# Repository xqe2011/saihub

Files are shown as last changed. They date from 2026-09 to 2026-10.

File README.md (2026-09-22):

<h1 align="center">
  SAIHub robot SAIHub
</h1>

<p align="center">
  counter
</p>

<p align="center"><strong>Give your agent a hand.</strong></p>

<p align="center">
  An MIT-licensed, agent-ready IO board.<br>
  ESP32-C5 firmware that speaks <a href="https://modelcontextprotocol.io/">MCP</a>,
  so Cursor, Claude Code, and Codex can drive real hardware.
</p>

<p align="center">
  <a href="README.zh.md">中文</a>
  · <a href="docs/cookbook.md">Cookbook</a>
  · <a href="docs/hardware.md">Hardware</a>
  · <a href="docs/design-notes.md">Protocol</a>
  · <a href="docs/build.md">Build</a>
  · <a href="https://github.com/xqe2011/saihub/releases">Releases</a>
  · <a href="LICENSE">MIT</a>
</p>

---

## What it is

SAIHub is a pocket IO companion for coding agents. Flash it, join Wi-Fi, paste an MCP URL, and the agent gets a hand on real hardware:

- **GPIO / PWM / programmable power** — toggle pins, generate PWM up to 50 kHz, capture edges like a logic analyzer, and switch the 3.3 V / 5 V rails on and off, all over MCP.
- **On-device scripting** — the agent can upload Lua scripts and run them on the board itself, so timing-critical or multi-step logic executes locally without a round-trip per pin.

The board is **SAIHub-Mini**: 48 × 28 mm, ESP32-C5, USB-C, a BOOT button, a 12-pin header, and an external U.FL antenna. Pinout and electrical details: [docs/hardware.md](docs/hardware.md). Firmware, KiCad design, and the relay server all live in this repo.

You do not have to use our board — the firmware runs on any ESP32-C5. See [bring your own board](docs/bring-your-own-board.md) for what changes and where to remap the GPIOs.

## What you can do with it

**Buy an agent a hand.** Drop SAIHub next to a DUT and let the agent debug a real embedded board: drive GPIO, generate PWM, capture traces, and speak UART instead of asking you to probe every line.

**An agent-ready IO board.** The simplest way to hang other IO off an agent:

- Sweep a **servo** from a Lua script while the agent watches the mechanism.
- Dim a **light** or blink a status LED over PWM.
- Close an **electromagnetic relay** to switch a pump, a lock, or a heater.
- Power a 3.3 V sensor from the switched rail, then read it over UART or GPIO.

## Quick start

The [cookbook](docs/cookbook.md) walks through every step:

1. Download the firmware `.bin` from [Releases](https://github.com/xqe2011/saihub/releases) and flash it with the [ESP web flasher](https://espressif.github.io/esptool-js/).
2. Click **BOOT** to open Wi-Fi pairing, join the `SAIHUB-xxxxxx` AP, and pick your network.
3. Point Cursor / Claude Code / Codex CLI at `http://<device-ip>/mcp`. The agent now has a hand on your bench.

## Ways to connect

The LAN URL is all you need at the bench. To reach the board from anywhere, put a relay in front of it — our managed cloud, or one you deploy yourself:

| | Local LAN | Self-hosted relay | Managed cloud |
| --- | --- | --- | --- |
| Best for | Bench work, zero setup | Remote access under your own account | Remote access, zero ops |
| MCP URL | `http://<device-ip>/mcp` | `https://<your-worker>/device/<digest>/mcp` | `https://saihub.xqe2011.com/device/<digest>/mcp` |
| Reach | Same LAN only | Anywhere | Anywhere |
| Setup | None after Wi-Fi | Deploy to Cloudflare then rebuild firmware with your origin ([details](docs/cookbook.md#5-self-host-the-cloudflare-relay)) | None — boards bought from us connect to the managed cloud |
| Auth | None (LAN trust) | OAuth through your relay | OAuth in the browser |
| Traffic path | Direct to the board | Through your Cloudflare account | Through our infrastructure |
| Cost | Free | Cloudflare free tier | Included with the board |

After the board authenticates with the relay, the serial log prints its landing page — `https://<origin>/cloud/landing/<digest>/page` — with live online status, copyable MCP or REST/OpenAPI URLs, and a button to mint a authentication token.

The relay protocol is server-agnostic — the Cloudflare Worker in this repo is the reference implementation ([design notes](docs/design-notes.md)).

## No vendor lock-in

Nothing here ties you to us:

- **Any ESP32-C5 board works.** SAIHub-Mini is just one carrier; an off-the-shelf DevKit or your own PCB runs the same firmware. See [bring your own board](docs/bring-your-own-board.md).
- **You don't need our managed cloud.** The relay is a Cloudflare Worker you can deploy under your own account — or replace entirely, since the protocol is documented and server-agnostic.
- **Everything is open source under MIT.** Firmware, KiCad hardware design, and the cloud relay all live in this repo.
- **LAN mode needs no service at all.** Wi-Fi plus the local MCP URL is a complete setup; the cloud is optional convenience, not a requirement.

## Capabilities

| Area | What the agent gets |
| --- | --- |
| GPIO 0–7 | Digital in / out / open-drain, pulse, PWM up to 50 kHz |
| Trace | Edge capture on one or more pins (up to 60 s) |
| UART | One product UART, UTF-8 or raw bytes |
| Power | Switched **3V3** and **5V** rails (off by default) |
| Scripts | Sandboxed Lua 5.4 on-device |
| Access | Streamable HTTP MCP on port 80, REST + OpenAPI, optional cloud relay |

Logic pins are **3.3 V only** — full electrical limits in [docs/hardware.md](docs/hardware.md).

## Repo layout

| Path | What |
| --- | --- |
| `main/` | ESP-IDF firmware (ESP32-C5, IDF ≥ 5.5) |
| `mcp.json` | MCP tool schema served by the device |
| `openapi.json` | REST API for the same tools |
| `cloud/cloudflare/` | Cloudflare Worker relay + OAuth (reference server) |
| `hardware/` | SAIHub-Mini KiCad project |
| `docs/` | Cookbook, hardware, build, protocol, and BYO-board docs |

## License

[MIT](LICENSE).

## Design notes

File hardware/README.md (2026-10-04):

# SAIHub-Mini — Rev A

Version: **2026-09-24**. Author: **GPT6-Astra**. Co-author: **xqe2011**.

The date version changes only with explicit user permission. See [the version log](docs/version-log.md); regeneration and exports preserve the approved version.

**Current state: routed and CAD-validated.** Electrical, layout, schematic-parity and connectivity checks pass. Prototype testing is still required.

Editable KiCad 10 design for the SAIHub IO controller. Open `saihub.kicad_pro`; symbols and footprints are project-local. The schematic is one A2 page with eight functional sections.

The PCB remains **48 × 28 mm**, with 65 footprints: 56 on top, eight resistors and the TP3 test pad on the back. Across the front edge, left to right: **12-pin header → BOOT button → USB-C**. Connector pins and the switch actuator project beyond the PCB outline.

SW1 is **TS-2435VS, C47734518**, a side-push switch without locating posts. Its local footprint follows the manufacturer's recommended stepped mounting lands and two electrical contacts. The actuator faces the connector edge.

The **16 × 24 mm module has a built-in PCB antenna at the bottom-left corner**. Its body spans x=0.85–16.85 mm and y=4–28 mm. An open notch removes the board beneath the antenna at y=20.5–28 mm and x=0–21.85 mm: it opens to the left and bottom edges and leaves **5 mm to the antenna's right**. The 0.85 mm body inset at the left preserves solder-land and copper-edge clearance beside the module's connected section. No board material or copper remains beneath the antenna. Enclosure clearance still needs verification.

The 5 V / 3 A input, nominal 1 A output protection, regulator and buzzer are retained. IO3 and IO7 now use internal pins 2 and 7; the firmware mapping changes with this board. Earlier hardware must use its matching firmware mapping.

## Files

- `saihub.kicad_pro`, `saihub.kicad_sch`, `saihub.kicad_pcb`: open the project in KiCad 10 to edit the current design.
- `libraries/`, `sym-lib-table`, `fp-lib-table`: project-local symbols and footprints required by KiCad.
- `docs/bom.csv`: current procurement BOM; excludes test pads; no external antenna accessory is required.
- `docs/bom.html`: self-contained interactive assembly BOM from [InteractiveHtmlBom](https://github.com/openscopeproject/InteractiveHtmlBom), with component lookup, MPNs, copper and net highlighting. Test pads are visible on the board but excluded from the BOM table.
- `docs/schematic.pdf`: schematic review.
- `docs/pcb.pdf`: top and mirrored bottom PCB previews, including silkscreen designators.
- `docs/shell.pdf`: enclosure previews with/without the board, dimensioned views and ABS mass estimate; refresh after every PCB change.
- `mechanical/`: editable build123d enclosure, board reference, STEP/STL exports and drawing generators; see [the mechanical guide](mechanical/README.md).
- `docs/version-log.md`: approved version and permission policy.
- `agent/`: regeneration scripts, design metadata, design notes, validation evidence, routing intermediates and reusable workflow skills.

Current validation and routing inputs are retained in Git. `agent/previews/` contains regenerable images and is ignored; the review PDFs are committed. KiCad local history, locks, backups and personal settings are also ignored.

**Prototype status:** CAD checks pass; the board has not been fabricated or bench tested. Verify thermal behavior, supply loading and USB operation using `agent/docs/prototype-test.md`. The 26.1 kΩ ILIM resistors set approximately 0.989 A nominal, with 0.908–1.081 A bounds including resistor tolerance; a guaranteed 1 A continuous rating is not implied.

## Connections

J2 pin 1 is square and marked `3V3`. Looking at the top with the connector edge at the top, pins run left to right:

`1:3V3_SW  2:GND  3:5V_SW  4:GND  5:IO0  6:IO1  7:IO2  8:IO3  9:IO4  10:IO5  11:IO6  12:IO7`

IO0-IO7 map to GPIO **10, 1, 0, 2, 4, 5, 6, 7**. Logic pins are **3.3 V only**; the 1 A setting applies to the two power channels. GPIO8 enables 3.3 V output and GPIO9 enables 5 V output. Both default off. Do not back-power either rail. The 5 V output follows USB voltage minus fuse, trace and switch losses.

Four LEDs form one top-side column, with matching shell openings and recessed labels:
**3V3 OUT** and **5V OUT** are green and monitor the switched outputs; **5V IN** is red
and monitors input power after the fuse; **STATUS** is blue and connects to control
pin 26 (active high). The blue indicator requires firmware control; no behavior is
assigned by this hardware change. R7-R10 and R19-R22 are assembled on the back.

GPIO12 drives the passive 5020 buzzer at 4 kHz / 50% duty. GPIO13/14 carry USB D-/D+. BOOT is GPIO28. TP1/TP2 are EN/GND reset pads on the top: briefly short them to reset. Hold BOOT during reset/power-on for download recovery. TP3 is UART TX on the back, TP4 always-on 3.3 V, and TP5/TP6 active-low switch fault outputs.

Use a specified **5 V / 3 A adapter and cable** for external loads. Keep outputs off on unqualified PC ports. No PD, OTG or source-current detection is implemented. The antenna is built into the module. See `agent/docs/design-notes.md` for SGM6232 input-voltage margin and sourcing status.

## Rebuilding

Normal edits can be made in KiCad. From the repository root, run:

```sh
export INTERACTIVE_HTML_BOM=/path/to/InteractiveHtmlBom/InteractiveHtmlBom/generate_interactive_bom.py
python3 hardware/agent/scripts/export_placement.py --routed
```

The command synchronizes board metadata, requires zero ERC/DRC/parity findings and zero unconnected items, then refreshes the five files in `docs/`, including `shell.pdf`. It requires KiCad 10, ImageMagick and Python `reportlab` (`python3 -m pip install reportlab`). Set `KICAD_CLI` and `KICAD_PYTHON` to override the macOS tool defaults; the latter must provide `pcbnew`. Poppler is optional for the separate schematic PNG. Clone [InteractiveHtmlBom](https://github.com/openscopeproject/InteractiveHtmlBom) and set `INTERACTIVE_HTML_BOM` as above (validated at commit `5c192e794cd66fde04bab11810601b711bf8581b`). On macOS, its generator requires a logged-in desktop session. `agent/scripts/export_ibom.py` can refresh only `docs/bom.html`.

`agent/scripts/export_docs.py` refreshes the review documents and the enclosure reference/exports, without modifying the board or schematic. It runs the enclosure geometry checks but does not replace electrical CAD validation. Install `mechanical/requirements.txt` into `mechanical/.venv`, or set `MECHANICAL_PYTHON` to that environment. Every PCB update requires reconciling the enclosure parameters and regenerating `docs/shell.pdf`; the document exporter calls `mechanical/refresh_shell.py` automatically and fails if that refresh fails. `agent/scripts/export.py` separately validates and exports fabrication files into `manufacturing/`.

For regeneration and routing, read [the project workflow skill](agent/skills/kicad-workflow/SKILL.md). `generate.py` writes the separate `agent/routing/saihub-unrouted.kicad_pcb`; it preserves the main routed PCB but regenerates the schematic and libraries while preserving existing project settings. The indicator layout uses `replay_routing.py` and its placement-checked copper snapshot; legacy SES routing is tied to the earlier placement.

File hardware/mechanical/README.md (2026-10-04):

# SAIHub-Mini enclosure

Parametric **build123d** base and cover for the current 48 × 28 × 1.6 mm board.
The cover uses a monochrome layout with a left-aligned Helvetica wordmark,
smaller MINI model line, and a blank QR sticker bed in the frame at upper right.
The top remains continuous over USB and the button, with four indicator openings nearby. USB and button access is through the side only
and no USB/button text labels.
All 12 connector labels share a baseline along the connector edge.
Each connector label is rotated 90° and centred on its physical 2.54 mm pin pitch,
so power and ground labels use the same column width as the numbers. All dimensions are in mm.

## Generate

From this directory, using Python 3.12:

```sh
python3.12 -m venv .venv
.venv/bin/python -m pip install -r requirements.txt
.venv/bin/python enclosure.py --preview
```

`output/` contains separate `base.step`, `cover.step`, `base.stl`, `cover.stl`,
an assembled `assembly.step`, a `fit-reference.step` with the populated board reference,
`validation.json`, and `preview.png`. The STEP and STL parts retain assembled
coordinates. Generate with `--output PATH` to select another export directory.

## Geometry

- Overall assembled envelope: **50.4 × 30.4 × 9 mm**.
- Ordinary side walls, floor, and cover face: **1 mm**.
- Exterior plan corners: **1.5 mm radius**, with matching nested profiles and a
  **0.3 mm** softened top perimeter. Wall dimensions describe straight sections;
  the top edge blend locally rounds the nominal roof thickness.
- The compact nesting joint uses a **1 mm cover lip** inside the **1 mm base
  wall**, with **0.2 mm** sliding clearance per side. It starts at **z = 6.5 mm**,
  above the board, with local edge-component clearance checked, instead of
  adding width beside the board.
- Lip overlap: **1 mm**; cover seats at **z = 7.5 mm**. Two opposed side snaps
  provide vertical retention with **0.25 mm** engagement and **0.2 mm** vertical
  play. Each free arm is **7.5 × 0.6 × 1.2 mm** with a ramped hook and **0.4 mm**
  clearance above it. Press the hooks through both side windows to release.
  Snap force, fatigue and print tolerances require prototype testing.
- Board side clearance: **0.2 mm**. The board rests **1.8 mm** above the floor for
  solder tails. Four short edge ledges support it, surrounding walls locate it,
  and ceiling fingers limit lift to **0.3 mm**. The board notch has no support below it.
- The footprint follows `48 + 2 × (1 + 0.2)` by `28 + 2 × (1 + 0.2)`.
  The smaller **1.5 mm** outer corner radius preserves clearance around the square
  board corners. The face layout is inset to suit the smaller shell.
- Component space above the PCB: **3.6 mm** to the continuous roof, apart from
  the nesting lip and edge fingers. The available USB model is taller than the
  stated 2.54 mm component height; its top has **0.295 mm** roof clearance.
  Body height is **9 mm**; the QR outline is recessed **0.3 mm**. The top is closed except for the four indicator openings,
  with **1 mm** nominal roof thickness and **0.7 mm** below recessed lettering.
- Bottom allowance is based on the available connector model: its tails extend
  about **1.405 mm** below the board, leaving approximately **0.395 mm** to the
  floor. Verify actual solder joints and trim tails if necessary.
- QR intaglio outline: **22.36 × 22.36 mm outside**, **22 × 22 mm square inside**, **0.18 mm wide
  along the straight edges and recessed 0.3 mm**, with rounded outer corners and
  **0.7 mm** of roof remaining below the groove. The border width matches the
  approximately 0.177 mm stems of the 1.8 mm regular lettering.
  The sticker bed is flat, flush with the cover face, and has no text. All labels are **recessed 0.3 mm**, leaving **0.7 mm** of roof below the lettering.

## Board alignment and prototype checks

Dimensions and connector locations come from `../saihub.kicad_pcb` and
`../agent/validation/parts-placement.csv`. The board is rotated in the face view
so that USB is on the left: board `(x, y)` becomes model `(48 - x, y)`.
The front connector edge is model `y = 0`; the base bottom is `z = 0`.
USB and button side-opening centres are **6.4 mm** and **14.7 mm** from the
left exterior edge. Their openings are **10.4 × 4.2 mm** and **5 × 3 mm**
respectively, with internal relief for the connector bodies. Neither opening
pierces the roof. The 12-contact header side opening is **31.5 × 3.9 mm**,
extending to the seam so no fragile strip remains above it on the base.
The pin labels remain recessed into the continuous roof above it.
The labels follow actual connector positions. Reading left to right in the cover
face view: **8, 7, 6, 5, 4, 3, 2, 1, GND, 5V, GND, 3.3V**. Channels **1–8**
correspond to the board's **IO0–IO7**; they are channel labels, not physical pin
numbers. Power and ground use the same 90° rotation as the numeric labels.

The generator checks solid validity, connectedness, shell-to-shell interference,
and interference with the actual notched board envelope. The exploded preview
also shows the populated board between the shell halves, in the same XY alignment.
`reference/pcb.step` is an export of the committed board with pads and available
component models. The button and module use explicitly named simplified envelopes
because their footprints have no supplied models; their heights are illustrative.
Other missing component models and solder are not reconstructed. This visual
reference is not a complete component-clearance certification. Before production, print a fit
sample and verify component heights, solder tails, edge finger clearance,
cable overmould access, mating-header clearance, button access, lid
retention, and wireless operation. Use nonconductive plastic.

Print the base floor down. The cover has recessed details on its flat top face and lips/snaps underneath;
choose supports and orientation in the slicer to preserve the engraved details. Start with a fine layer height for the small
labels. The preview is rendered directly from the generated solids in neutral
grey, with darker recessed lettering and frame for legibility; it does not specify separate print colours.

To refresh the board reference after board edits, from this directory:

```sh
kicad-cli pcb export step --force --subst-models --include-pads --user-origin 0x0mm \
  -o reference/pcb.step ../saihub.kicad_pcb
.venv/bin/python enclosure.py --preview
```

The exporter uses board-bottom `z=0` and negated board Y. The generator rotates
it 180° around Z and translates it to `(48, 0, 2.8)` to match the enclosure.

Build123d export API reference:
[Import/Export](https://build123d.readthedocs.io/en/latest/import_export.html).

## Dimensioned PDF

The hardware review document `../docs/shell.pdf` contains exploded previews with and
without the PCB, top/front/right views with dimensions, and an ABS mass estimate.
Regenerate it after changing the enclosure:

```sh
.venv/bin/python render_shell_docs.py --output /tmp/saihub-shell-pdf
.venv/bin/python export_shell_pdf.py --assets /tmp/saihub-shell-pdf
```

The drawing uses a 3:1 orthographic scale when printed at 100%. Dimensions govern.
The PDF recomputes the ABS mass from current CAD material volumes at **1.04 g/cm3**,
using the linked manufacturer data sheet. Filled thin walls are assumed; supports,
brim, purge, electronics and sticker are excluded. Confirm consumption with the
intended slicer settings.

## Required refresh after PCB changes

The canonical PDF is **`hardware/docs/shell.pdf`**, never the repository-level
`docs/shell.pdf` or `hardware/shell.pdf`. PCB edits require checking the explicit
board dimensions, connector centres/heights, supports, snap paths and illustrative
component envelopes in `enclosure.py`; these do not adapt automatically to a new
board layout. Update drawing callouts if the geometry changes.

After reconciling those inputs, from this directory run:

```sh
.venv/bin/python refresh_shell.py
```

This exports a fresh board reference, regenerates the enclosure exports/preview,
checks board/component and snap insertion geometry, regenerates all drawing views,
and recomputes the mass in `../docs/shell.pdf`. A failure stops the refresh instead
of publishing a new PDF. `--pdf-python /path/to/python` may select a separate
Python environment with ReportLab. `KICAD_CLI` selects the board export executable.
The hardware document exporter invokes this command automatically; select its
CAD environment with `MECHANICAL_PYTHON` if not using `mechanical/.venv`.

Render every page of the resulting PDF and visually inspect the images before
reporting completion. Geometry checks do not validate missing models, solder,
material strength or printed snap retention. Do not change board revision/date
metadata just to refresh these documents.

## Indicator bank

The four top-side LEDs remain together at board x=30.3 mm, y=5.2/8.4/11.6/14.8 mm.
The shell takes these positions directly from `agent/design.json`. Each has a
1.5 mm circular viewing opening and a separate 2.2 mm outside-diameter light well,
with 0.4 mm clearance above the nominal 0.55 mm LED body. Recessed labels read
`3V3 OUT`, `5V OUT`, `5V IN`, and `STATUS`; the first two are green, then red and blue.
The QR sticker area remains blank. The eight bottom resistors fit inside the
existing solder-tail allowance. Verify visibility, light bleed and resistor/solder
clearance on a physical prototype.

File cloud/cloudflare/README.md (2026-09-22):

# SAIHub cloud relay

Cloudflare Worker that proxies MCP and REST to a SAIHub board.

Deploy to Cloudflare (https://deploy.workers.cloudflare.com/?url=https://github.com/xqe2011/saihub/tree/main/cloud/cloudflare)

Deploy provisions D1 (`DB`), the `DEVICE` Durable Object, `AUTH_TIMEOUT_MS` / `REQUEST_TIMEOUT_MS`, and the `ROUTING_TOKEN_SECRET` / `ADMIN_TOKEN` secrets from `.dev.vars.example`. Generate each secret with `openssl rand -hex 32`. The deploy script applies D1 migrations, then publishes the worker.

Local development:

```bash
cp .dev.vars.example .dev.vars
npm install
npm run dev
```

Then open `/admin` on the worker origin, enter `ADMIN_TOKEN`, and whitelist each device digest.

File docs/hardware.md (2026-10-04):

# SAIHub-Mini hardware

> **Tip:** Experimental board designed by GPT-6 Astra; still under evaluation. Use at your own risk.

A 48 × 28 mm, two-layer IO board: USB-C, one BOOT button, a 12-pin right-angle header, and a built-in PCB antenna. The main components and four indicators are on top; eight resistors are assembled on the back.

[中文](hardware.zh.md) · [README](../README.md) · [Cookbook](cookbook.md) · [Bring your own board](bring-your-own-board.md) · [KiCad project](../hardware/README.md)

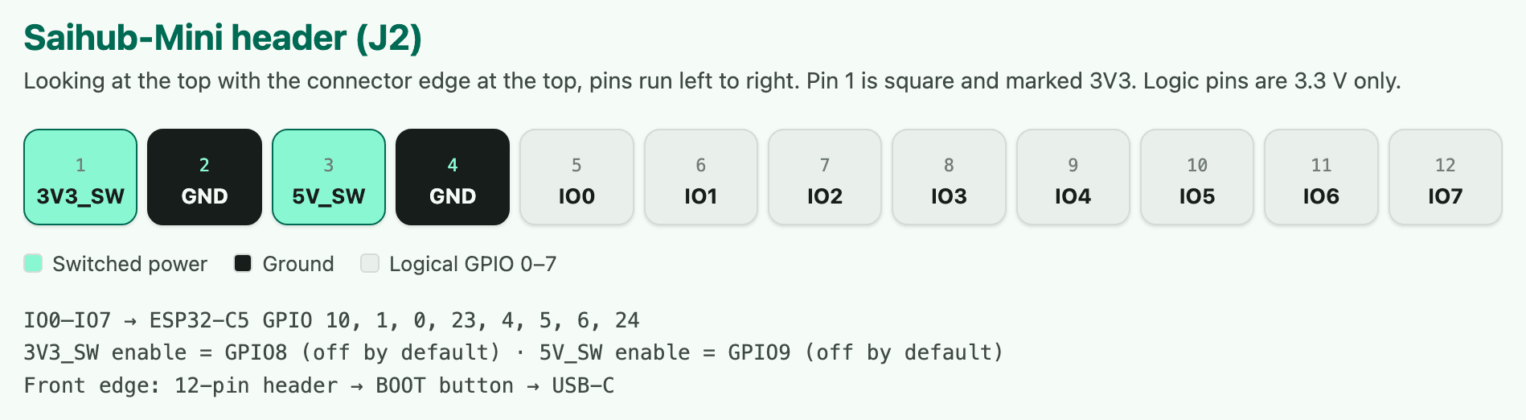
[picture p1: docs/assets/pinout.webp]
SAIHub-Mini J2 header pinout


## Front edge

Left to right: **12-pin header (J2) → BOOT button → USB-C**. The board width follows these three footprints plus assembly clearances; the connector pins and switch actuator project beyond the outline.

## J2 pinout

Pin 1 is square and marked `3V3`. Looking at the top with the connector edge up, pins run left to right:

| Pin | Name | Internal pin | Notes |
| --- | --- | --- | --- |
| 1 | 3V3_SW | — | Switched 3.3 V output, enabled by GPIO8, **off by default** |
| 2 | GND | — | |
| 3 | 5V_SW | — | Switched 5 V output, enabled by GPIO9, **off by default** |
| 4 | GND | — | |
| 5 | IO0 | GPIO10 | 3.3 V logic |
| 6 | IO1 | GPIO1 | 3.3 V logic |
| 7 | IO2 | GPIO0 | 3.3 V logic |
| 8 | IO3 | GPIO2 | 3.3 V logic |
| 9 | IO4 | GPIO4 | 3.3 V logic |
| 10 | IO5 | GPIO5 | 3.3 V logic |
| 11 | IO6 | GPIO6 | 3.3 V logic |
| 12 | IO7 | GPIO7 | 3.3 V logic |

Agents drive these through the MCP / REST tools; the mapping lives in firmware `CONFIG_GPIO_LOGICAL_TO_HW` (`main/include/config.h`).

## Power

- **Input**: 5 V / 3 A over USB-C, protected by a 3 A fast fuse and TVS. No PD, no OTG, no source-current detection — just 5.1 kΩ CC pulldowns.
- **3.3 V rail**: SGM6232 buck converter; also feeds an always-on 3.3 V at TP4.
- **Switched outputs**: two TPS2553 power switches feed **3V3_SW** and **5V_SW**. GPIO8 / GPIO9 enable them; both default off and the agent toggles them with `set_output_power_state`.
- **Output protection**: 26.1 kΩ ILIM resistors set a nominal ~1 A limit per channel (0.989 A calculated, 0.908–1.081 A including resistor tolerance). This is a protection threshold, **not a guaranteed continuous 1 A rating**.
- **5V_SW** follows the USB input voltage minus fuse, trace, and switch losses.
- Use a **5 V / 3 A adapter and cable** for external loads; keep outputs off on unqualified USB ports.

## Electrical rules

- Logic pins are **3.3 V only**.
- **Do not back-power** either switched rail.
- Mains voltage belongs on external relay contacts only — never on SAIHub pins.

## Button and test points

| Item | Function |
| --- | --- |
| BOOT (SW1, GPIO28) | Click once while running: Wi-Fi pairing. Hold during reset / power-on: ROM download mode |
| TP1 / TP2 | EN / GND reset pads (top). Short briefly to reset |
| TP3 | Console UART TX (GPIO11, 115200 baud), back-side test pad — firmware logs |
| TP4 | Always-on 3.3 V |
| TP5 / TP6 | Active-low fault outputs of the two power switches |

SW1 is TS-2435VS (C47734518), a side-push switch without locating posts. The actuator faces the connector edge.

## UART

- UART0 is reserved for the console (logs on TP3).
- The product UART exposed to agents is UART1, routed through the GPIO matrix to any of IO0–IO7 and configured at runtime with `configure_uart`.

## Other onboard parts

- Four indicators in one column: green **3V3 OUT** and **5V OUT** monitor switched outputs, red **5V IN** monitors input power after the fuse, and blue **STATUS** connects to control pin 26. STATUS requires firmware control; this hardware change assigns no behavior.
- Passive 5020 buzzer on GPIO12 (driven at 4 kHz / 50 % duty).
- Native USB on GPIO13 / GPIO14 (D- / D+), with USBLC6-2SC6 ESD protection.
- 16 × 24 mm module with built-in PCB antenna and 4 MB flash.

## Antenna

The built-in antenna sits at the bottom-left corner, above an open board cutout. The cutout reaches the left and bottom edges and extends 5 mm to the antenna’s right. Overall PCB dimensions stay 48 × 28 mm. IO3 and IO7 use new internal pin assignments; use the firmware mapping committed with this board.

## Design files and status

KiCad 10 project, procurement BOM, schematic, PCB and enclosure review PDFs: [`hardware/`](../hardware/README.md). Editable enclosure models and STEP/STL exports are in [`hardware/mechanical/`](../hardware/mechanical/README.md).

**Prototype status**: the replacement layout passes CAD checks; it has not been fabricated or bench tested. Thermal behavior, supply loading, and USB operation still need verification — see `hardware/agent/docs/prototype-test.md`.

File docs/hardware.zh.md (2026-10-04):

# SAIHub-Mini 硬件文档

> **提示：** 本板由 GPT-6 Astra 设计，目前仍在测试中，请自行承担使用风险。

一块 48 × 28 mm 的双层 IO 板：USB-C 接口、一个 BOOT 按键、一排 12 针直角排针，内置 PCB 天线。主要元件和四个指示灯位于顶层，八个电阻贴装在背面。

[English](hardware.md) · [README](../README.zh.md) · [使用手册](cookbook.zh.md) · [自备开发板](bring-your-own-board.zh.md) · [KiCad 工程](../hardware/README.md)

SAIHub-Mini J2 排针定义

## 板子前缘

从左到右依次是：**12 针排针（J2）→ BOOT 按键 → USB-C**。板宽由这三个器件加装配间隙决定；排针和按键帽会超出板框。

## J2 引脚定义

第 1 脚为方孔焊盘，丝印标注 `3V3`。俯视板子、排针朝上时，引脚从左到右依次为：

| 引脚 | 名称 | Internal pin | 说明 |
| --- | --- | --- | --- |
| 1 | 3V3_SW | — | 可控 3.3 V 输出，GPIO8 使能，**默认关闭** |
| 2 | GND | — | |
| 3 | 5V_SW | — | 可控 5 V 输出，GPIO9 使能，**默认关闭** |
| 4 | GND | — | |
| 5 | IO0 | GPIO10 | 3.3 V 逻辑电平 |
| 6 | IO1 | GPIO1 | 3.3 V 逻辑电平 |
| 7 | IO2 | GPIO0 | 3.3 V 逻辑电平 |
| 8 | IO3 | GPIO2 | 3.3 V 逻辑电平 |
| 9 | IO4 | GPIO4 | 3.3 V 逻辑电平 |
| 10 | IO5 | GPIO5 | 3.3 V 逻辑电平 |
| 11 | IO6 | GPIO6 | 3.3 V 逻辑电平 |
| 12 | IO7 | GPIO7 | 3.3 V 逻辑电平 |

智能体通过 MCP / REST 工具操作这些引脚；映射关系固化在固件的 `CONFIG_GPIO_LOGICAL_TO_HW`（`main/include/config.h`）中。

## 电源

- **输入**：USB-C 5 V / 3 A，前端有 3 A 快断保险丝和 TVS 保护。不支持 PD、OTG，也没有源电流检测，CC 脚只接了 5.1 kΩ 下拉。
- **3.3 V 主电源**：SGM6232 降压芯片；TP4 上还有常供电的 3.3 V。
- **可控输出**：两路 TPS2553 电源开关分别驱动 **3V3_SW** 和 **5V_SW**，由 GPIO8 / GPIO9 使能。默认都是关闭的，智能体用 `set_output_power_state` 工具开关。
- **输出保护**：ILIM 电阻 26.1 kΩ，每路限流标称约 1 A（计算值 0.989 A，计入电阻公差为 0.908–1.081 A）。这是保护阈值，**不保证能持续输出 1 A**。
- **5V_SW** 电压等于 USB 输入电压减去保险丝、走线和开关的压降。
- 带实际负载时请使用 **5 V / 3 A 的适配器和线缆**；接入不确定的 USB 口时，先关闭电源输出。

## 电气红线

- 逻辑引脚**仅支持 3.3 V**。
- **禁止**从外部向任一可控电源轨倒灌。
- 市电只能走外接继电器的触点，绝不能接到 SAIHub 引脚上。

## 按键与测试点

| 位置 | 功能 |
| --- | --- |
| BOOT（SW1，GPIO28） | 运行中按一下：开启 Wi-Fi 配对；复位 / 上电时按住：进入 ROM 下载模式 |
| TP1 / TP2 | EN / GND 复位焊盘（板顶），短接一下即复位 |
| TP3 | 背面测试点，控制台 UART TX（GPIO11，115200 波特率），输出固件日志 |
| TP4 | 常供 3.3 V |
| TP5 / TP6 | 两路电源开关的低有效故障输出 |

SW1 采用 TS-2435VS（C47734518），无定位柱，侧按，朝向接口边缘。

## UART

- UART0 保留作控制台（日志从 TP3 输出）。
- 提供给智能体的产品 UART 是 UART1，经 GPIO 交换矩阵可以路由到 IO0–IO7 中任意两脚，运行时用 `configure_uart` 配置。

## 其他板载器件

- 四个指示灯排成一列：绿色 **3V3 OUT** 和 **5V OUT** 监测可控输出，红色 **5V IN** 监测保险丝后的输入电源，蓝色 **STATUS** 连接控制引脚 26。STATUS 需要固件控制，本次硬件变更未定义其行为。
- GPIO12 驱动 5020 无源蜂鸣器（4 kHz / 50% 占空比）。
- 原生 USB 走 GPIO13 / GPIO14（D- / D+），带 USBLC6-2SC6 ESD 保护。
- 16 × 24 mm 模组，内置 PCB 天线，4 MB Flash。

## 天线

内置天线位于左下角，天线下方挖空，缺口连通左边和底边，并向天线右侧延伸 5 mm。PCB 外形尺寸仍为 48 × 28 mm。IO3 和 IO7 的内部引脚映射已更新，请使用与本板配套的固件映射。

## 设计文件与状态

KiCad 10 工程、采购 BOM、原理图、PCB 和外壳审阅 PDF 见 [`hardware/`](../hardware/README.md)。可编辑外壳模型及 STEP/STL 导出文件见 [`hardware/mechanical/`](../hardware/mechanical/README.md)。

**打样状态**：更换器件后的布局已通过 CAD 检查，尚未打样和上电实测。热性能、供电负载和 USB 工作情况还需验证，详见 `hardware/agent/docs/prototype-test.md`。

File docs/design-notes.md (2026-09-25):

# Cloud relay protocol — design notes

The wire protocol between a SAIHub device and a cloud relay server. The protocol is **server-agnostic**: the device only needs a WebSocket endpoint and the message contract below. The current reference implementation is a Cloudflare Worker with one Durable Object per device ([`cloud/cloudflare/src/`](../cloud/cloudflare/src/)); the firmware side lives in [`main/src/cloud.c`](../main/src/cloud.c) and [`main/include/cloud.h`](../main/include/cloud.h).

User-facing setup: [cookbook §5](cookbook.md#5-self-host-the-cloudflare-relay).

## Topology

```
MCP client ──HTTPS──▶ Relay server ──internal──▶ per-device state ◀──WebSocket── ESP32-C5
                        (routing, OAuth)                              (outbound dial)
```

The device always dials out; no inbound connections or port forwarding are needed. The relay keeps per-device state keyed by the device digest, owns the single WebSocket to that board, and multiplexes client HTTP requests over it. In the reference implementation that state is a `Device` Durable Object addressed by `idFromName(digest)`.

### What any relay server must provide

- WebSocket endpoint at `<origin>/cloud/device/<digest>` (upgrade required, no bearer auth — the device proves key ownership during the handshake).
- Client HTTP surface at `<origin>/device/<digest>/<path>` guarded by a routing token bound to that digest, JSON-only.
- The auth handshake, request/response message contract, limits, heartbeat eviction, and timeouts described below.
- OAuth endpoints for MCP clients (metadata, register, token, browser pairing page) per the MCP authorization spec.

## Device identity

- **Key**: ECDSA P-256 key pair. The private key is provisioned into an ESP32-C5 eFuse key block (`ESP_EFUSE_KEY_PURPOSE_ECDSA_KEY`) on first boot if none exists: generated from the RNG (bootloader entropy source, warmed up and discarded), validated through PSA import, then written little-endian via `esp_efuse_write_key`. This is **irreversible**; the block is read- and write-disabled afterwards and the key can only be used through the hardware ECDSA peripheral.
- **Public key**: SEC1 uncompressed point, 65 bytes (`0x04 || X || Y`).
- **Digest (device id)**: `Base58Check(SHA-256(publicKey)[0..20])` — 20-byte payload plus a 4-byte checksum `SHA-256(SHA-256(payload))[0..4]`, Bitcoin alphabet. 26–33 characters (`DIGEST_RE` in `protocol.ts`). The digest is the board's public address, not a secret.
- **Signing**: deterministic ECDSA (RFC 6979, `PSA_ALG_DETERMINISTIC_ECDSA(SHA_256)`) over `SHA-256(M)` where `M = UTF8("saihub/cloud-auth/v1") || 0x00 || challenge`. Signature is raw `r || s`, 64 bytes. The domain-separation prefix is `CLOUD_AUTH_DOMAIN` (firmware) / `AUTH_DOMAIN_PREFIX` (worker).
- Firmware logs the public key (hex) and digest at boot; a factory self-test signs and verifies a random challenge right after provisioning.

## Transport and connection lifecycle

- Firmware origin: `CONFIG_CLOUD_URL` in [`main/include/config.h`](../main/include/config.h) (`ws://` or `wss://`, no path; empty disables the relay). The device connects to `<origin>/cloud/device/<digest>` using `esp_websocket_client` with the cert bundle, 2048-byte buffer, 10 s network timeout, 3 s reconnect backoff.
- The relay task only runs while **Wi-Fi connected, not pairing, and NTP synced** (TLS verification needs valid time). Any protocol violation sets a restart flag: the socket is stopped under the send mutex, the generation counter is bumped, and the task re-dials after 3 s.
- **One connection per digest**: a second WebSocket while one is live must be rejected (reference: `409 device already connected`).
- **Heartbeat**: the firmware sends the text frame `ping` every 10 s and ignores `pong`. The relay should answer `ping` with `pong` (reference: edge-level `setWebSocketAutoResponse`, no object wake-up) and evict a socket after **33 s** of silence (`HEARTBEAT_TIMEOUT_MS`), rejecting all pending requests with 503.
- **Auth timeout**: if authentication is not complete within `AUTH_TIMEOUT_MS` (default 10 s), close the socket (reference: DO alarm, close 1008).
- All protocol messages are **JSON text frames**. The firmware reassembles fragments up to `CONFIG_CLOUD_MAX_MESSAGE_BYTES` (72 KB) and queues at most 8 complete messages for the relay task.
- The reference DO is hibernation-friendly: socket and auth state persist via `serializeAttachment` (`{connectedAt, digest, authenticated, challenge}`) and are restored from `ctx.getWebSockets()` after eviction.

## Authentication handshake

Immediately after accepting the socket, the relay sends:

```json
{ "type": "authRequest", "challenge": "<base64url, 32 random bytes>" }
```

The device answers (challenge must be exactly 43 base64url chars = 32 bytes):

```json
{
  "type": "authResponse",
  "devicePublicKey": "<base64url, 65 bytes>",
  "devicePublicKeyDigest": "<Base58Check digest>",
  "version": "<firmware app version, ≤64 chars>",
  "response": "<base64url, 64-byte signature>"
}
```

Verification (`verifyDeviceAuth` in `crypto.ts`), in order:

1. `devicePublicKeyDigest` equals the digest from the WebSocket URL.
2. `devicePublicKey` decodes to 65 bytes starting with `0x04`.
3. Recomputed `publicKeyDigest(devicePublicKey)` equals the expected digest.
4. ECDSA-P256/SHA-256 signature valid over `"saihub/cloud-auth/v1\0" || challenge`.

Result:

```json
{ "type": "authResult", "success": true }
{ "type": "authResult", "success": false, "reason": "…" }
```

On failure the relay closes the socket (reference: code 1008); the firmware treats rejection as a restart trigger. Messages from an unauthenticated socket other than `authResponse` are refused (`not authenticated`). Stale sockets (not the current one) are closed with 1008 `stale connection`.

## Request / response relay

### Client-facing HTTP surface

- Route: `https://<origin>/device/<digest>/<path>`, guarded by `Authorization: Bearer <routingToken>` whose sealed `devicePublicKeyDigest` must match the URL digest.
- **JSON only**: if a content-type or non-empty body is present it must be `application/json`; `Accept` must permit JSON; violations get 415/406. The device enforces the same rule on its side.
- `GET` / `DELETE` on `/device/<digest>/mcp` are rejected with `405 Allow: POST, OPTIONS` — the relay does not carry SSE streams, so MCP works in Streamable-HTTP POST mode only.
- The reference worker forwards to its DO as `https://device/proxy?path=<path+query>`.
- After a successful `authResponse`, the DO stores the firmware `version` on the socket attachment. `GET /openapi.json` and MCP `tools/list` first query D1 `file_cache` for that version and filename (`openapi.json` / `mcp.json`). A hit returns immediately: OpenAPI as the stored JSON bytes; `tools/list` as `{"jsonrpc":"2.0","result":<mcp.json>,"id":<request id>}`. `mcp.json` is the result object (`{"tools":[...]}`), not a JSON-RPC envelope. A miss keeps the existing device proxy. Operators upload rows through `POST /admin/file-cache` `{version, filename, content}` (`filename` is `mcp.json` or `openapi.json`). A git tag runs the firmware-release workflow, which POSTs the tagged commit’s `mcp.json` and `openapi.json` when GitHub Environment `cloud` has var `ADMIN_URL` and secret `ADMIN_TOKEN`; otherwise the upload is skipped. The cache `version` is the tag name, matching firmware `version.txt`.

### Relay → device message

```json
{
  "type": "request",
  "requestId": "<hex seq>-<base64url 8 random bytes>",
  "method": "POST",
  "path": "/mcp",
  "headers": { "content-type": "application/json", "…": "…" },
  "body": { },
  "grantSecret": "<32 URL-safe chars>"
}
```

- `grantSecret` is a top-level envelope field (not inside `body`). The relay copies it from the unsealed routing token. The device returns 401 `{reason:"grantSecret not found"}` unless that secret is stored in NVS.
- Header allowlist (`FORWARDED_HEADERS`): `content-type`, `accept`, `x-lock-id`, `mcp-protocol-version`, `mcp-session-id`, `origin`.
- Limits: path ≤ 1024 chars and must start with `/`; body ≤ 64 KB (`MAX_BODY_BYTES`), must be a JSON object or null; ≤ 16 headers, name ≤ 64 chars, value ≤ 512 chars.
- **Headroom**: at most 8 in-flight requests per device (`MAX_PENDING_REQUESTS`); further requests wait in a FIFO queue. The device timeout (`REQUEST_TIMEOUT_MS`, default 55 s) starts **only when a request is admitted**, so queued requests do not time out early; queued fetches keep the reference DO awake.

### Device → relay response

```json
{
  "type": "response",
  "requestId": "<echoed>",
  "status": 200,
  "headers": { "content-type": "application/json" },
  "body": { }
}
```

- The device dispatches the request through the **same route table as its local HTTP server** (`HttpServer_DispatchCloud`), so cloud and LAN behavior are identical. All API routes registered outside Wi-Fi pairing are cloud-exposed.
- Large responses are **streamed as one fragmented WebSocket text message**: `HTTP_CLOUD_BEGIN` sends a partial frame, `HTTP_CLOUD_CHUNK` continuation frames, `HTTP_CLOUD_END` the FIN. A send mutex plus a single stream owner serializes fragmentation; a connection-generation counter aborts stale writers across reconnects (`HTTP_CLOUD_ABORT` triggers a relay restart).
- Relay-side validation (reference `device.ts`): status integer 200–599; serialized body ≤ 1 MB; if a body is present, `content-type` must be JSON; `204/205/304` must carry `body: null`; `content-length` and `transfer-encoding` are stripped before responding to the client.
- Error mapping: device offline / socket lost ⇒ 503 `device offline`; admitted request not answered in time ⇒ 504 `device timeout`; malformed device response ⇒ 502.

## Pairing and routing tokens

The bearer token used by MCP clients is a **routing token**: AES-256-GCM over the JSON `{devicePublicKeyDigest, grantSecret}`, key = `SHA-256(ROUTING_TOKEN_SECRET)`, random 12-byte IV, encoded `base64url(iv || ciphertext || tag)` (`sealRoutingToken` / `openRoutingToken`). The secret is relay-side configuration (reference: a Wrangler secret); alternative servers can use any equivalent sealed-token scheme as long as the token binds a client grant to one digest.

OAuth (MCP authorization) is implemented by the relay:

- `/.well-known/oauth-authorization-server` — metadata: authorization endpoint `/cloud/oauth/redirect`, token endpoint `/token`, registration endpoint `/register`, `authorization_code` + PKCE `S256`, token auth `none`.
- `/register` — returns a static client (`saihub-static-client`), echoing requested redirect URIs.
- `/.well-known/oauth-protected-resource[/device/<digest>/mcp]` — RFC 9728 metadata; 401s carry `WWW-Authenticate: Bearer … resource_metadata=…`.
- `/token` — `grant_type=authorization_code`, `code=<routingToken>`; the seal is validated and the same string is returned as `access_token` (`expires_in` declared as 10 years).

Browser pairing flow (`/cloud/oauth/redirect`, page served by `oauth.ts`):

1. The page asks for a client **name** (1–32 characters), then `POST /cloud/pairing/session` with `{devicePublicKeyDigest, name}`.
2. The relay sends a WebSocket `pairingSessionRequest` `{name}` (no `requestId`; not `type: "request"` / not HTTP `/pairing/*`). The device keeps **one** RAM session (`name`, `expiredAt`) and replies `pairingSessionResponse` with `{sessionToken, expiredAt}`. The Durable Object stores the latest `sessionToken` and TTL. A second session while TTL is live is 409 `a pairing session is already active`. A full grant table (16) is 422 `grant secret limit reached (16)`.
3. The page hides the name field and shows **Hold BOOT for 3 seconds** plus “This approval will create grant `name`.” That hold is valid as soon as the session exists. `POST /cloud/pairing/token` is answered by the Durable Object: it matches `sessionToken` against the stored value (401 `session token is invalid or expired` on mismatch or TTL) and holds concurrent waiters until the device approves. The device does not see token waiters.
4. After approval the device mints one 32-character `grantSecret`, stores a C struct array of `{createdAtUs, name, grantSecret}` as an NVS blob (`cloud.grants`), and sends a single unsolicited `pairingSessionTokenResponse`. The Durable Object stores that secret, broadcasts it to waiters, and serves later `/pairing/token` calls with the same secret until TTL. `GET /cloud/grant-secrets` returns `createdAt` in microseconds.
5. The relay seals `{devicePublicKeyDigest, grantSecret}` into a routing token and redirects to `redirect_uri?code=<routingToken>&state=…`.

Grant list/revoke on the device: `GET /cloud/grant-secrets`, `DELETE /cloud/grant-secrets/{grantSecret}` (LAN or cloud). The human control UI has a Cloud tab.

`grantSecret` is `base64url` of 24 random bytes (32 `[A-Za-z0-9_-]` characters).

## Landing page (reference worker)

Public HTML for humans, no bearer token. Firmware logs this URL after a successful `authResult` (`http` + `CONFIG_CLOUD_URL` without the leading `ws`).

- `GET /cloud/landing/<digest>/page` — MCP URL (`/device/<digest>/mcp`) split from REST base (`/device/<digest>`) and `openapi.json` with **OR**. REST has **Get routing token**, which starts `/cloud/oauth/redirect` with `redirect_uri=/cloud/oauth/echo`. The page polls `/online`.
- `GET /cloud/oauth/echo` — OAuth callback HTML. Reads `code` from the query string and shows the routing token with a copy button.
- `GET /cloud/landing/<digest>/online` — `{ "online": true | false }`. Online means an authenticated WebSocket is currently attached to that digest (heartbeat still valid). Unauthenticated or disconnected sockets are offline.

These routes do not grant API access. MCP and REST still require a routing token.

## Device-side implementation notes (`main/src/cloud.c`)

- One FreeRTOS task (`cloud-relay`, 6 KB stack) owns receive parsing and dispatch; sends from HTTP handlers go through `Cloud_Write` under a mutex.
- Receive path: fragments (opcodes 0/1) are reassembled; control frames may interleave. Oversize or malformed buffers trigger a relay restart. Each queued message carries the connection generation; stale messages are dropped.
- Message handling: `pong` is ignored; `authRequest` is answered only while unauthenticated; `authResult` sets the authenticated flag; `pairingSessionRequest` runs in `cloud.c` (no `requestId`); holding BOOT sends one unsolicited `pairingSessionTokenResponse`; `request` is dispatched synchronously on the relay task (cloud-side timeouts bound the work) after `grantSecret` is checked.
- Requests arriving during Wi-Fi pairing or with the API server down get `503 device API unavailable` from the device itself.

## Constants

| Constant | Value | Where |
| --- | --- | --- |
| Challenge size | 32 bytes | `CHALLENGE_BYTES` |
| Public key / signature | 65 / 64 bytes | `PUBLIC_KEY_BYTES`, `SIGNATURE_BYTES` |
| Digest | 20-byte payload + 4-byte checksum, Base58Check | `DIGEST_PAYLOAD_BYTES`, `DIGEST_CHECKSUM_BYTES` |
| Max device WS message (firmware) | 72 KB | `CONFIG_CLOUD_MAX_MESSAGE_BYTES` |
| Max proxied request body | 64 KB | `MAX_BODY_BYTES` |
| Max device response body | 1 MB (serialized) | reference `device.ts` |
| Max path / headers / name / value | 1024 / 16 / 64 / 512 | `MAX_PATH_LEN`, `MAX_HEADERS`, … |
| In-flight requests per device | 8 | `MAX_PENDING_REQUESTS` |
| Heartbeat interval / timeout | 10 s / 33 s | firmware timer / `HEARTBEAT_TIMEOUT_MS` |
| Auth timeout | 10 s default | `AUTH_TIMEOUT_MS` |
| Request timeout | 55 s default | `REQUEST_TIMEOUT_MS` |
| Device firmware queue | 8 messages | `xQueueCreate(8, …)` |

## Security considerations

- The private key never leaves the eFuse key block; all signing goes through the hardware ECDSA peripheral with deterministic nonces (no RNG reuse risk).
- Domain separation (`saihub/cloud-auth/v1\0`) prevents cross-protocol signature reuse.
- Possession of the digest alone grants nothing: the WebSocket requires a valid challenge signature, and client HTTP requires a sealed routing token bound to that digest.
- Routing tokens double as OAuth codes and long-lived bearer tokens; rotating the relay secret invalidates all of them at once.
- The relay is JSON-only and strips hop-by-hop headers, which keeps the proxy surface small but rules out SSE/binary streaming until revisited.

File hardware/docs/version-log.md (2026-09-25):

# SAIHub-Mini version log

- Board: **SAIHub-Mini**
- Revision: **Rev A**
- Version: **2026-09-24**
- Author: **GPT6-Astra**
- Co-author: **xqe2011**

## Version policy

Change the revision or date version only with explicit permission from xqe2011. Ordinary edits, regeneration, routing, validation and document exports must preserve the approved version. Do not derive the version from the current date automatically.

The approved identity is stored in `../agent/identity.json`. When a version change is authorized, update that file, the CAD labels/title block, generated metadata and review documents together, then append a dated entry here with the authorized version and a concise description of the change.

## 2026-09-18 — Rev A baseline

Authorized by xqe2011 in the request to name this board SAIHub-Mini and establish Rev A. Set the initial date version to 2026-09-18. Added top silkscreen with the name, revision, version and author/co-author names. Established GPT6-Astra as author and xqe2011 as co-author. Removed obsolete revision resources and documentation.

## 2026-09-24 — Rev A documentation and silkscreen

Authorized by xqe2011. Retained Rev A and updated the date version to 2026-09-24. Added visible component designators to top silkscreen, refreshed PCB/schematic review PDFs and added the compiled InteractiveHtmlBom `bom.html`.

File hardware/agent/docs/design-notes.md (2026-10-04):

# SAIHub-Mini Rev A design review

Version: 2026-09-24. Author: GPT6-Astra. Co-author: xqe2011.
Version updates require explicit user permission; record each approved change in `../../docs/version-log.md`.

**Current layout:** module and button replacement on the unchanged 48 × 28 mm envelope. There are 56 top footprints, eight back-side resistors and one back-side test pad (TP3). All four LEDs remain on top. The final reports describe this placement.

## Requirements and mechanical envelope

The front edge retains J2, SW1 and J1 from left to right. SW1 is TS-2435VS, procurement code C47734518. Its [manufacturer drawing](https://atta.szlcsc.com/upload/public/pdf/source/20250414/8774CEBD0F324351C3CF1F5D7421BC0B.pdf) specifies two 0.6 × 1.2 mm contact lands on 3.4 mm centres, plus two stepped mechanical anchors: 5.3 mm outer span, 3.2 mm inner gap and 1.3 mm depth. There is a 0.7 mm gap between anchor and contact rows. Mounting anchors remain electrically unconnected. The selected variant has no locating posts.

The new module has a built-in antenna and a 16 × 24 mm body. The [manufacturer drawing, pages 9–10](https://atta.szlcsc.com/upload/public/pdf/source/20251016/3D572157C42EA1AA3992B58D4700E12F.pdf) defines its 22 perimeter pads and central ground pad. It is rotated 180 degrees, with the antenna at the bottom-left. The module body runs from (0.85,4) to (16.85,28) mm. The notch runs from (0,20.5) to (21.85,28) mm, opening at both outer edges. Its right edge is exactly 5 mm beyond the antenna. The connected section retains a 0.85 mm left inset to keep the specified solder lands on the PCB with copper-edge clearance. Outer bounds remain 48 × 28 mm.

Two copper layers, 1.6 mm board thickness; the indicator bank and main components are on top, with eight resistors on the back. TP3 is a bare test pad on the back at (2.6,19.5) mm. The module supply, support parts and test points move to fit the notch. The power-stage component positions are retained. No mounting holes or external antenna accessory. RF operation and enclosure clearance must be qualified on a prototype.

IO0–IO7 now map to internal pins 10, 1, 0, 2, 4, 5, 6, 7. The previous assignments for IO3 and IO7 are not exposed by the replacement module. The firmware configuration changes alongside the schematic. Pin 7 can select a debug source with non-default permanent configuration; the default configuration retains USB debugging regardless of its level. Pin 2 also has a debug function. Verify startup and recovery with attached loads, and do not assume old-board firmware pin mappings are interchangeable.

## Power stage

U2 is **SGM6232YPS8G/TR**, a nonsynchronous 1.4 MHz, 2 A buck in SOIC-8 with exposed pad. The [SGMICRO datasheet](https://www.sg-micro.com/rect/assets/9fe04e94-334c-4982-964b-fc08001cd9ac/SGM6232.pdf) defines BS/IN/SW/GND/FB/COMP/EN/SS as pins 1-8, with the exposed pad grounded. EN is intentionally open for automatic startup. C15 = 100 nF provides soft start. R18 = 10 ohms and C14 = 10 nF form the bootstrap network. R15 = 33 kΩ and R16 = 10.5 kΩ set nominal output to `0.8 × (1 + 33/10.5) = 3.314 V`. C16 = 5.6 nF and R17 = 10 kΩ form the series compensation branch to ground.

The switching stage uses a **4.7 µH SRP5030TA-4R7M**, SS34 catch diode, 22 µF input ceramic C2, 100 nF local input bypass C3, and 47 µF output ceramic C4. C2/C4 use 1210 footprints; procure X7R, ≥10 V parts and check capacitance under DC bias. Nominal capacitance is not effective capacitance. Qualify loop stability and transient response with the exact selected capacitors; the vendor reference values do not establish board-level stability. C6 adds 10 µF at the ESP supply.

The [Bourns drawing](https://bourns.com/docs/product-datasheets/SRP5030TA.pdf), downloaded 2026-09-17, gives 4.6 A Irms and 6 A Isat for -4R7M, with 5.7 × 5.2 × 2.8 mm nominal body. The local footprint follows its 6.5 mm land span, 2.5 mm gap and 1.8 mm pad width. SGM6232's local footprint follows the manufacturer land recommendation: 1.91 × 0.61 mm leads, 1.27 mm pitch, 5.56 mm row spacing and 2.413 × 3.302 mm exposed pad. Four reduced paste apertures cover approximately 49% of the EP. Three 0.6/0.3 mm ground vias connect the regulator exposed pad to the bottom ground copper; the module ground pad has four. Ground vias also connect the input/output capacitors and catch diode. Review exposed-pad via tenting/plugging with the assembler.

SGMICRO currently lists SGM6232 as [not recommended for new designs](https://www.sg-micro.com/product/SGM6232). It is retained as requested; verify supply availability for production.

## Channel limits and input budget

Both TPS2553DDBVR switches retain active-high enables and 10 kΩ pulldowns. **R7/R8 = 26.1 kΩ, 1%**. Using the [TI datasheet equations](https://www.ti.com/lit/ds/symlink/tps2553d.pdf), with R in kΩ and current in mA:

- Nominal: `23950 / 26.1^0.977 = 989 mA`.
- Lower bound including resistor tolerance: `25230 / (26.1 × 1.01)^1.016 = 908 mA`.
- Upper bound including resistor tolerance: `22980 / (26.1 × 0.99)^0.94 = 1081 mA`.

This is a **nominal 1 A protection setting**, not a guaranteed 1 A continuous output and not a hard 1.000 A maximum. Units may enter current limit below 1 A. Qualify rated continuous loading below the lowest measured/guaranteed threshold, accounting for temperature. FAULT outputs now connect to separate controller inputs (FAULT4: U3 pad 17; FAULT5: U3 pad 5) and remain available at TP5/TP6. R13/R14 are removed; firmware must enable internal pullups before monitoring these inputs. Firmware monitoring is pending. There is no controlled output discharge.

F1 is a 3 A, 1206 Littelfuse 0467003.NR fuse. The fuse is fault protection, not a precise 3 A limiter. Supply and cable must be rated for 5 V / 3 A. USB-C still has separate 5.1 kΩ CC pulldowns and has no PD negotiation or source-current detection. External loads must remain disabled on unqualified PC USB supplies; the board cannot identify available source current.

Illustrative budget at the 1.081 A upper channel limits: reserve 0.6 A for ESP peak demand and 0.11 A for the buzzer. Buck demand is then 1.791 A, below its nominal 2 A rating. At 4.75 V and an assumed 80% conversion efficiency, total input is approximately `1.081 + 3.314 × 1.791 / (4.75 × 0.80) = 2.64 A`, before small control losses. These reservations and efficiency are design assumptions, not measured performance.

SGM6232 specifies 4.5 V minimum input and 80% maximum duty cycle. Cable/fuse losses can therefore still compromise 3.3 V at high load. Aim for **at least 4.75 V at U2 IN under load** and verify the actual dropout margin, startup and heat. The SMF5.0A TVS is not a sustained overvoltage disconnect. Input ceramic capacitance still requires hot-plug/inrush verification.

## Interfaces and assembly details

The connector, header, reset pads and buzzer circuit are retained. The module now uses a built-in PCB antenna. User pins are 3.3 V only. Neither switched output may be back-powered.

BZ1 is **KELIKING KLJ-5020**. The [manufacturer specification v3.1](https://datasheet.lcsc.com/datasheet/pdf/5a334e56ebfeea427b46ed3bd7f9e2de.pdf?productCode=C556937) specifies a 5 × 5 × 2 mm body, 3.3 V rated drive, 2-4 V operating range, and ≤110 mA mean current at **4 kHz / 50% duty**. Its page-6 recommended top-view lands have 6.3 × 4.52 mm total span and 2.4 × 1.72 mm gaps: three 1.95 × 1.4 mm pads. Positive is upper-left, negative upper-right; the third, lower-left land is mechanical and unconnected. Do not substitute an arbitrary 5020 without checking its footprint and polarity. D3 now uses the shared MDD SS34 flyback part and Q1 is AO3400A; do not drive the coil directly from GPIO.

Native USB retains the 22 ohm series resistors and connector-side protection. These connections must be rerouted for the new module and support-component placement; the old USB routing coordinates are not reusable. The design is not impedance-qualified. Validate enumeration, flashing and traffic in both plug orientations.

## Header protection

U6/U7 use two [TPD4E05U06DQAR](https://www.ti.com/lit/ds/symlink/tpd4e05u06.pdf) four-channel arrays for IO0-IO7. Pins 1, 2, 4 and 5 protect the four signals; pins 3 and 8 connect to ground. Pins 6, 7, 9 and 10 are internally unconnected and explicitly left open. These are not duplicate signal pins. The ground-referenced arrays need no supply or local bypass capacitor. They replace four two-channel arrays and C17-C20: GPIO protection goes from eight added components to two.

Each DQA body is 2.5 x 1.0 mm. The project-local footprint follows DQA0010A recommended lands (0.565 x 0.2 mm signals, 0.565 x 0.4 mm grounds, 0.5 mm pitch, 0.835 mm row-center spacing). Check the supplied package revision and stencil against the manufacturer's drawing before assembly; the datasheet also contains DQA0010B. The 1.9 x 3.0 mm courtyards pass the final placement checks. U6/U7 remain beside the header. U6 has a routed ground return to the header ground; U7 joins the stitched ground pours. Verify ESD performance on the prototype.

U10 remains USBLC6-2SC6 for V3_SW and V5_SW, with V5 reference and C21 bypass. All ten non-ground header contacts retain ESD shunts. Power current must use copper, not flow through the protection package. The arrays are placed beside J2 with short ground returns. The new GPIO arrays have 0.5 pF typical capacitance at the specified bias and device-level ratings of +/-12 kV contact and +/-15 kV air discharge. These ratings do not establish a board-level pass.

TPD4E05U06 has a 5.5 V stand-off rating, 6.5 V minimum breakdown and approximately 10 V clamping at 1 A TLP. It is not a 3.3 V overvoltage limiter, nor a guarantee that protected pins stay below their DC absolute-maximum voltage during an ESD pulse. Its clamp behavior differs from the previous supply-steering topology. Qualify residual stress and ESD performance on the finished layout. Signals remain 3.3 V only; do not drive the board while unpowered or back-power either output. The separate power array still uses supply-referenced steering.

## Output fault monitoring

The two existing fault nets now connect independently to spare controller inputs: FAULT4 (3.3 V channel) to U3 pad 17 / GPIO15, and FAULT5 (5 V channel) to U3 pad 5 / GPIO3. R13/R14 are removed at user request; TP5/TP6 remain accessible. Enable the two internal pullups in firmware. The corresponding footprints and pullup traces are removed from the PCB. These internal inputs are separate from user-facing IO0-IO7.

Pin selection was checked against the module pin table and the controller boot-configuration tables. GPIO15 is an unused general input here. GPIO3 also serves as the MTDI/SDIO-edge strap; its level affects the unused SDIO interface, not selection of the normal flash boot or USB/UART recovery modes. Reserve it for fault sensing; external pad debugging and SDIO use would require reassessment. Test normal boot and recovery with FAULT5 both high and low. Module pin table: the datasheet linked in U3. Boot configuration source: the manufacturer's controller datasheet, sections 3.1-3.4.

The switches provide active-low open-drain status. LOW reports overcurrent, overtemperature or reverse voltage; HIGH means no asserted fault, not proof of a healthy or enabled rail. The three causes cannot be distinguished from the fault pin alone. Their built-in status delays are about 7.5 ms for overcurrent and 4 ms for reverse voltage; thermal faults are reported immediately. The internal pullups are weaker than the removed 10 kΩ resistors. The specified typical pullup is 45 kΩ; combined with the switch's 1 µA maximum off-state fault leakage, this gives about 45 mV drop as an illustrative typical-resistance calculation, not a guaranteed worst-case bound. Validate noise margin, rise time and leakage on the final board. Keep the fault traces short. Before software enables the pulls, released fault lines can float and test-pad readings are not valid.

Firmware monitoring remains outside this hardware layout task. It must configure both pins as inputs with pullup enabled and pulldown disabled (never push-pull outputs), allow settling, read initial levels before enabling loads, and monitor assertion/recovery by interrupts or polling with appropriate startup handling. Reinitialize pullups after reset and any sleep mode that loses their configuration; mask fault reporting until configuration is restored. Independent hardware current limiting remains active without firmware. The fault outputs do not monitor regulator output voltage, fuse continuity or total input failure; an unpowered controller cannot report a live fault. Both fault routes are present, and the old R13/R14 footprints are removed.

## Consolidated component choices

R9/R10/R12 use the approved 10 kΩ value. R7/R8 remain 26.1 kΩ; no lower current-limit setting has been selected. C6 remains 10 µF in 0805, and the DC/DC circuit and its capacitor values remain unchanged. D1/D3 use the same MDD SS34 SMA procurement part; other manufacturers' SS34 package variants are not automatically interchangeable. F1 remains the selected fast fuse. Resistors use eight values and capacitors seven values.

## Validation and fabrication

Final acceptance requires zero electrical-rule violations, physical-rule violations, schematic-parity findings and unconnected items. The saved reconstruction and export steps regenerate those reports. Main power routes retain 0.6 mm widths; input connector escapes are 0.5 mm, and the pull-up / protection-bias branches are 0.2 mm. clearance rules remain 0.15 mm minimum signal, 0.2 mm power and 0.25 mm copper-to-edge. Local routing uses 0.5/0.25 mm vias where required, within the published [fabricator capabilities](https://jlcpcb.com/capabilities/Capab); larger power and exposed-pad vias are retained. No individual DRC exclusions are used. No fabrication exports or component orders have been placed.

CAD checks do not establish thermal, electrical, RF or USB compliance. No Rev A board has been fabricated or bench tested. Complete `prototype-test.md` before accepting production current ratings. Two-sided assembly, EP paste/vias, connector pin protrusion and pick-and-place rotation conventions require assembler review. No fabrication or component order has been placed.

## Grouped indicators

D4-D7 form one top-side column at x=30.3 mm, on 3.2 mm pitch, with corresponding
shell openings and recessed legends. D4 and D5 are green and monitor V3_SW and
V5_SW after the output switches. D6 is red and monitors V5 after F1. D7 is blue,
driven active-high by control pin 26 (U3 pad 20); it does not consume a header IO.
Firmware control of STATUS_LED is not added by this hardware change.

The selected low-current AA1608 family uses asymmetric manufacturer lands with
pad 1 as cathode. Green AA1608LCGSK and red AA1608LSURSK are specified at 2 mA;
the blue AA1608LQBS/D-295V has a 2.65 V typical / 2.95 V maximum forward voltage
at 2 mA, providing better headroom for the 3.3 V control output. R19 = 680 ohms,
R20/R21 = 1.5 kohms and R22 = 330 ohms target roughly 2 mA using typical forward
voltages. Actual brightness/current varies with supply, temperature and LED bin;
verify on the prototype. All four cathodes connect to ground.

R7/R8/R9/R10 move to the bottom without changing their values or functions.
R19-R22 are also on the bottom. The eight bottom resistors fit within the existing
solder-tail allowance; assembly is now two-sided. Board outline and approved
revision/date remain unchanged. The indicator wells and labels are generated
from the LED placements; the blank QR area remains clear.

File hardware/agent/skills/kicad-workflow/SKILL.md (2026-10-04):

---
name: kicad-workflow
description: Modify, regenerate, route and validate the Saihub KiCad hardware using its project-local scripts. Use for this hardware project, including refreshing its review documents.
---

# Saihub KiCad workflow

Paths below are relative to `hardware/`. Read `README.md` and [design notes](../../docs/design-notes.md) before changes; use [prototype tests](../../docs/prototype-test.md) for bench work. Read `docs/version-log.md` and `agent/identity.json`. Change the revision or date version only when the user explicitly permits it, and log each approved version change in `docs/version-log.md`. Regeneration, routing, export and ordinary edits must preserve the approved identity.

## Preserve the editable design

The main `saihub.kicad_pcb` is the routed board. Keep the project, schematic, library tables and `libraries/` together at the hardware root. `agent/design.json` records parts, placement and connectivity; the generator's source contains the placement definitions that produce it. Reconcile direct KiCad edits with that metadata before exporting a BOM or running the metadata synchronizer.

`agent/scripts/generate.py` regenerates symbols, footprints, schematic and `agent/routing/saihub-unrouted.kicad_pcb`. It preserves existing project settings and does not overwrite the main routed board. Do not run it merely to refresh previews. For a placement-only request, stop before routing and report unconnected items honestly.

Use KiCad's bundled Python for `pcbnew` scripts. On macOS it is normally `/Applications/KiCad/KiCad.app/Contents/Frameworks/Python.framework/Versions/Current/bin/python3`. The generator uses `wx.App(False)` and may require desktop access. Use project-local footprints and inspect manufacturer land patterns when changing parts; similarly named packages may have different pad mappings.

## Routing and checks

For the four-indicator layout, run `agent/scripts/replay_routing.py replay` with KiCad Python after regeneration. It restores `agent/routing/copper.json` only when every footprint, pad position and net matches the captured placement. For a new placement, route the edited main board, then capture its copper with `replay_routing.py capture` and run the full routed checks before accepting the snapshot. The legacy `route.py`/Specctra inputs predate the indicator placement and are guarded against reuse with it.

From the repository root, run `python3 hardware/agent/scripts/export_placement.py --routed`. Set `KICAD_CLI` and `KICAD_PYTHON` if needed. The host Python needs `reportlab`, and ImageMagick must be on PATH. Set `INTERACTIVE_HTML_BOM` to the upstream `InteractiveHtmlBom/generate_interactive_bom.py` script; document exports also compile the offline `docs/bom.html`. The export first writes a netlist, synchronizes symbol UUIDs and explicit NC nets, fills zones, then runs ERC and DRC with schematic parity. Routed acceptance requires zero violations, parity findings and unconnected items. Without `--routed`, unconnected items are allowed for placement review only.

Inspect the top and mirrored bottom pages of `docs/pcb.pdf` and the schematic PDF after exporting. KiCad SVG contains invisible searchable text; strip those text nodes before ImageMagick rasterization to avoid duplicated labels. `export_docs.py` performs that conversion and refreshes the procurement BOM, excluding test pads; the current antenna is built into the module. `agent/validation/parts-placement.csv` retains all footprints for placement review.

## Retained evidence

Keep current `agent/validation/` and routing reconstruction inputs in Git. Do not retain obsolete revision archives or documents. Saved reports are evidence of a particular CAD state, not a substitute for rerunning checks. `agent/previews/` is regenerable and ignored; the five human review files live in `docs/`, including `docs/shell.pdf`.

## Keep the enclosure synchronized

After any change to the routed PCB, refresh the enclosure reference and re-render **`hardware/docs/shell.pdf`** (repository-relative); never write the shell PDF to the repository-level `docs/` or `hardware/shell.pdf`. `export_docs.py`, and therefore the placement and fabrication export workflows, calls `mechanical/refresh_shell.py` automatically. Install `mechanical/requirements.txt` in `mechanical/.venv`, or set `MECHANICAL_PYTHON` to a Python environment with those dependencies. Shell refresh failures must fail the export; do not silently retain an old PDF as current.

Before exporting a changed board, compare its outline, thickness, connector locations/heights and component keep-outs with `mechanical/enclosure.py`. Update the shell's parameters, openings, supports, text alignment and illustrative component envelopes when those inputs change. The model contains explicit dimensions; re-exporting the PCB alone does not adapt them. Read [the mechanical guide](../../../mechanical/README.md) for design constraints and refresh commands.

The refresh command exports `mechanical/reference/pcb.step` from the routed board, regenerates STEP/STL and previews, checks available component and snap insertion geometry, then recomputes drawing views, dimensions and the ABS mass estimate. Preserve the current design choices: closed top, recessed lettering, blank QR bed, side snap retention, and no thin bridge above the GPIO opening. These are current project requirements, not rules for unrelated hardware.

Render the resulting PDF to page images and inspect every page for clipping, label alignment, connector access and drawing consistency. Missing/illustrative component models and untested snap forces remain explicit limitations; do not describe a geometry-only check as a physical fit test. Preserve the approved board revision/date throughout this refresh.

Only run `agent/scripts/export.py` when fabrication exports are needed. CAD checks do not establish measured power, thermal or USB performance; use the prototype test procedure for those claims.

`silkscreen.py` places references on the same side as each footprint, including the eight back-side resistors and test pad, avoiding exposed pads and other labels. Generation and board synchronization both apply it. Keep the approved date in PCB title metadata for the interactive BOM.

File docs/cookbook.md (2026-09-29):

# SAIHub cookbook

Flash the board, join Wi-Fi, and hand an MCP URL to Cursor, Claude Code, or Codex CLI.

[中文手册](cookbook.zh.md) · [README](../README.md)

## 1. Flash firmware

1. Download the firmware `.bin` from [GitHub Releases](https://github.com/xqe2011/saihub/releases). That file is a **merged** image for ESP32-C5 (4 MB flash).
2. Open the official [ESP web flasher](https://espressif.github.io/esptool-js/) in **Chrome** or **Edge** (Web Serial is required).
3. Put the board in **download mode** (see below), click Connect, pick the USB serial port.
4. Flash the `.bin` at address **`0x0`**. Chip: **ESP32-C5**. Flash mode DIO, 80 MHz, 4 MB is fine if the tool asks.
5. When it finishes, unplug USB and plug it back in **without** holding BOOT so the new firmware runs.

Use a **USB data cable**, not a charge-only cable.

### Download mode

SAIHub-Mini has native USB and a BOOT button (GPIO28) beside USB-C. There is no EN / RESET button on the board. The chip enters the ROM serial bootloader when GPIO28 is held low at reset.

Do this:

1. Unplug USB.
2. Hold the small **BOOT** button (between the 12-pin header and USB-C).
3. Plug USB-C in while still holding BOOT.
4. Keep holding until the web flasher connects, then release.

If the board is already powered and the flasher cannot sync:

- Keep holding **BOOT**.
- Briefly short **TP1** and **TP2** (EN / GND reset pads on the top of the PCB), then release BOOT after the flasher connects.

Empty boards often enumerate in download mode already — try connecting first, then use the hold-BOOT sequence if it times out.

> Clicking BOOT after firmware is running starts **Wi-Fi pairing**, not download mode. Download mode is only at reset with BOOT held.

## 2. Join Wi-Fi

1. After a normal boot, **click BOOT once**. The board raises an open access point named `SAIHUB-` plus the last three bytes of its MAC, for example `SAIHUB-a1b2c3`.
2. Connect your phone or laptop to that AP (no password).
3. A captive-portal page should open. If it does not, browse to [http://192.168.4.1/wifi/page](http://192.168.4.1/wifi/page).
4. Pick your network, enter the password, tap **Connect**. Wait until it shows **Device IP**.
5. Write that IP down. The pairing AP closes a few seconds after a successful join. Click BOOT again if you need to cancel pairing.

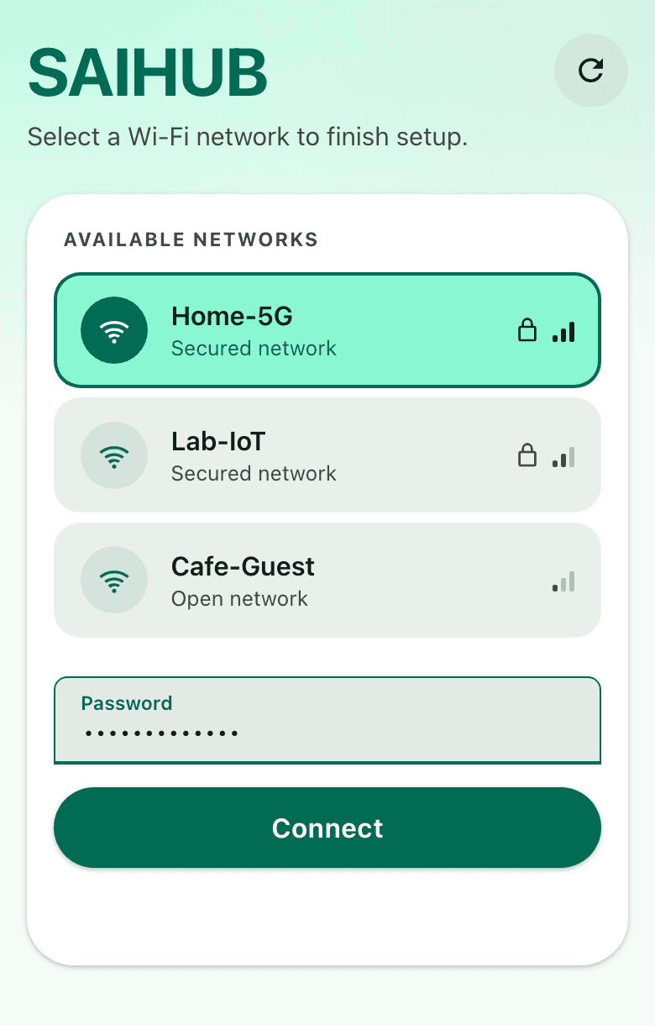
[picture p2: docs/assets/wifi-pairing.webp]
SAIHub Wi-Fi pairing page


The board reconnects to the saved network on later boots. Click BOOT any time you need to change Wi-Fi.

On the LAN you now have:

| URL | For |
| --- | --- |
| `http://<device-ip>/` | Human control UI |
| `http://<device-ip>/mcp` | MCP (Streamable HTTP) |
| `http://<device-ip>/openapi.json` | REST description |

## 3. Connect an MCP client

Replace `DEVICE_IP` with the address from the pairing page. Same LAN as the board.

After you add the server, ask the agent something concrete: *“List pins, set pin 0 as a digital output, and drive it high for one second.”*

### Cursor

Settings → **Tools & MCP**, or edit `~/.cursor/mcp.json` / `.cursor/mcp.json`:

```json
{
  "mcpServers": {
    "saihub": {
      "url": "http://DEVICE_IP/mcp"
    }
  }
}
```

### Claude Code

```bash
claude mcp add --transport http saihub http://DEVICE_IP/mcp
claude mcp list
```

Project-wide (writes `.mcp.json`):

```bash
claude mcp add --scope project --transport http saihub http://DEVICE_IP/mcp
```

### Codex CLI

```bash
codex mcp add saihub --url http://DEVICE_IP/mcp
```

Or in `~/.codex/config.toml`:

```toml
[mcp_servers.saihub]
url = "http://DEVICE_IP/mcp"
```

In the TUI, `/mcp` shows whether the server is live.

### Tools the agent can call

GPIO: `list_pins`, `configure_pins`, `get_pin_levels`, `set_pin_levels`, `pulse_pins`, `get_pin_pwms`, `set_pin_pwms`, `trace_pins`.

Power: `get_output_power_state`, `set_output_power_state` (`3v3` / `5v`).

UART: `list_uarts`, `configure_uart`, `uart_transmit`, `uart_receive`, `uart_flush`.

Buzzer: `play_buzzer`.

Scripts: `run_script` — sandboxed Lua 5.4 with the same pin/power tools plus `sleep(us)`.

Full schemas: [`mcp.json`](../mcp.json). REST twin: [`openapi.json`](../openapi.json).

## 4. Managed cloud relay (optional)

If you **buy a board from us**, we host the cloud relay. After the board is on Wi-Fi it keeps a WebSocket to the cloud. You can use Saihub from a cafe, another office, or a CI runner — not only the local LAN.

1. After cloud authentication succeeds, the serial log prints the landing page URL:

   `https://saihub.xqe2011.com/cloud/landing/<digest>/page`

2. Open that URL. It shows whether the board is online. Paste the MCP URL into Cursor, Claude Code, or Codex CLI the same way as the LAN URL. The client runs OAuth in the browser: name this client, then **hold BOOT for 3 seconds** on the board. You do not paste a long-lived token by hand.

   REST calls need a routing token first. Click **Get routing token** on the landing page — that reuses the same OAuth pairing flow, then shows the token with a copy button. Revoke grants later from the device control page **Cloud** tab (`http://<device-ip>/`).

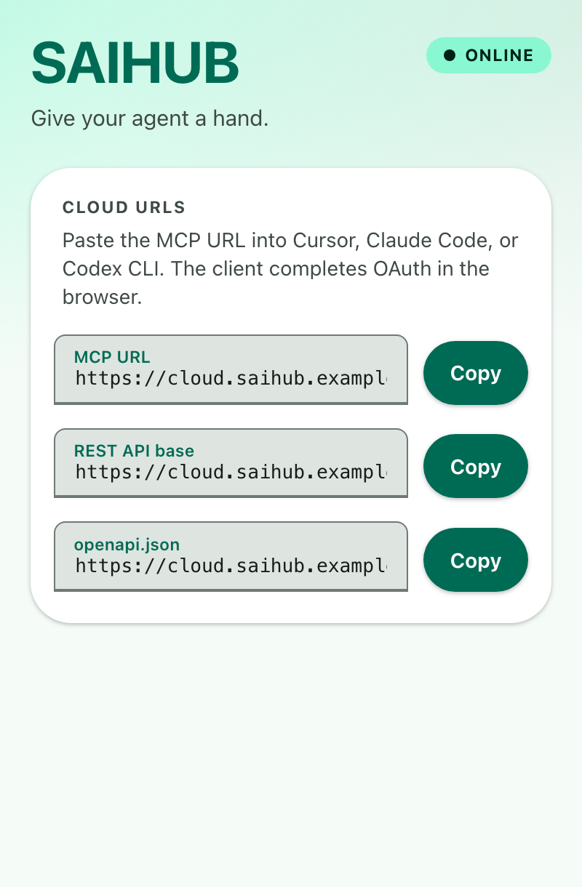
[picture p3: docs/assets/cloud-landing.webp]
SAIHub cloud landing page


Self-hosted workers use the same URL shape; the serial log prints the landing page for your origin. See the next section.

## 5. Self-host the Cloudflare relay

The worker in `cloud/cloudflare/` proxies MCP and REST to the board over a Durable Object, with OAuth for MCP clients. The relay protocol itself is server-agnostic — message formats, auth handshake, and limits are documented in the [design notes](design-notes.md).

### Deploy

You need a Cloudflare account. D1, the Durable Object, env vars, and secrets are auto-provisioned.

Deploy to Cloudflare (https://deploy.workers.cloudflare.com/?url=https://github.com/xqe2011/saihub/tree/main/cloud/cloudflare)

On the setup page, set `ROUTING_TOKEN_SECRET` and `ADMIN_TOKEN` (each `openssl rand -hex 32`).

The dashboard prints a `*.workers.dev` origin, for example `https://saihub-cloud.<account>.workers.dev`. Optional: attach a custom domain. Open `/admin` on that origin, enter `ADMIN_TOKEN`, and whitelist each device digest before it can connect. Unlisted digests get 403.

### Point firmware at your worker

In `main/include/config.h` set the WebSocket origin (**`wss://`**, no path):

```c
#define CONFIG_CLOUD_URL "wss://saihub-cloud.<account>.workers.dev"
```

Rebuild and flash with ESP-IDF ≥ 5.5:

```bash
idf.py set-target esp32c5
idf.py build
idf.py merge-bin   # merged image for the web flasher, flash at 0x0
```

Building for a board other than SAIHub-Mini? Remap the pins first: [bring your own board](bring-your-own-board.md).

Once the board reboots, the device connects to:

`wss://<origin>/cloud/device/<digest>`

MCP clients use:

`https://<origin>/device/<digest>/mcp`

`<digest>` is the board’s Base58Check device id (from the hardware ECDSA public key). After the board authenticates, the serial log prints the landing page at `https://<origin>/cloud/landing/<digest>/page` — open that to copy the MCP, REST, and OpenAPI URLs.

Keep `ROUTING_TOKEN_SECRET` and `ADMIN_TOKEN` as Worker secrets. Do not commit them.

Worker routes, local dev with a fake device, and tests: [build.md](build.md).

## 6. Pins, power, and example jobs

SAIHub-Mini J2 header

Quick reference — J2 left to right: `1:3V3_SW  2:GND  3:5V_SW  4:GND  5:IO0 … 12:IO7`; IO0–IO7 map to ESP32-C5 GPIO **10, 1, 0, 23, 4, 5, 6, 24**; both rails default **off**. Full pinout table, power budget, and test points: [hardware.md](hardware.md).

### Give the agent a hand on the bench

Wire SAIHub’s GPIO and UART to a DUT. Then ask:

> Configure pins 0–2 as inputs with pull-ups. Trace them for two seconds while I press the DUT button. Summarize the edges, then bit-bang a reset pulse on pin 3.

That is GPIO + pulse + `trace_pins` (a small logic analyzer) + optional UART to the debug console. PWM can clock a line the DUT expects.

### Agent-ready IO

**Servo.** 5 V rail on, PWM on a data pin (typical 50 Hz, ~2.5–12.5% duty for 0–180°). Ask the agent to sweep and stop on a photo-gate GPIO.

**Light.** PWM an LED or a MOSFET dimmer. Slow ramps belong in `run_script` with `sleep`.

**Electromagnetic relay.** Enable 5 V if the coil needs it, configure the pin as a digital output, set it high to close. Use it as a smart switch for a pump, a door lock, a heater, or a test-fixture mains relay (keep mains on the relay side, never on SAIHub pins).

**Safety.** 5 V / 3 A adapter and cable for real loads. Keep outputs off on unknown USB ports. Nominal rail protection is about 1 A, not a guaranteed continuous 1 A.

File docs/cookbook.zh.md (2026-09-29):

# SAIHub 使用手册

烧录固件、连上 Wi-Fi，把 MCP 地址填进 Cursor、Claude Code 或 Codex CLI，智能体就能驱动板子了。

[English cookbook](cookbook.md) · [README](../README.zh.md)

## 1. 烧录固件

1. 从 [GitHub Releases](https://github.com/xqe2011/saihub/releases) 下载固件 `.bin`。这是 ESP32-C5（4 MB Flash）的**合并镜像**，一个文件包含全部固件。
2. 用 **Chrome** 或 **Edge** 打开官方 [ESP 网页烧录器](https://espressif.github.io/esptool-js/)（依赖 Web Serial）。
3. 先让板子进入**下载模式**（见下文），再点击 Connect，选择对应的 USB 串口。
4. 把 `.bin` 烧到地址 **`0x0`**，芯片选 **ESP32-C5**。如果工具询问其他参数，Flash 模式 DIO、80 MHz、4 MB 即可。
5. 烧录完成后拔掉 USB，重新插上（这次**不要**按住 BOOT），新固件即会启动。

务必使用 **USB 数据线**；纯充电线没有数据芯，无法烧录。

### 进入下载模式

SAIHub-Mini 采用原生 USB，BOOT 键（GPIO28）位于 USB-C 旁边，板上没有单独的 EN / RESET 键。只要在复位瞬间拉低 GPIO28，芯片就会进入 ROM 串口下载模式。

操作步骤：

1. 拔掉 USB。
2. 按住板上的 **BOOT** 键（位于 12 针排针与 USB-C 之间）。
3. 保持按住，插入 USB-C。
4. 等网页烧录器连接成功后，再松开 BOOT。

如果板子已处于上电状态、烧录器一直连不上：

- 继续按住 **BOOT**。
- 用镊子短接板顶的 **TP1** 和 **TP2**（EN / GND 复位焊盘）触发复位，等烧录器连上后再松开 BOOT。

没烧录过的空片往往本来就处于下载模式，可以先直接点 Connect 试试；超时了再走上面的流程。

> 注意：固件正常运行后，按一下 BOOT 是开启 **Wi-Fi 配对**，不是进下载模式。下载模式只在复位（或上电）瞬间按住 BOOT 才会触发。

## 2. 连接 Wi-Fi

1. 正常开机后，**按一下 BOOT**。板子会开出一个无密码热点，名称为 `SAIHUB-` 加 MAC 地址后三字节，例如 `SAIHUB-a1b2c3`。
2. 用手机或电脑连接这个热点。
3. 连接后通常会自动弹出配网页面；如果没有，请在浏览器打开 [http://192.168.4.1/wifi/page](http://192.168.4.1/wifi/page)。
4. 选择你的 Wi-Fi，输入密码，点 **Connect**，等页面显示出 **Device IP**。
5. 记下这个 IP。配对成功几秒后，热点会自动关闭。想取消配对，再按一下 BOOT 即可。

SAIHub Wi-Fi 配对页

之后每次开机都会自动重连已保存的网络。需要更换 Wi-Fi 时，随时按一下 BOOT。

此时局域网内可访问：

| 地址 | 用途 |
| --- | --- |
| `http://<设备IP>/` | 网页控制台（供人工操作） |
| `http://<设备IP>/mcp` | MCP（Streamable HTTP） |
| `http://<设备IP>/openapi.json` | REST 接口描述 |

## 3. 接入 MCP 客户端

将 `DEVICE_IP` 替换为配对页面显示的地址；电脑需与板子处于同一局域网。

添加完成后，不妨给智能体一个具体任务验证连接，例如：「列出所有引脚，把 pin 0 配置为数字输出，拉高一秒钟。」

### Cursor

打开设置 → **Tools & MCP**，或直接编辑 `~/.cursor/mcp.json` / `.cursor/mcp.json`：

```json
{
  "mcpServers": {
    "saihub": {
      "url": "http://DEVICE_IP/mcp"
    }
  }
}
```

### Claude Code

```bash
claude mcp add --transport http saihub http://DEVICE_IP/mcp
claude mcp list
```

添加到项目级配置（写入 `.mcp.json`）：

```bash
claude mcp add --scope project --transport http saihub http://DEVICE_IP/mcp
```

### Codex CLI

```bash
codex mcp add saihub --url http://DEVICE_IP/mcp
```

或编辑 `~/.codex/config.toml`：

```toml
[mcp_servers.saihub]
url = "http://DEVICE_IP/mcp"
```

在 TUI 中输入 `/mcp` 可查看服务器是否在线。

### 智能体可用的工具

GPIO：`list_pins`、`configure_pins`、`get_pin_levels`、`set_pin_levels`、`pulse_pins`、`get_pin_pwms`、`set_pin_pwms`、`trace_pins`。

电源：`get_output_power_state`、`set_output_power_state`（`3v3` / `5v`）。

UART：`list_uarts`、`configure_uart`、`uart_transmit`、`uart_receive`、`uart_flush`。

蜂鸣器：`play_buzzer`。

脚本：`run_script` —— 在设备端沙箱中运行 Lua 5.4，可调用同一套引脚 / 电源工具，另提供 `sleep(us)`。

完整 schema 见 [`mcp.json`](../mcp.json)；REST 对应描述见 [`openapi.json`](../openapi.json)。

## 4. 托管云中继（可选）

**从我们这里购买**的板子自带一个由我们托管的云中继。板子连上 Wi-Fi 后，会与云端保持一条 WebSocket 长连接；之后你在咖啡馆、另一间办公室甚至 CI 里都能用 SAIHub，不受局域网限制。

1. 云端鉴权成功后，串口日志会打印落地页地址：

   `https://saihub.xqe2011.com/cloud/landing/<digest>/page`

2. 打开该地址。页面会显示板子是否在线。接着像填局域网地址一样，把 MCP 地址填进 Cursor、Claude Code 或 Codex CLI。客户端会在浏览器完成 OAuth：给这个客户端起名，然后在板子上**长按 BOOT 3 秒**。无需手动粘贴长期 token。

   使用 REST 需要先拿到 routing token。在落地页点击 **Get routing token**，会走同一套 OAuth 配对流程，然后将会展示 token 并提供复制按钮。之后可在设备控制页的 **Cloud** 标签页撤销授权（`http://<设备IP>/`）。

SAIHub 云落地页

自行部署的 Worker 使用相同的 URL 格式；串口日志会打印指向你自己源站的落地页。见下一节。

## 5. 自行部署 Cloudflare 中继

`cloud/cloudflare/` 中的 Worker 借助 Durable Object 把 MCP 和 REST 请求转发到板子，并为 MCP 客户端提供 OAuth 鉴权。中继协议本身不绑定 Cloudflare——消息格式、鉴权握手和各类限制详见[协议设计笔记](design-notes.md)（英文）。

### 部署

准备工作：一个 Cloudflare 账号。D1、Durable Object、环境变量和密钥会自动创建。

Deploy to Cloudflare (https://deploy.workers.cloudflare.com/?url=https://github.com/xqe2011/saihub/tree/main/cloud/cloudflare)

在配置页填入 `ROUTING_TOKEN_SECRET` 和 `ADMIN_TOKEN`（各用 `openssl rand -hex 32` 生成）。

完成后控制台会给出 `*.workers.dev` 源站地址，例如 `https://saihub-cloud.<account>.workers.dev`。也可以绑定自定义域名。打开该源站的 `/admin`，输入 `ADMIN_TOKEN`，把设备 digest 加入白名单后才能连接；未列入的 digest 会返回 403。

### 配置固件指向你的 Worker

编辑 `main/include/config.h`，填入 WebSocket 源站地址（以 **`wss://`** 开头，不带路径）：

```c
#define CONFIG_CLOUD_URL "wss://saihub-cloud.<account>.workers.dev"
```

然后用 ESP-IDF ≥ 5.5 重新编译并烧录：

```bash
idf.py set-target esp32c5
idf.py build
idf.py merge-bin   # 生成网页烧录器使用的合并镜像，烧到 0x0
```

为 SAIHub-Mini 以外的板子编译？请先重映射引脚：[自备开发板](bring-your-own-board.zh.md)。

板子重启后，设备将连接：

`wss://<源站>/cloud/device/<digest>`

MCP 客户端则使用：

`https://<源站>/device/<digest>/mcp`

`<digest>` 是板子的 Base58Check 设备 ID（由硬件 ECDSA 公钥派生）。板子鉴权成功后，串口日志会打印落地页 `https://<源站>/cloud/landing/<digest>/page`，打开即可复制 MCP、REST 和 OpenAPI 地址。

`ROUTING_TOKEN_SECRET` 和 `ADMIN_TOKEN` 作为 Worker secrets 保存，切勿提交进仓库。

Worker 的路由表、本地模拟设备联调和测试方法见[构建指南](build.zh.md)。

## 6. 引脚、电源和示例

SAIHub-Mini J2 排针

速查——俯视板子、排针朝上时，J2 从左到右：`1:3V3_SW  2:GND  3:5V_SW  4:GND  5:IO0 … 12:IO7`；IO0–IO7 对应 ESP32-C5 GPIO **10、1、0、23、4、5、6、24**；两路电源默认**关闭**。完整引脚表、电源规格和测试点见[硬件文档](hardware.zh.md)。

### 让智能体上手调试真实硬件

把 SAIHub 的 GPIO 和 UART 连到待测板，然后对智能体说：

> 把 pin 0–2 配置为上拉输入，抓取两秒边沿信号，期间我会按一下待测板的按键。然后总结边沿情况，并在 pin 3 上打一个复位脉冲。

这条指令背后是 GPIO + 脉冲 + `trace_pins`（相当于小型逻辑分析仪），还可以顺带用 UART 连接调试串口；PWM 也能为待测板提供它需要的时钟信号。

### 外接设备示例

**舵机。** 打开 5 V 电源，在数据脚输出 PWM（常见 50 Hz，占空比约 2.5–12.5% 对应 0–180°）。可以让智能体连续扫动舵机，并在光电开关对应的 GPIO 上停住。

**灯光。** 用 PWM 驱动 LED 或 MOSFET 调光电路。需要缓慢渐变时，把逻辑写进 `run_script`，配合 `sleep` 实现。

**电磁继电器。** 线圈需要 5 V 就先打开 5 V 电源，把引脚配置为数字输出，拉高即可吸合。可以当作智能开关使用：水泵、门锁、加热器，或工装上的市电继电器（市电只能走继电器触点，绝不能接到 SAIHub 引脚）。

**安全提示。** 带实际负载时请使用 5 V / 3 A 的适配器和线缆；接入不确定的 USB 口时，先关闭电源输出。电源通道的保护阈值约为 1 A，不保证能持续输出 1 A。

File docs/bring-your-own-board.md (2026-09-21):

# Bring your own board

The firmware is not tied to SAIHub-Mini. Any ESP32-C5 board runs it — an Espressif devkit or your own carrier board — as long as it has Wi-Fi, an antenna, and enough free GPIO. Everything the agent talks to (MCP, REST, the web UI, Lua) lives in the chip.

[中文](bring-your-own-board.zh.md) · [README](../README.md) · [Hardware](hardware.md)

## What works on any ESP32-C5

- MCP server (Streamable HTTP, port 80), REST + OpenAPI, Wi-Fi pairing portal, and the web control UI
- GPIO: digital in / out / open-drain, pulse, PWM (4 channels, up to 50 kHz), edge trace (up to 60 s / 1024 events)
- The product UART — UART1 routes through the GPIO matrix, so TX / RX can sit on any pins you map
- Sandboxed Lua 5.4 scripts and resource locks
- Cloud relay: the ECDSA identity key is provisioned into each chip's eFuse at first boot, so the relay works from any board — point `CONFIG_CLOUD_URL` at a worker you self-host (the managed cloud comes with boards bought from us)

## What you lose without the SAIHub-Mini hardware

| Function | Why | Options |
| --- | --- | --- |
| Switched 3V3 / 5V rails (`set_output_power_state`) | Needs the TPS2553 load-switch circuit | Remap the enable pins to your own load switch, or ignore the power tools |
| ~1 A output current limit, fused 3 A input | Carrier-board protection parts | Design your own supply path; don't hang heavy loads off devkit rails |
| BOOT button UX (click → Wi-Fi pairing) | Button wired to `CONFIG_BUTTON_PIN` | Many C5 devkits wire BOOT to GPIO28 as well — check your schematic. Otherwise remap the pin, or bake credentials into `CONFIG_WIFI_SSID` / `CONFIG_WIFI_PASSWORD`: they are used whenever NVS has none saved, and portal-paired credentials persist in NVS |
| Buzzer feedback | 5020 buzzer on GPIO12 | Remap or ignore |
| Managed cloud | A service included with boards bought from us | Self-host the worker ([cookbook §5](cookbook.md#5-self-host-the-cloudflare-relay)) |

## Where to update the GPIO map

All board-specific pins live in `main/include/config.h`:

```c
#define CONFIG_GPIO_LOGICAL_TO_HW {10, 1, 0, 23, 4, 5, 6, 24} /* IO0…IO7 → chip GPIOs */
#define CONFIG_BUTTON_PIN 28            /* BOOT button; click = Wi-Fi pairing */
#define CONFIG_GPIO_POWER_3V3_PIN 8     /* 3V3_SW load-switch enable */
#define CONFIG_GPIO_POWER_5V_PIN 9      /* 5V_SW load-switch enable */
#define CONFIG_BUZZER_PIN 12
#define CONFIG_CLOUD_URL "wss://…"      /* relay origin; empty disables the relay */
#define CONFIG_WIFI_SSID "CHANGE_ME"    /* optional Wi-Fi seed, see above */
#define CONFIG_WIFI_PASSWORD "CHANGE_ME"
```

`CONFIG_GPIO_LOGICAL_TO_HW` is the map agents see: entry *N* is the logical pin `IO<N>` used by `list_pins`, `set_pin_levels`, and friends; the value is the physical chip GPIO. The array length decides how many pins are exposed.

The prebuilt `.bin` in [Releases](https://github.com/xqe2011/saihub/releases) is built for the SAIHub-Mini map and a 4 MB flash layout. For your own board, rebuild:

```bash
idf.py set-target esp32c5
idf.py build
idf.py merge-bin   # merged image for the web flasher
```

### Picking pins

- 3.3 V logic only.
- Avoid strapping pins **GPIO2 / GPIO7 / GPIO28** for anything that drives a level at reset — input-only use is fine (that is why the BOOT button sits on GPIO28).
- Avoid **GPIO13 / GPIO14** (USB D- / D+) if you use native USB Serial/JTAG.
- Avoid the console UART0 pins and any pins your module hides for flash / PSRAM — check the module datasheet and your `sdkconfig`.
- Everything else is fair game: UART1, PWM, and trace all route through the GPIO matrix.

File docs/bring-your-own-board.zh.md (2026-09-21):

# 自备开发板

固件并不绑定 SAIHub-Mini 这块板子。任何 ESP32-C5 开发板都能跑——Espressif 官方 DevKit 或你自己画的载板都行——只要有 Wi-Fi、天线和足够的空闲 GPIO。智能体对接的一切（MCP、REST、网页控制台、Lua）都长在芯片里。

[English](bring-your-own-board.md) · [README](../README.zh.md) · [硬件文档](hardware.zh.md)

## 在任何 ESP32-C5 上都可用的功能

- MCP 服务器（80 端口 Streamable HTTP）、REST + OpenAPI、Wi-Fi 配网门户和网页控制台
- GPIO：数字输入 / 输出 / 开漏、脉冲、PWM（4 通道，最高 50 kHz）、边沿采集（最长 60 s / 1024 个事件）
- 产品 UART——UART1 经 GPIO 交换矩阵路由，TX / RX 可以落在你映射的任意引脚上
- 沙箱 Lua 5.4 脚本和资源锁
- 云中继：ECDSA 身份密钥在首次启动时烧写进每颗芯片的 eFuse，所以任何板子都能用中继——把 `CONFIG_CLOUD_URL` 指向你自行部署的 Worker 即可（托管云仅随我们售出的板子提供）

## 离开 SAIHub-Mini 硬件后缺失的功能

| 功能 | 原因 | 替代方案 |
| --- | --- | --- |
| 可通断的 3V3 / 5V 电源（`set_output_power_state`） | 依赖板上 TPS2553 负载开关电路 | 把使能脚重映射到你自己的负载开关，或忽略电源工具 |
| 约 1 A 输出限流、3 A 保险丝输入保护 | 属于载板保护电路 | 自行设计供电路径；别把大负载挂在 DevKit 的电源脚上 |
| BOOT 按键交互（按一下 = Wi-Fi 配对） | 按键接在 `CONFIG_BUTTON_PIN` 上 | 多数 C5 DevKit 的 BOOT 键同样接 GPIO28——请对照你的原理图确认。否则重映射该引脚，或把 Wi-Fi 凭据直接写进 `CONFIG_WIFI_SSID` / `CONFIG_WIFI_PASSWORD`：NVS 里没有保存凭据时就会用它们，配网成功后凭据会持久化到 NVS |
| 蜂鸣器提示 | GPIO12 上的 5020 蜂鸣器 | 重映射或忽略 |
| 托管云中继 | 随我们售出的板子提供的服务 | 自行部署 Worker（[使用手册第 5 节](cookbook.zh.md#5-自行部署-cloudflare-中继)） |

## 在哪里改 GPIO 映射

所有和板子相关的引脚都集中在 `main/include/config.h`：

```c
#define CONFIG_GPIO_LOGICAL_TO_HW {10, 1, 0, 23, 4, 5, 6, 24} /* IO0…IO7 → 芯片 GPIO */
#define CONFIG_BUTTON_PIN 28            /* BOOT 按键；按一下 = Wi-Fi 配对 */
#define CONFIG_GPIO_POWER_3V3_PIN 8     /* 3V3_SW 负载开关使能 */
#define CONFIG_GPIO_POWER_5V_PIN 9      /* 5V_SW 负载开关使能 */
#define CONFIG_BUZZER_PIN 12
#define CONFIG_CLOUD_URL "wss://…"      /* 中继源站；留空则禁用中继 */
#define CONFIG_WIFI_SSID "CHANGE_ME"    /* 可选的 Wi-Fi 凭据种子，见上 */
#define CONFIG_WIFI_PASSWORD "CHANGE_ME"
```

`CONFIG_GPIO_LOGICAL_TO_HW` 就是智能体看到的引脚表：第 *N* 项对应 `list_pins`、`set_pin_levels` 等工具里的逻辑引脚 `IO<N>`，值是实际接线的芯片 GPIO。数组长度决定暴露多少个引脚。

[Releases](https://github.com/xqe2011/saihub/releases) 里的预编译 `.bin` 按 SAIHub-Mini 的映射和 4 MB Flash 布局构建。自己的板子请重新编译：

```bash
idf.py set-target esp32c5
idf.py build
idf.py merge-bin   # 生成网页烧录器用的合并镜像
```

### 选脚规则

- 逻辑电平只有 3.3 V。
- 避开 strapping 引脚 **GPIO2 / GPIO7 / GPIO28**，不要在复位期间驱动这些脚的电平——只作输入没问题（BOOT 按键接 GPIO28 正是这个原因）。
- 使用原生 USB（Serial/JTAG）时，避开 **GPIO13 / GPIO14**（USB D- / D+）。
- 避开控制台 UART0 占用的引脚，以及模组内部用于 flash / PSRAM、未引出的引脚——请对照模组数据手册和你的 `sdkconfig`。
- 其余引脚都可以自由使用：UART1、PWM 和边沿采集全部经 GPIO 交换矩阵路由。

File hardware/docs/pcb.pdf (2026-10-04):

# SAIHub-Mini Rev A / 2026-09-24 | PCB top

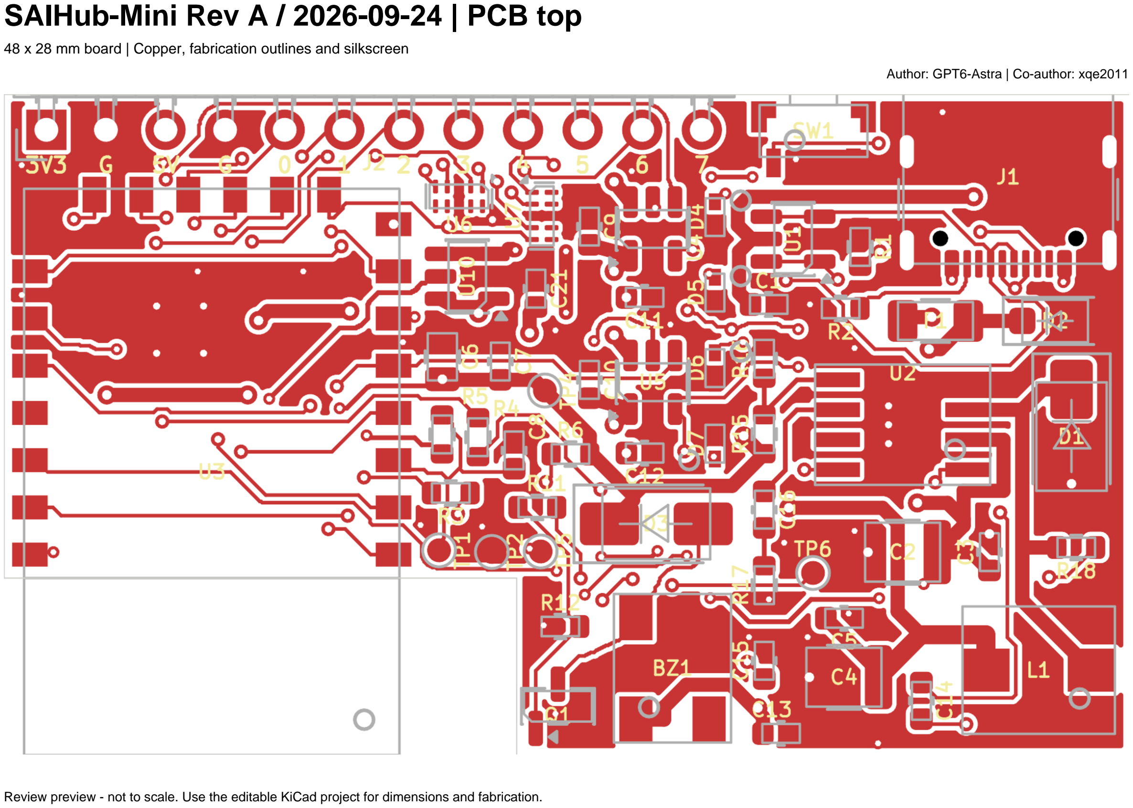
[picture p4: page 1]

48 x 28 mm board | Copper, fabrication outlines and silkscreen
Author: GPT6-Astra | Co-author: xqe2011

Review preview - not to scale. Use the editable KiCad project for dimensions and fabrication.

# SAIHub-Mini Rev A / 2026-09-24 | PCB bottom

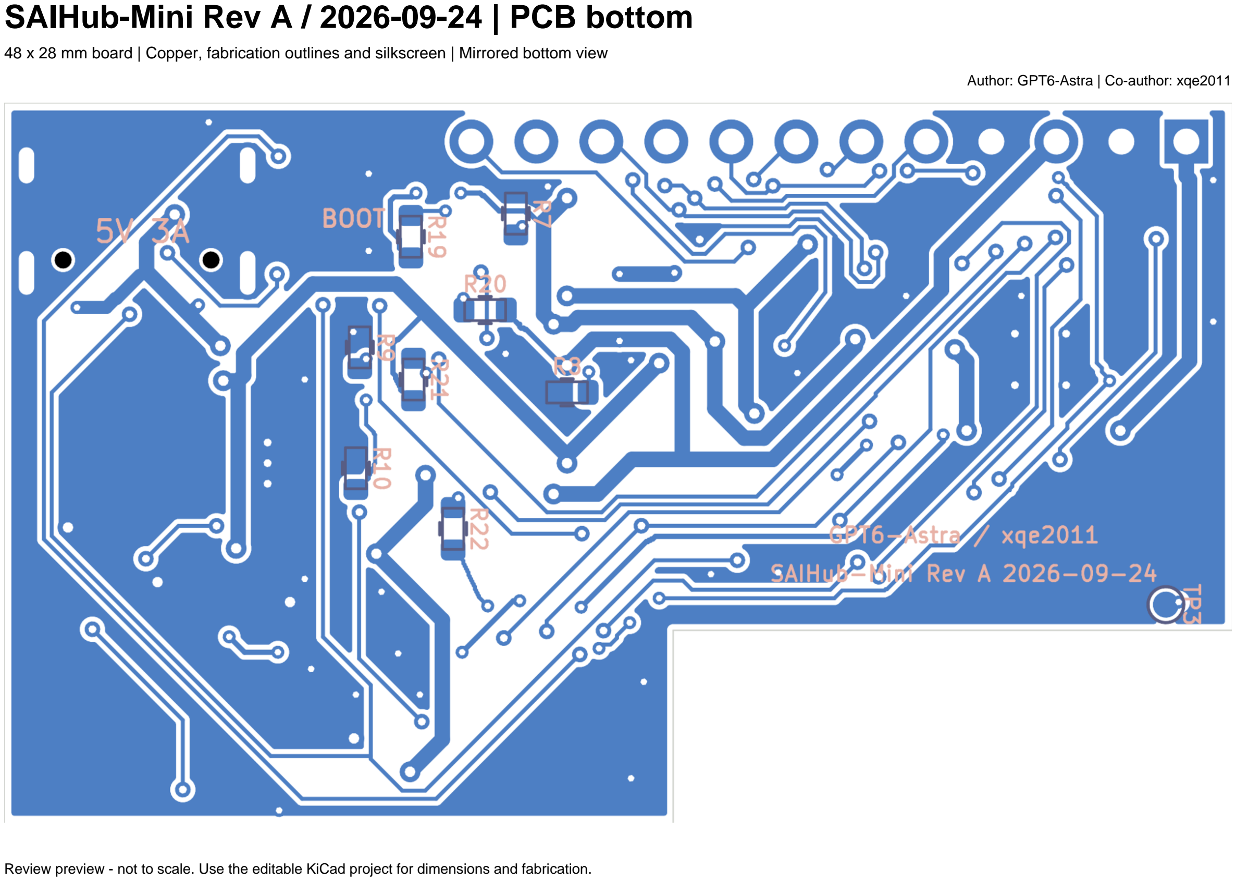
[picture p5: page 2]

48 x 28 mm board | Copper, fabrication outlines and silkscreen | Mirrored bottom view
Author: GPT6-Astra | Co-author: xqe2011

Review preview - not to scale. Use the editable KiCad project for dimensions and fabrication.

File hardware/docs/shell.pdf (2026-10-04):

SAIHub Mini | Shell and assembly

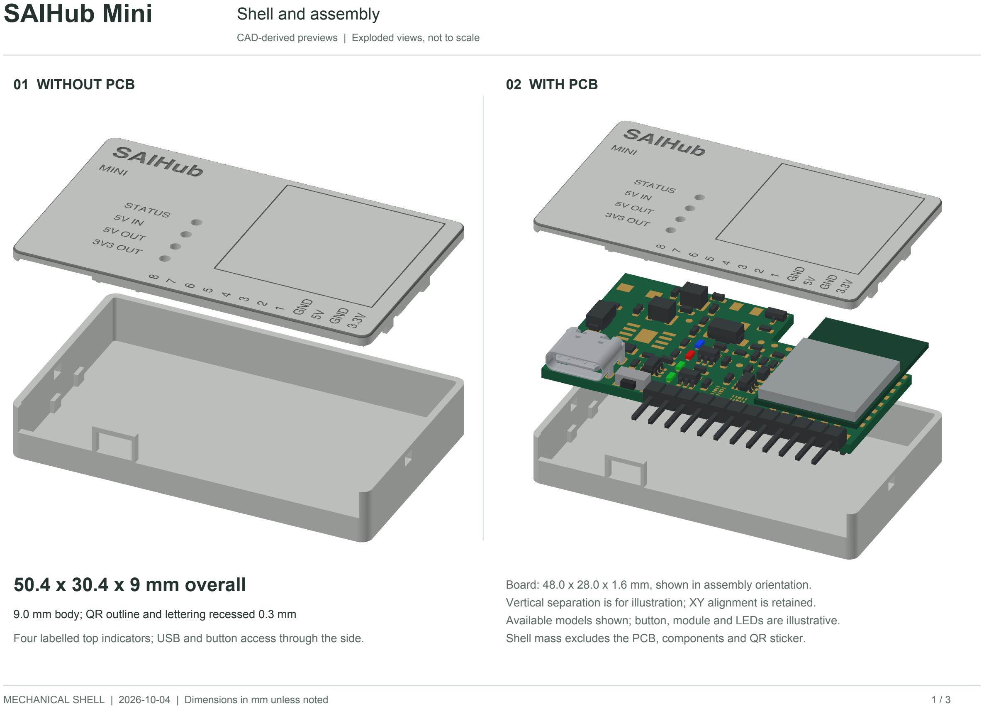
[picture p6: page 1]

CAD-derived previews | Exploded views, not to scale
MECHANICAL SHELL | 2026-10-04 | Dimensions in mm unless noted | 1 / 3
01 WITHOUT PCB | 02 WITH PCB

## 50.4 x 30.4 x 9 mm overall

9.0 mm body; QR outline and lettering recessed 0.3 mm

Four labelled top indicators; USB and button access through the side.

Board: 48.0 x 28.0 x 1.6 mm, shown in assembly orientation. Vertical separation is for illustration; XY alignment is retained. Available models shown; button, module and LEDs are illustrative. Shell mass excludes the PCB, components and QR sticker.

SAIHub Mini | Three-view drawing

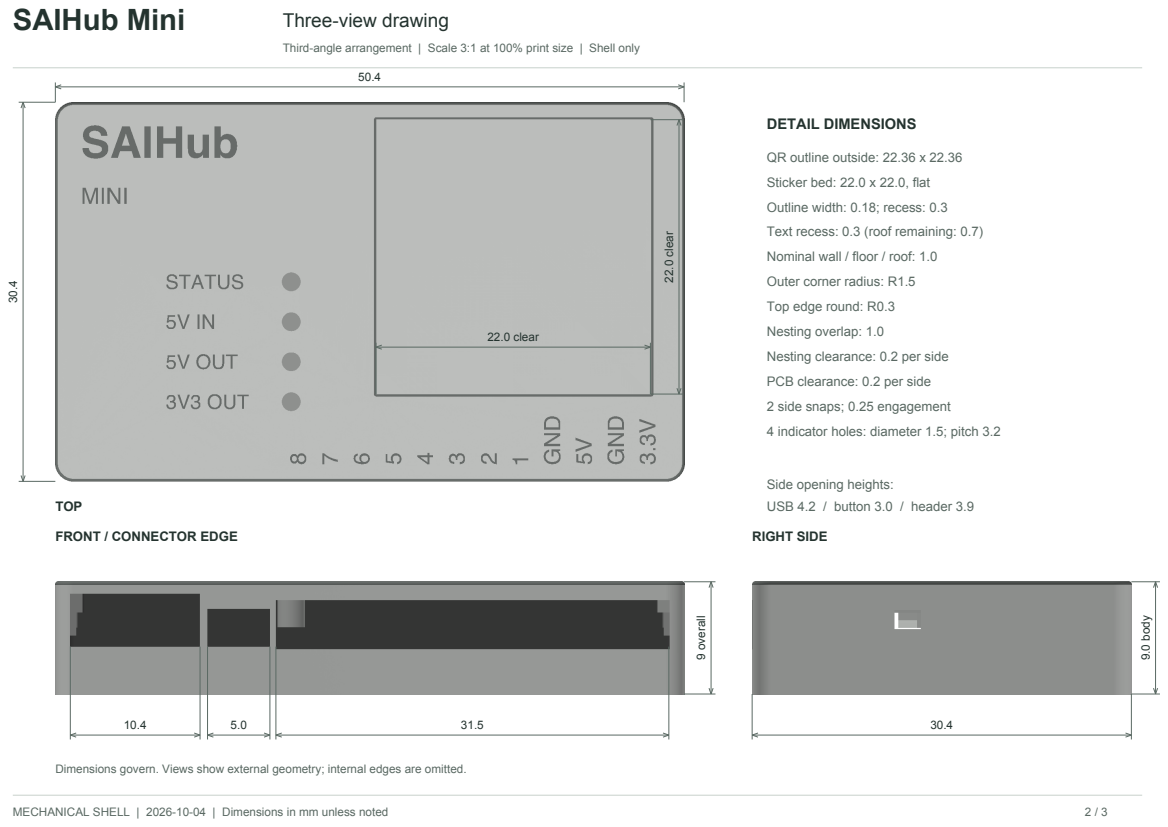
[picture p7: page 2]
MECHANICAL SHELL | 2026-10-04 | Dimensions in mm unless noted; TOP; FRONT / CONNECTOR EDGE; RIGHT SIDE; 9 overall; 9.0 body; 22.0 clear; DETAIL DIMENSIONS; Nesting overlap: 1.0

Third-angle arrangement | Scale 3:1 at 100% print size | Shell only

QR outline outside: 22.36 x 22.36

Sticker bed: 22.0 x 22.0, flat

Outline width: 0.18; recess: 0.3

Text recess: 0.3 (roof remaining: 0.7)

Nominal wall / floor / roof: 1.0

Outer corner radius: R1.5

Top edge round: R0.3

Nesting clearance: 0.2 per side

PCB clearance: 0.2 per side

2 side snaps; 0.25 engagement

4 indicator holes: diameter 1.5; pitch 3.2

Side opening heights:
USB 4.2 / button 3.0 / header 3.9

Dimensions govern. Views show external geometry; internal edges are omitted.

SAIHub Mini | ABS mass and fit notes
| Calculated from the final CAD solids | No printer-specific slicing performed
MECHANICAL SHELL | 2026-10-04 | Dimensions in mm unless noted | 3 / 3

# 4.33 g

## Nominal finished shell mass

Base + cover, ABS at 1.04 g/cm3

CALCULATION

Mass = CAD material volume / 1000 x ABS density

Total material volume: 4.15914 cm3

1 mm skins and walls assumed fully filled by extrusion.

The empty enclosure cavity is already excluded from volume.

PART | MATERIAL VOLUME | ESTIMATED ABS MASS
Base | 2.369 cm3 | 2.46 g
Cover | 1.790 cm3 | 1.86 g
TOTAL | 4.159 cm3 | 4.33 g

PRINT ESTIMATE

Excludes supports, brim, purge, PCB, components and sticker.

Actual mass varies with filament density, line width, gaps and flow.

Do not multiply this thin-wall estimate by a general infill percentage.

Use the slicer's filament mass for the final chosen print settings.

FIT CHECKS

Valid connected solids; closed STL meshes.

No overlaps with the board or available component references.

Some component models are missing or illustrative.

Prototype-test side snaps, solder tails and repeated lid removal.

Release: press both side windows, then lift the cover.

Snap arms: 7.5 x 0.6 x 1.2 mm; vertical play: 0.2 mm.

Density source: PolyLite ABS Technical Data Sheet, V5.5, 1.04 g/cm3 at 23 C.

Open manufacturer data sheet (https://polymaker.com/wp-content/uploads/lana-downloads/PolyLite-ABS_TDS_EN_V5.5.pdf)

Geometry source: hardware/mechanical/enclosure.py and reference/pcb.step. Nominal, not production-toleranced.

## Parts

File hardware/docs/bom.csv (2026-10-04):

Reference | Quantity | Value | MPN_or_procurement_spec | Footprint | Notes | Datasheet
J1 | 1 | USB4105-GF-A | USB4105-GF-A | Saihub:USB_C_Receptacle_GCT_USB4105-xx-A_16P_TopMnt_Horizontal | ; top assembly | https://gct.co/files/drawings/usb4105.pdf
R1, R2 | 2 | 5.1k | Generic 5.1k ohm, 1%, 0603, >=0.1W | Saihub:R_0603_1608Metric | 1%, 0603; top assembly
U1, U10 | 2 | USBLC6-2SC6 | USBLC6-2SC6 | Saihub:SOT-23-6 | ; top assembly; Header power ESD shunt; place beside J2 with short ground return; top assembly | https://www.st.com/resource/en/datasheet/usblc6-2.pdf
C1, C3, C5, C7, C9, C10, C13, C15, C21 | 9 | 100n | Generic 100nF, X7R, >=10V, +/-10%, 0603 | Saihub:C_0603_1608Metric | X7R, 10V minimum; top assembly; X7R, 10V minimum; local ESD supply bypass; top assembly
R3, R4 | 2 | 22 | Generic 22 ohm, 1%, 0603, >=0.1W | Saihub:R_0603_1608Metric | 1%, 0603; top assembly
F1 | 1 | 3A fuse | 0467003.NR | Saihub:Fuse_1206_3216Metric | Littelfuse 467, 3A fast fuse; top assembly | https://www.littelfuse.com/~/media/electronics/datasheets/fuses/littelfuse_fuse_467_datasheet.pdf
D2 | 1 | SMF5.0A | SMF5.0A | Saihub:D_SOD-123F | ; top assembly | https://www.yint-electronic.com/products/emsproduct/tvs/smf5-0a.html
U2 | 1 | SGM6232YPS8G/TR | SGM6232YPS8G/TR | Saihub:SGM6232_SOIC8_EP | EN open for auto-start; 3.314V divider; exposed pad GND; top assembly | https://www.sg-micro.com/rect/assets/9fe04e94-334c-4982-964b-fc08001cd9ac/SGM6232.pdf
L1 | 1 | 4.7uH | SRP5030TA-4R7M | Saihub:SRP5030TA | Shielded 5.7x5.2x2.8mm; 4.6A Irms, 6A Isat per manufacturer drawing; top assembly | https://bourns.com/docs/product-datasheets/SRP5030TA.pdf
D1, D3 | 2 | SS34 | SS34 | Saihub:D_SMA | MDD SS34, 40V / 3A, SMA (DO-214AC); do not substitute SMC variants; top assembly | https://datasheet.lcsc.com/datasheet/pdf/dfa1ff67dea875d0135103ba9ada713a.pdf?productCode=C8678
C2 | 1 | 22u | Generic 22uF, X7R, >=10V, +/-10%, 1210 | Saihub:C_1210_3225Metric | X7R, 10V minimum; top assembly
C4 | 1 | 47u | Generic 47uF, X7R, >=10V, +/-10%, 1210 | Saihub:C_1210_3225Metric | X7R, 10V minimum; top assembly
R15 | 1 | 33k | Generic 33k ohm, 1%, 0603, >=0.1W | Saihub:R_0603_1608Metric | 1%, 0603; top assembly
R16 | 1 | 10.5k | Generic 10.5k ohm, 1%, 0603, >=0.1W | Saihub:R_0603_1608Metric | 1%, 0603; top assembly
R5, R6, R9, R10, R12, R17 | 6 | 10k | Generic 10k ohm, 1%, 0603, >=0.1W | Saihub:R_0603_1608Metric | 1%, 0603; top assembly; 1%, 0603; bottom assembly
R18 | 1 | 10 | Generic 10 ohm, 1%, 0603, >=0.1W | Saihub:R_0603_1608Metric | 1%, 0603; top assembly
C14 | 1 | 10n | Generic 10nF, X7R, >=10V, +/-10%, 0603 | Saihub:C_0603_1608Metric | X7R, 10V minimum; top assembly
C16 | 1 | 5.6n | Generic 5.6nF, X7R, >=10V, +/-10%, 0603 | Saihub:C_0603_1608Metric | X7R, 10V minimum; top assembly
U3 | 1 | ESPC5-12-H4 | ESPC5-12-H4 | Saihub:ESPC5-12-H4 | 16 x 24 mm module; built-in PCB antenna over bottom-left board cutout; top assembly | https://atta.szlcsc.com/upload/public/pdf/source/20251016/3D572157C42EA1AA3992B58D4700E12F.pdf
C6 | 1 | 10u | Generic 10uF, X7R, >=10V, +/-10%, 0805 | Saihub:C_0805_2012Metric | X7R, 10V minimum; top assembly
C8, C11, C12 | 3 | 1u | Generic 1uF, X7R, >=10V, +/-10%, 0603 | Saihub:C_0603_1608Metric | X7R, 10V minimum; top assembly
SW1 | 1 | BOOT | TS-2435VS | Saihub:SW_SPST_TS2435VS | C47734518; side-push, no locating posts; manufacturer PCB land pattern; top assembly | https://atta.szlcsc.com/upload/public/pdf/source/20250414/8774CEBD0F324351C3CF1F5D7421BC0B.pdf
J2 | 1 | 1x12 2.54mm right-angle | 61301211021 | Saihub:PinHeader_1x12_P2.54mm_Horizontal | Wurth WR-PHD 2.54mm 1x12 right-angle male; top assembly | https://www.we-online.com/components/products/datasheet/61301211021.pdf
U4, U5 | 2 | TPS2553DDBVR | TPS2553DDBVR | Saihub:SOT-23-6 | ; top assembly | https://www.ti.com/lit/ds/symlink/tps2553d.pdf
R7, R8 | 2 | 26.1k | Generic 26.1k ohm, 1%, 0603, >=0.1W | Saihub:R_0603_1608Metric | 1%, 0603; bottom assembly
BZ1 | 1 | KLJ-5020 3.3V | KLJ-5020 | Saihub:KLJ-5020 | ; top assembly | https://datasheet.lcsc.com/datasheet/pdf/5a334e56ebfeea427b46ed3bd7f9e2de.pdf?productCode=C556937
Q1 | 1 | AO3400A | AO3400A | Saihub:SOT-23 | ; top assembly | https://www.aosmd.com/sites/default/files/res/datasheets/AO3400A.pdf
R11 | 1 | 100 | Generic 100 ohm, 1%, 0603, >=0.1W | Saihub:R_0603_1608Metric | 1%, 0603; top assembly
D4, D5 | 2 | GREEN | AA1608LCGSK | Saihub:LED_AA1608 | Low-current indicator; 1.6 x 0.8 x 0.55 mm; cathode pad 1; top assembly | https://www.kingbrightusa.com/images/catalog/SPEC/AA1608LCGSK.pdf
R19 | 1 | 680 | Generic 680 ohm, 1%, 0603, >=0.1W | Saihub:R_0603_1608Metric | 1%, 0603; bottom assembly
R20, R21 | 2 | 1.5k | Generic 1.5k ohm, 1%, 0603, >=0.1W | Saihub:R_0603_1608Metric | 1%, 0603; bottom assembly
D6 | 1 | RED | AA1608LSURSK | Saihub:LED_AA1608 | Low-current indicator; 1.6 x 0.8 x 0.55 mm; cathode pad 1; top assembly | https://www.kingbrightusa.com/images/catalog/SPEC/AA1608LSURSK.pdf
D7 | 1 | BLUE | AA1608LQBS/D-295V | Saihub:LED_AA1608 | Low-current indicator; 1.6 x 0.8 x 0.55 mm; cathode pad 1; top assembly | https://www.kingbrightusa.com/images/catalog/SPEC/AA1608LQBS-D-295V.pdf
R22 | 1 | 330 | Generic 330 ohm, 1%, 0603, >=0.1W | Saihub:R_0603_1608Metric | 1%, 0603; bottom assembly
U6, U7 | 2 | TPD4E05U06DQAR | TPD4E05U06DQAR | Saihub:TPD4E05U06_DQA | Four GPIO ESD shunts; USON-10 2.5x1mm; no supply required; top assembly | https://www.ti.com/lit/ds/symlink/tpd4e05u06.pdf

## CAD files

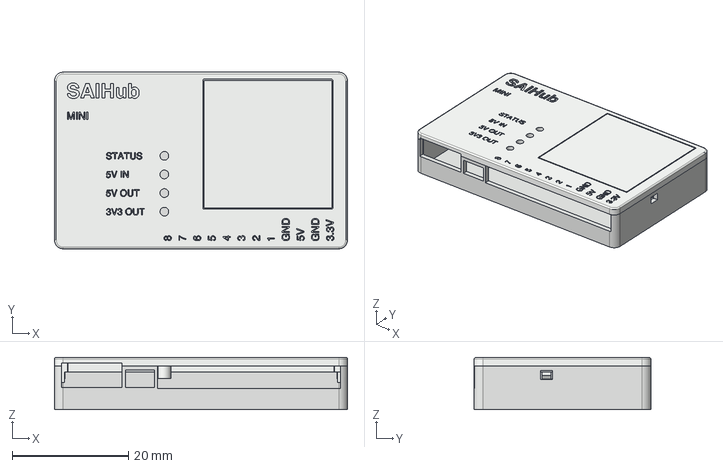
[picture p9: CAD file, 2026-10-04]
hardware/mechanical/output/assembly.step
50.4 x 30.4 x 9.00 mm
Base
Cover

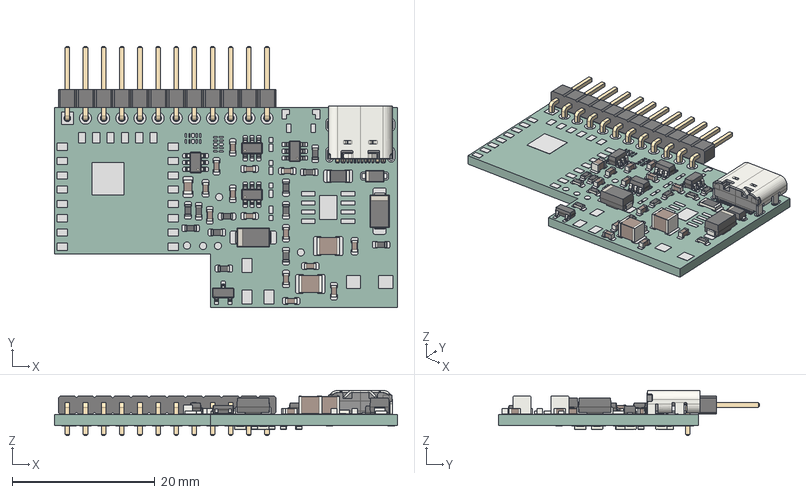
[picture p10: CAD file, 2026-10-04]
hardware/mechanical/reference/pcb.step
48.0 x 36.5 x 6.31 mm
C_0603_1608Metric x 14
R_0603_1608Metric x 20
SOT-23-6 x 4
D_SMA x 2
PinHeader_1x12_P254mm_Horizontal
SOT-23
Fuse_1206_3216Metric
C_0805_2012Metric
D_SOD_123F
C_1210_3225Metric x 2
USB_C_Receptacle_16P_TopMnt_Horizontal_GCT_USB4105-xx-A
saihub_pad
saihub_PCB

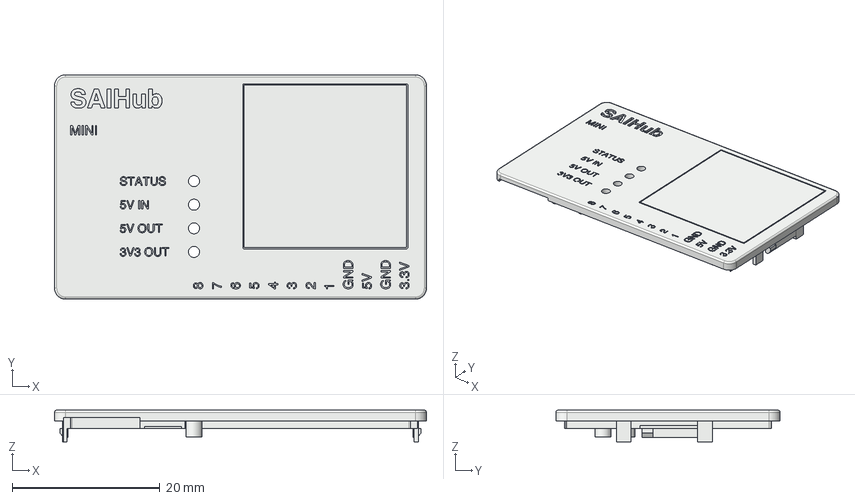
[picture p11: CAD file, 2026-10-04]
hardware/mechanical/output/cover.step
50.4 x 30.4 x 4.30 mm

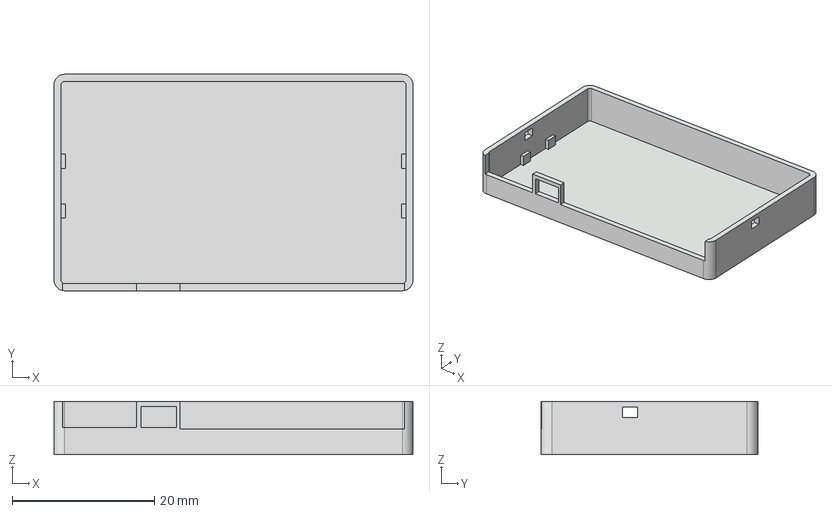
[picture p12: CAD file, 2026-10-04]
hardware/mechanical/output/base.step
50.4 x 30.4 x 7.50 mm

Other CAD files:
hardware/mechanical/output/base.stl
hardware/mechanical/output/cover.stl

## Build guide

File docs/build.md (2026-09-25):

# Build guide

Developer reference for the firmware and the Cloudflare Worker relay. End-user setup lives in the [cookbook](cookbook.md); the relay wire protocol is documented in the [design notes](design-notes.md).

[中文](build.zh.md) · [README](../README.md)

## Firmware

ESP-IDF ≥ 5.5, target ESP32-C5:

```bash
idf.py set-target esp32c5
idf.py build
idf.py merge-bin   # merged image for the web flasher (flash at 0x0)
```

Separate images, if not using a merged binary: bootloader `0x2000`, partition table `0x8000`, app `0x10000`.

Board-specific configuration is concentrated in `main/include/config.h`:

| Define | Purpose |
| --- | --- |
| `CONFIG_GPIO_LOGICAL_TO_HW` | Logical IO0–IO7 → chip GPIO map; array length = number of exposed pins |
| `CONFIG_BUTTON_PIN` | BOOT button (click = Wi-Fi pairing) |
| `CONFIG_GPIO_POWER_3V3_PIN` / `CONFIG_GPIO_POWER_5V_PIN` | Load-switch enables for the 3V3 / 5V rails |
| `CONFIG_BUZZER_PIN` | Buzzer |
| `CONFIG_CLOUD_URL` | Relay origin, `ws://` or `wss://` without a path; empty disables the relay. Self-hosting requires changing it and rebuilding |
| `CONFIG_WIFI_SSID` / `CONFIG_WIFI_PASSWORD` | Wi-Fi seed credentials, used whenever NVS has none saved |

Building for a board other than SAIHub-Mini: [bring your own board](bring-your-own-board.md).

Pushing a git tag runs [`.github/workflows/firmware-release.yml`](../.github/workflows/firmware-release.yml). The tag name is written to `version.txt` (the firmware version string) and the merged image is published as a GitHub Release. If GitHub Environment `cloud` has variable `ADMIN_URL` (admin origin including `/admin`, e.g. `https://example.com/admin`) and secret `ADMIN_TOKEN`, a parallel job runs `bun run upload-file-cache -- <adminUrl> <token> <version>` from `cloud/cloudflare` (POSTs `mcp.json` and `openapi.json` to `{ADMIN_URL}/file-cache`). If either is unset, the upload is skipped.

## Cloudflare Worker

Requires [Bun](https://bun.sh) (or Node) and [Wrangler](https://developers.cloudflare.com/workers/wrangler/). Production deploy steps: [cookbook §5](cookbook.md#5-self-host-the-cloudflare-relay).

```bash
cd cloud/cloudflare
bun install
bun run dev            # applies local D1 migrations, then wrangler dev → http://127.0.0.1:8787
```

For a dev loop, point the firmware's `CONFIG_CLOUD_URL` at your machine over the LAN, e.g. `ws://<your-lan-ip>:8787`. Copy `.dev.vars.example` to `.dev.vars` for local `ROUTING_TOKEN_SECRET` and `ADMIN_TOKEN`. Production secrets are set on the Deploy to Cloudflare setup page — never commit a real secret.

`wrangler.jsonc` binds the `DEVICE` Durable Object (SQLite class), a D1 database (`device_whitelist` and `file_cache`), and `AUTH_TIMEOUT_MS` / `REQUEST_TIMEOUT_MS` (10 s / 55 s); devices not in the whitelist get 403. `file_cache` is keyed by firmware `version` plus filename (`mcp.json`, `openapi.json`); a hit answers MCP `tools/list` and `GET /openapi.json` without waking the board. `wrangler.test.jsonc` deploys a separate `saihub-cloud-test` worker with 2 s timeouts for integration tests.

### Checks and tests

```bash
bun run typecheck       # tsc --noEmit
bun run test            # tests/cloud/cloudflare/*.test.ts (client flow, headroom)
bun run test:hardware   # tests/hardware/smoke.ts
```

### Local fake device

```bash
bun run fake-device     # defaults to http://127.0.0.1:8787; pass another origin as an argument
```

`tests/cloud/cloudflare/fake-device.ts` implements the full relay protocol (ECDSA auth, proxy, MCP) without a physical board; its identity is persisted in `.fake-device-key.json` so the digest stays stable across runs. `fragment-device.mjs` is a Node helper the tests use to exercise fragmented (streamed) device responses.

### Routes the worker exposes

| Route | Role |
| --- | --- |
| `GET /.well-known/oauth-authorization-server` | OAuth metadata |
| `GET /.well-known/oauth-protected-resource[/device/<digest>/mcp]` | RFC 9728 resource metadata |
| `POST /register`, `POST /token` | MCP OAuth — static client, routing-token code exchange |
| `GET /cloud/oauth/redirect` | Browser pairing page / OAuth redirect |
| `GET /cloud/oauth/echo` | OAuth callback that displays the routing token |
| `POST /cloud/pairing/session`, `POST /cloud/pairing/token` | Button pairing flow, proxied to the device |
| `GET /cloud/landing/{digest}/page` | Public landing page with MCP, REST, and OpenAPI URLs |
| `GET /cloud/landing/{digest}/online` | `{ "online": true or false }` — authenticated WebSocket attached |
| `GET /cloud/device/{digest}` | Device WebSocket — no bearer; the challenge handshake authenticates |
| `/device/{digest}/…` | Proxied REST + `/mcp` — bearer routing token, JSON only |
| `GET /admin` | Admin UI — enter `ADMIN_TOKEN` to manage the device whitelist and file cache |
| `GET /admin/devices/whitelist?page=` | whitelist (`Authorization: Bearer <ADMIN_TOKEN>`) |
| `POST /admin/devices/whitelist` | Add `{ "digest" }` to the whitelist |
| `DELETE /admin/devices/whitelist/{digest}` | Remove a digest from the whitelist |
| `GET /admin/file-cache?page=` | Cached `mcp.json` / `openapi.json` rows (`version`, `filename`, `bytes`) |
| `POST /admin/file-cache` | Upload `{ "version", "filename", "content" }` (`mcp.json` or `openapi.json`; upsert) |
| `DELETE /admin/file-cache/{version}/{filename}` | Remove a cached file |

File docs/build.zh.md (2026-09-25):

# 构建指南

面向开发者的固件与 Cloudflare Worker 中继构建参考。普通用户的配置流程见[使用手册](cookbook.zh.md)；中继协议细节见[设计笔记](design-notes.md)（英文）。

[English](build.md) · [README](../README.zh.md)

## 固件

需要 ESP-IDF ≥ 5.5，目标芯片 ESP32-C5：

```bash
idf.py set-target esp32c5
idf.py build
idf.py merge-bin   # 生成网页烧录器使用的合并镜像（烧到 0x0）
```

如果不使用合并镜像，各分区单独烧录的偏移为：bootloader `0x2000`、分区表 `0x8000`、应用 `0x10000`。

与板子相关的配置全部集中在 `main/include/config.h`：

| 宏定义 | 作用 |
| --- | --- |
| `CONFIG_GPIO_LOGICAL_TO_HW` | 逻辑引脚 IO0–IO7 → 芯片 GPIO 的映射；数组长度即暴露的引脚数 |
| `CONFIG_BUTTON_PIN` | BOOT 按键（按一下 = Wi-Fi 配对） |
| `CONFIG_GPIO_POWER_3V3_PIN` / `CONFIG_GPIO_POWER_5V_PIN` | 3V3 / 5V 两路负载开关的使能脚 |
| `CONFIG_BUZZER_PIN` | 蜂鸣器 |
| `CONFIG_CLOUD_URL` | 中继源站，`ws://` 或 `wss://` 开头、不带路径；留空则禁用中继。自行部署时必须修改并重新编译 |
| `CONFIG_WIFI_SSID` / `CONFIG_WIFI_PASSWORD` | Wi-Fi 凭据种子，仅在 NVS 中没有已保存凭据时使用 |

为 SAIHub-Mini 以外的板子编译：见[自备开发板](bring-your-own-board.zh.md)。

推送 git tag 会跑 [`.github/workflows/firmware-release.yml`](../.github/workflows/firmware-release.yml)。tag 名写入 `version.txt`（固件 version 字符串），合并镜像发布为 GitHub Release。若 GitHub Environment `cloud` 配有变量 `ADMIN_URL`（含 `/admin` 的管理地址，例如 `https://example.com/admin`）和密钥 `ADMIN_TOKEN`，会在 `cloud/cloudflare` 下执行 `bun run upload-file-cache -- <adminUrl> <token> <version>`（把 `mcp.json` 和 `openapi.json` POST 到 `{ADMIN_URL}/file-cache`）。缺任一配置则跳过上传。

## Cloudflare Worker

需要 [Bun](https://bun.sh)（或 Node）和 [Wrangler](https://developers.cloudflare.com/workers/wrangler/)。生产环境部署步骤见[使用手册第 5 节](cookbook.zh.md#5-自行部署-cloudflare-中继)。

```bash
cd cloud/cloudflare
bun install
bun run dev            # 先应用本地 D1 迁移，再 wrangler dev → http://127.0.0.1:8787
```

本地联调时，把固件的 `CONFIG_CLOUD_URL` 指向局域网里你的电脑，例如 `ws://<你的局域网IP>:8787`。把 `.dev.vars.example` 复制为 `.dev.vars`，供 `wrangler dev` 使用本地的 `ROUTING_TOKEN_SECRET` 和 `ADMIN_TOKEN`。生产密钥在 Deploy to Cloudflare 配置页填写，切勿提交真实密钥。

`wrangler.jsonc` 绑定 `DEVICE` Durable Object（SQLite 类）、D1 数据库（`device_whitelist` 与 `file_cache`），并设置 `AUTH_TIMEOUT_MS` / `REQUEST_TIMEOUT_MS`（10 s / 55 s）；不在白名单中的设备会收到 403。`file_cache` 以固件 `version` 加文件名（`mcp.json`、`openapi.json`）为键；命中时 MCP `tools/list` 和 `GET /openapi.json` 不必转发到设备。`wrangler.test.jsonc` 会部署独立的 `saihub-cloud-test` Worker（超时 2 s），专供集成测试。

### 检查与测试

```bash
bun run typecheck       # tsc --noEmit
bun run test            # tests/cloud/cloudflare/*.test.ts（客户端流程、headroom 队列）
bun run test:hardware   # tests/hardware/smoke.ts
```

### 本地模拟设备

```bash
bun run fake-device     # 默认连 http://127.0.0.1:8787，也可传入其他源站作为参数
```

`tests/cloud/cloudflare/fake-device.ts` 无需实体板子即可实现完整的中继协议（ECDSA 鉴权、代理、MCP）；身份持久化在 `.fake-device-key.json`，因此 digest 在多次运行间保持稳定。`fragment-device.mjs` 是测试用的 Node 辅助脚本，用来验证分片（流式）设备响应。

### Worker 提供的路由

| 路由 | 作用 |
| --- | --- |
| `GET /.well-known/oauth-authorization-server` | OAuth 元数据 |
| `GET /.well-known/oauth-protected-resource[/device/<digest>/mcp]` | RFC 9728 资源元数据 |
| `POST /register`、`POST /token` | MCP OAuth——静态客户端、routing-token 换 code |
| `GET /cloud/oauth/redirect` | 浏览器配对页 / OAuth 跳转 |
| `GET /cloud/oauth/echo` | OAuth 回调页，展示 routing token |
| `POST /cloud/pairing/session`、`POST /cloud/pairing/token` | 按键配对流程，转发到设备 |
| `GET /cloud/landing/{digest}/page` | 公开落地页，含 MCP、REST、OpenAPI 地址 |
| `GET /cloud/landing/{digest}/online` | `{ "online": true or false }`——当前是否有已鉴权的 WebSocket |
| `GET /cloud/device/{digest}` | 设备 WebSocket——无需 bearer，靠挑战握手鉴权 |
| `/device/{digest}/…` | 代理 REST 和 `/mcp`——需要 bearer routing token，仅限 JSON |
| `GET /admin` | 管理界面——输入 `ADMIN_TOKEN` 管理设备白名单和文件缓存 |
| `GET /admin/devices/whitelist?page=` | 白名单（`Authorization: Bearer <ADMIN_TOKEN>`） |
| `POST /admin/devices/whitelist` | 将 `{ "digest" }` 加入白名单 |
| `DELETE /admin/devices/whitelist/{digest}` | 从白名单删除 digest |
| `GET /admin/file-cache?page=` | 已缓存的 `mcp.json` / `openapi.json`（`version`、`filename`、`bytes`） |
| `POST /admin/file-cache` | 上传 `{ "version", "filename", "content" }`（`mcp.json` 或 `openapi.json`；覆盖写入） |
| `DELETE /admin/file-cache/{version}/{filename}` | 删除一条缓存 |

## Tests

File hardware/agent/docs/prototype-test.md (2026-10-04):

# Prototype acceptance record — NOT YET EXECUTED

Record board serial/revision, adapter model, cable model/length, firmware commit, ambient temperature and equipment. Attach scope captures and measured values. SAIHub-Mini Rev A is routed and CAD-checked; execute this procedure after fabrication. It uses nominal 1 A current limiting, with a calculated 0.908-1.081 A threshold range. Continuous operation at exactly 1 A is not guaranteed; record each channel’s onset and qualify a continuous load below the lower threshold.

1. **Unpowered inspection.** Verify all fitted parts are on top and the 5020 positive/negative/dummy lands match its drawing. Check D1/D2/D3 polarity, C2/C4 ceramic values and DC-bias characteristics, module orientation, pin-1 header direction, buzzer polarity, USB solder joints and exposed-pad soldering. Verify no VBUS/3.3 V/GND shorts. Verify the built-in antenna is above the open notch with no copper beneath it and 5 mm clearance to its right. Check startup, USB recovery and IO3/IO7 using this board’s updated firmware mapping.
2. **First startup.** Use a current-limited laboratory 5 V source first, outputs unloaded. Confirm GPIO8/9 are low from power application through firmware boot; both external rails must remain off under a modest discharge load. Measure always-on 3.3 V at C4 and the module. Then repeat with the actual specified 5 V/3 A adapter and intended cable.
3. **Flashing and recovery.** Connect to a PC with external outputs disabled and no external loads. Verify USB enumeration and flashing in both USB-C orientations. Hold BOOT while applying power, then while pulsing EN/GND reset pads. Verify normal reboot after releasing BOOT. No reset button is fitted.
4. **GPIO mapping.** On J2 pins 5–12, toggle each logical IO0–IO7 and verify only its mapped GPIO responds: 10,1,0,23,4,5,6,24. Exercise input/pull modes and the application's PWM/pulse functions. Use 3.3 V signals only. Check repeated reset does not inadvertently enable external power.
5. **Buzzer.** Use a test firmware PWM on GPIO12 at 4 kHz, 50% duty, for short bursts. Check silence when disabled and during reset; probe the drain to verify flyback clamping. Do not leave the transducer continuously energized with DC. Confirm buzzer operation while both external rails are disabled.
6. **Independent rail switching.** With the specified adapter, exercise OFF/OFF, ON/OFF, OFF/ON, ON/ON. Ramp each electronic load from 0 to 0.85 A independently, then approach 1 A to measure limit onset. Measure rail voltage at J2 and source voltage at USB. Switch each loaded output repeatedly while checking ESP32 uptime and the other output. Measure residual voltage/discharge after turnoff under the intended real load; there is no active discharge circuit.
7. **Current limit and short recovery.** Increase each load gradually and record limiting onset and TP5/TP6 fault assertion. Compare the measured threshold with the calculated 0.908-1.081 A bounds; do not demand 1 A continuous output from a unit whose protection starts below 1 A. With a current-limited source and a suitable shorting fixture, briefly short each output independently. Check current limiting, thermal cycling if applicable, fault release, and recovery after removing the short and toggling enable. Ensure the MCU and other rail recover without damage; record any reset as a failure to investigate. Never short unswitched USB input or always-on 3.3 V.
8. **Simultaneous stress.** Apply 0.85 A to each external rail initially; repeat near 1 A where the measured limit permits, run sustained Wi-Fi traffic on 2.4 and 5 GHz separately, and repeat with buzzer bursts. Test both cold startup into loads and enabling loads after boot. Run at least 30 minutes after temperature approaches equilibrium and repeat at the intended maximum ambient/enclosure condition. Record input current, USB voltage, both output voltages and temperatures of U2, L1, D1, C2/C4 and U4/U5. Input must remain within the 3 A adapter budget without source cycling or brownouts.
9. **SGM6232 acceptance gate.** At no load, each qualified continuous rail load, and simultaneous full loads plus Wi-Fi, capture startup, load-step response, minimum 3.3 V and ripple at C4 and at U3. Use a ground spring and 20 MHz bandwidth limit for ripple; also inspect unrestricted transients. Proposed engineering targets: steady rail 3.135–3.465 V, ripple ≤100 mV peak-to-peak, and no excursion outside the module's published operating supply range after startup. Capture EN timing relative to supply settling. Reject oscillation, failed startup, brownout or excessive temperature; set junction-temperature margins from measured case temperatures and manufacturer thermal data. Do not accept a rail rating merely because it works briefly at room temperature.
10. **Cable and hot-plug margin.** Repeat startup/load tests with the actual intended cable and the worst acceptable cable in the product specification. Capture VBUS and 3.3 V on insertion/removal, including both loads enabled by application software. The input bulk capacitor has no slew limiter; check inrush/source recovery and USB behavior explicitly. Use a data/power fixture with host VBUS isolated if observing USB data during adapter-powered stress; never tie adapter and PC power outputs together.

Record pass/fail for every item and measured limits. If 3.3 V fails under the required load, reduce the declared output current only with an explicit product decision, or revise the regulator/power input design. Verify at least 4.75 V at U2 IN under the qualified load, and separately investigate startup/dropout as input falls toward the 4.5 V specified minimum. CAD validation alone cannot accept the regulator dropout or thermal margin.

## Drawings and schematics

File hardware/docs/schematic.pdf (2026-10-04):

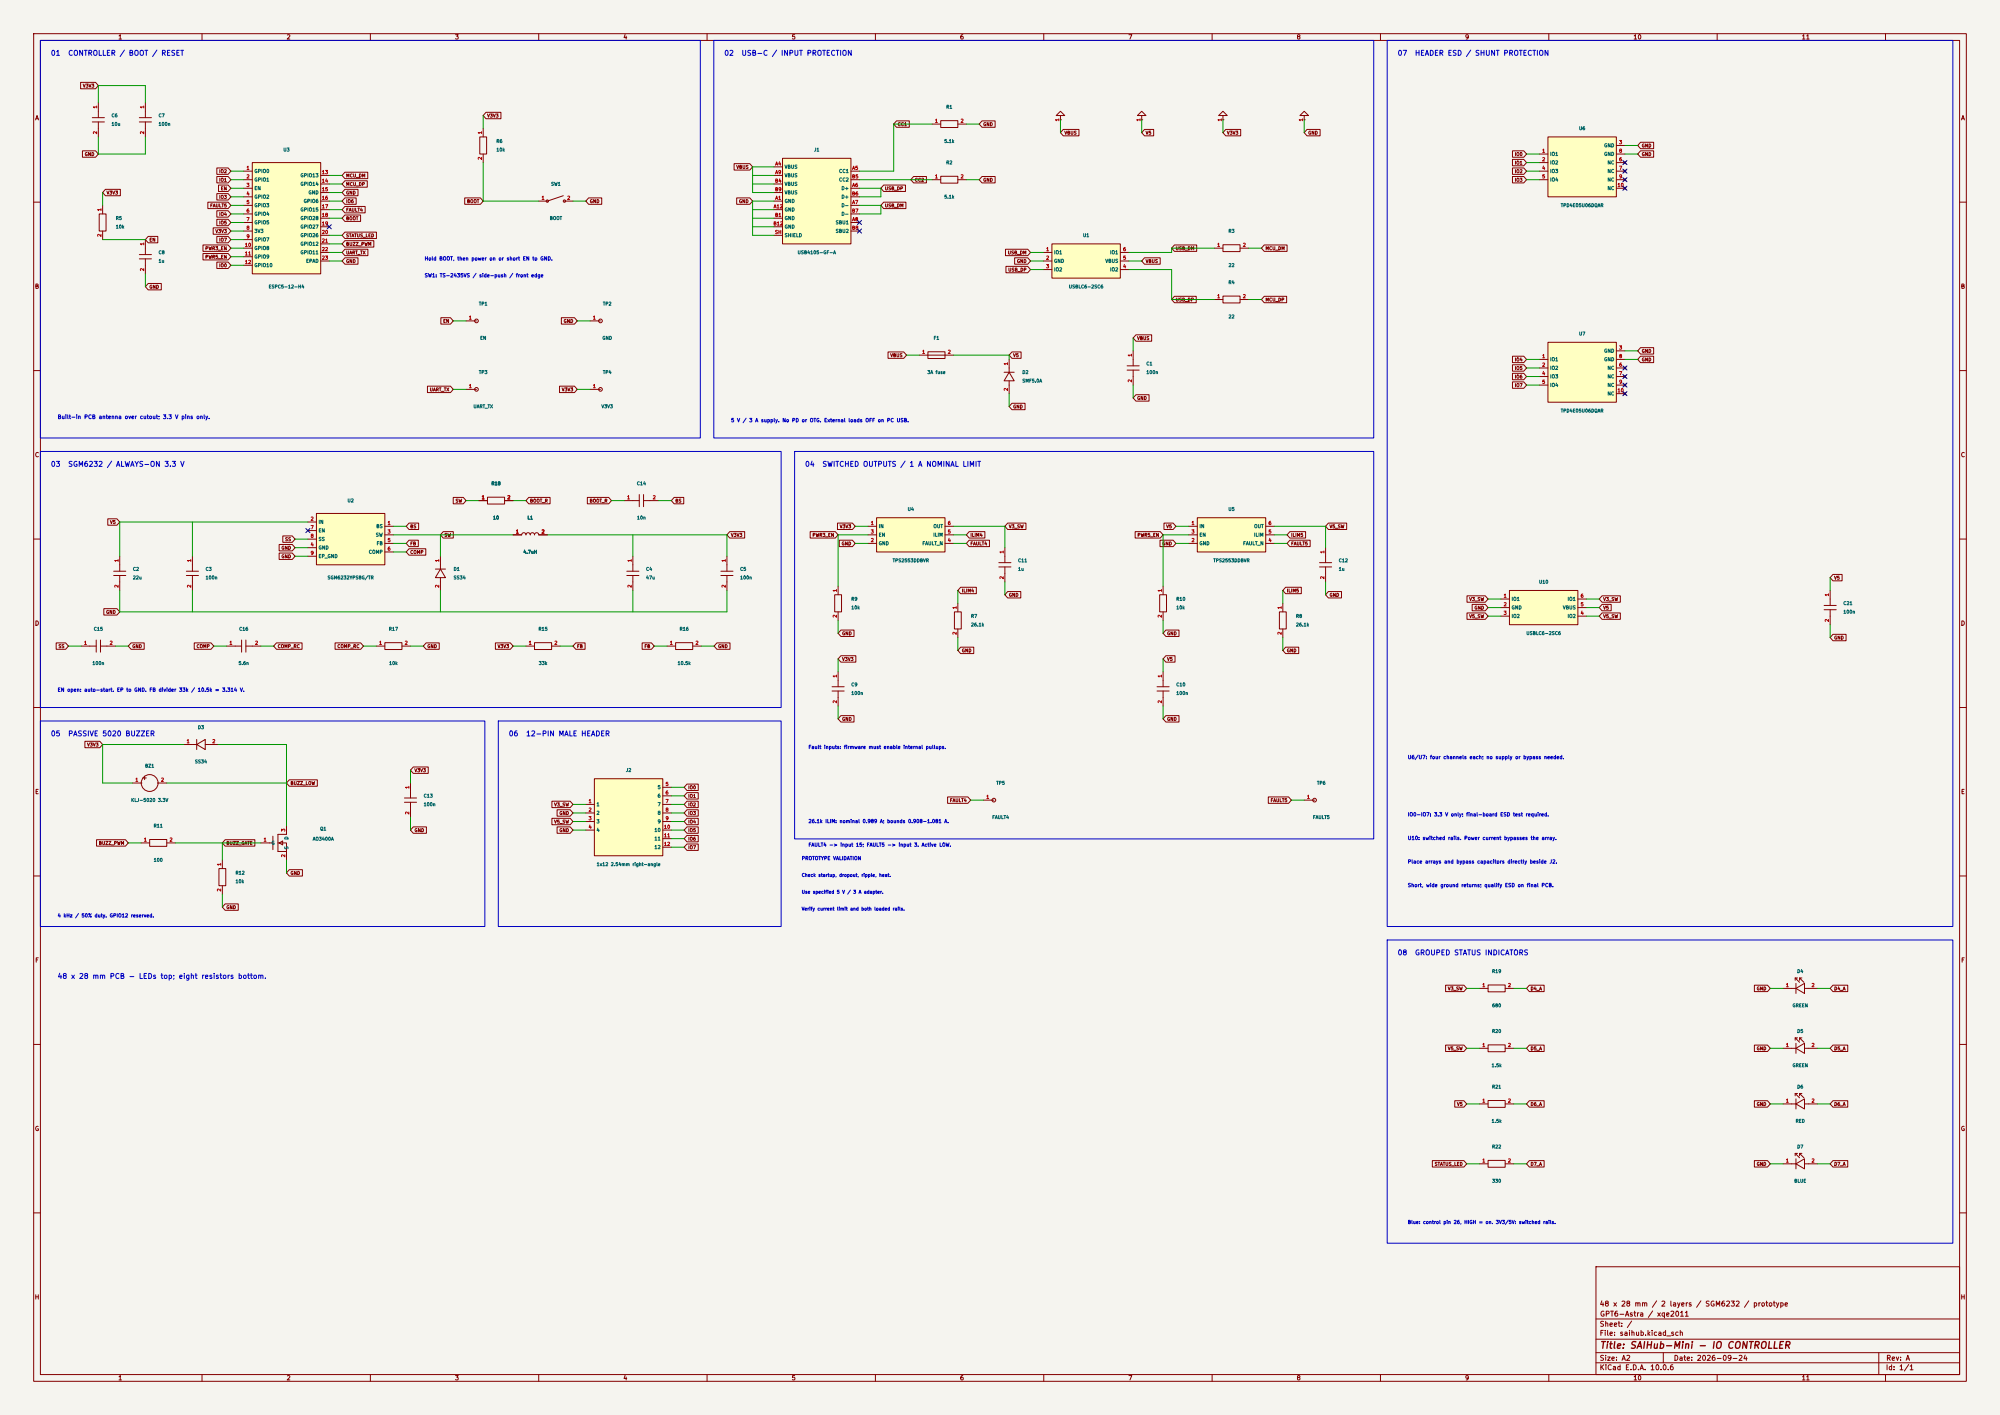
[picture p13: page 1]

07 HEADER ESD / SHUNT PROTECTION

Hold BOOT, then power on or short EN to GND. SW1: TS-2435VS / side-push / front edge Built-in PCB antenna over cutout; 3.3 V pins only.

5 V / 3 A supply. No PD or OTG. External loads OFF on PC USB.

04 SWITCHED OUTPUTS / 1 A NOMINAL LIMIT

Short, wide ground returns; qualify ESD on final PCB. Blue: control pin 26, HIGH = on. 3V3/5V: switched rails.

U10: switched rails. Power current bypasses the array.

Place arrays and bypass capacitors directly beside J2.

Check startup, dropout, ripple, heat.

48 x 28 mm / 2 layers / SGM6232 / prototype
GPT6-Astra / xqe2011
Sheet: /
File: saihub.kicad_sch
Title: SAIHub-Mini - IO CONTROLLER

Size: A2 | Rev: A
KiCad E.D.A. 10.0.6 | Id: 1/1

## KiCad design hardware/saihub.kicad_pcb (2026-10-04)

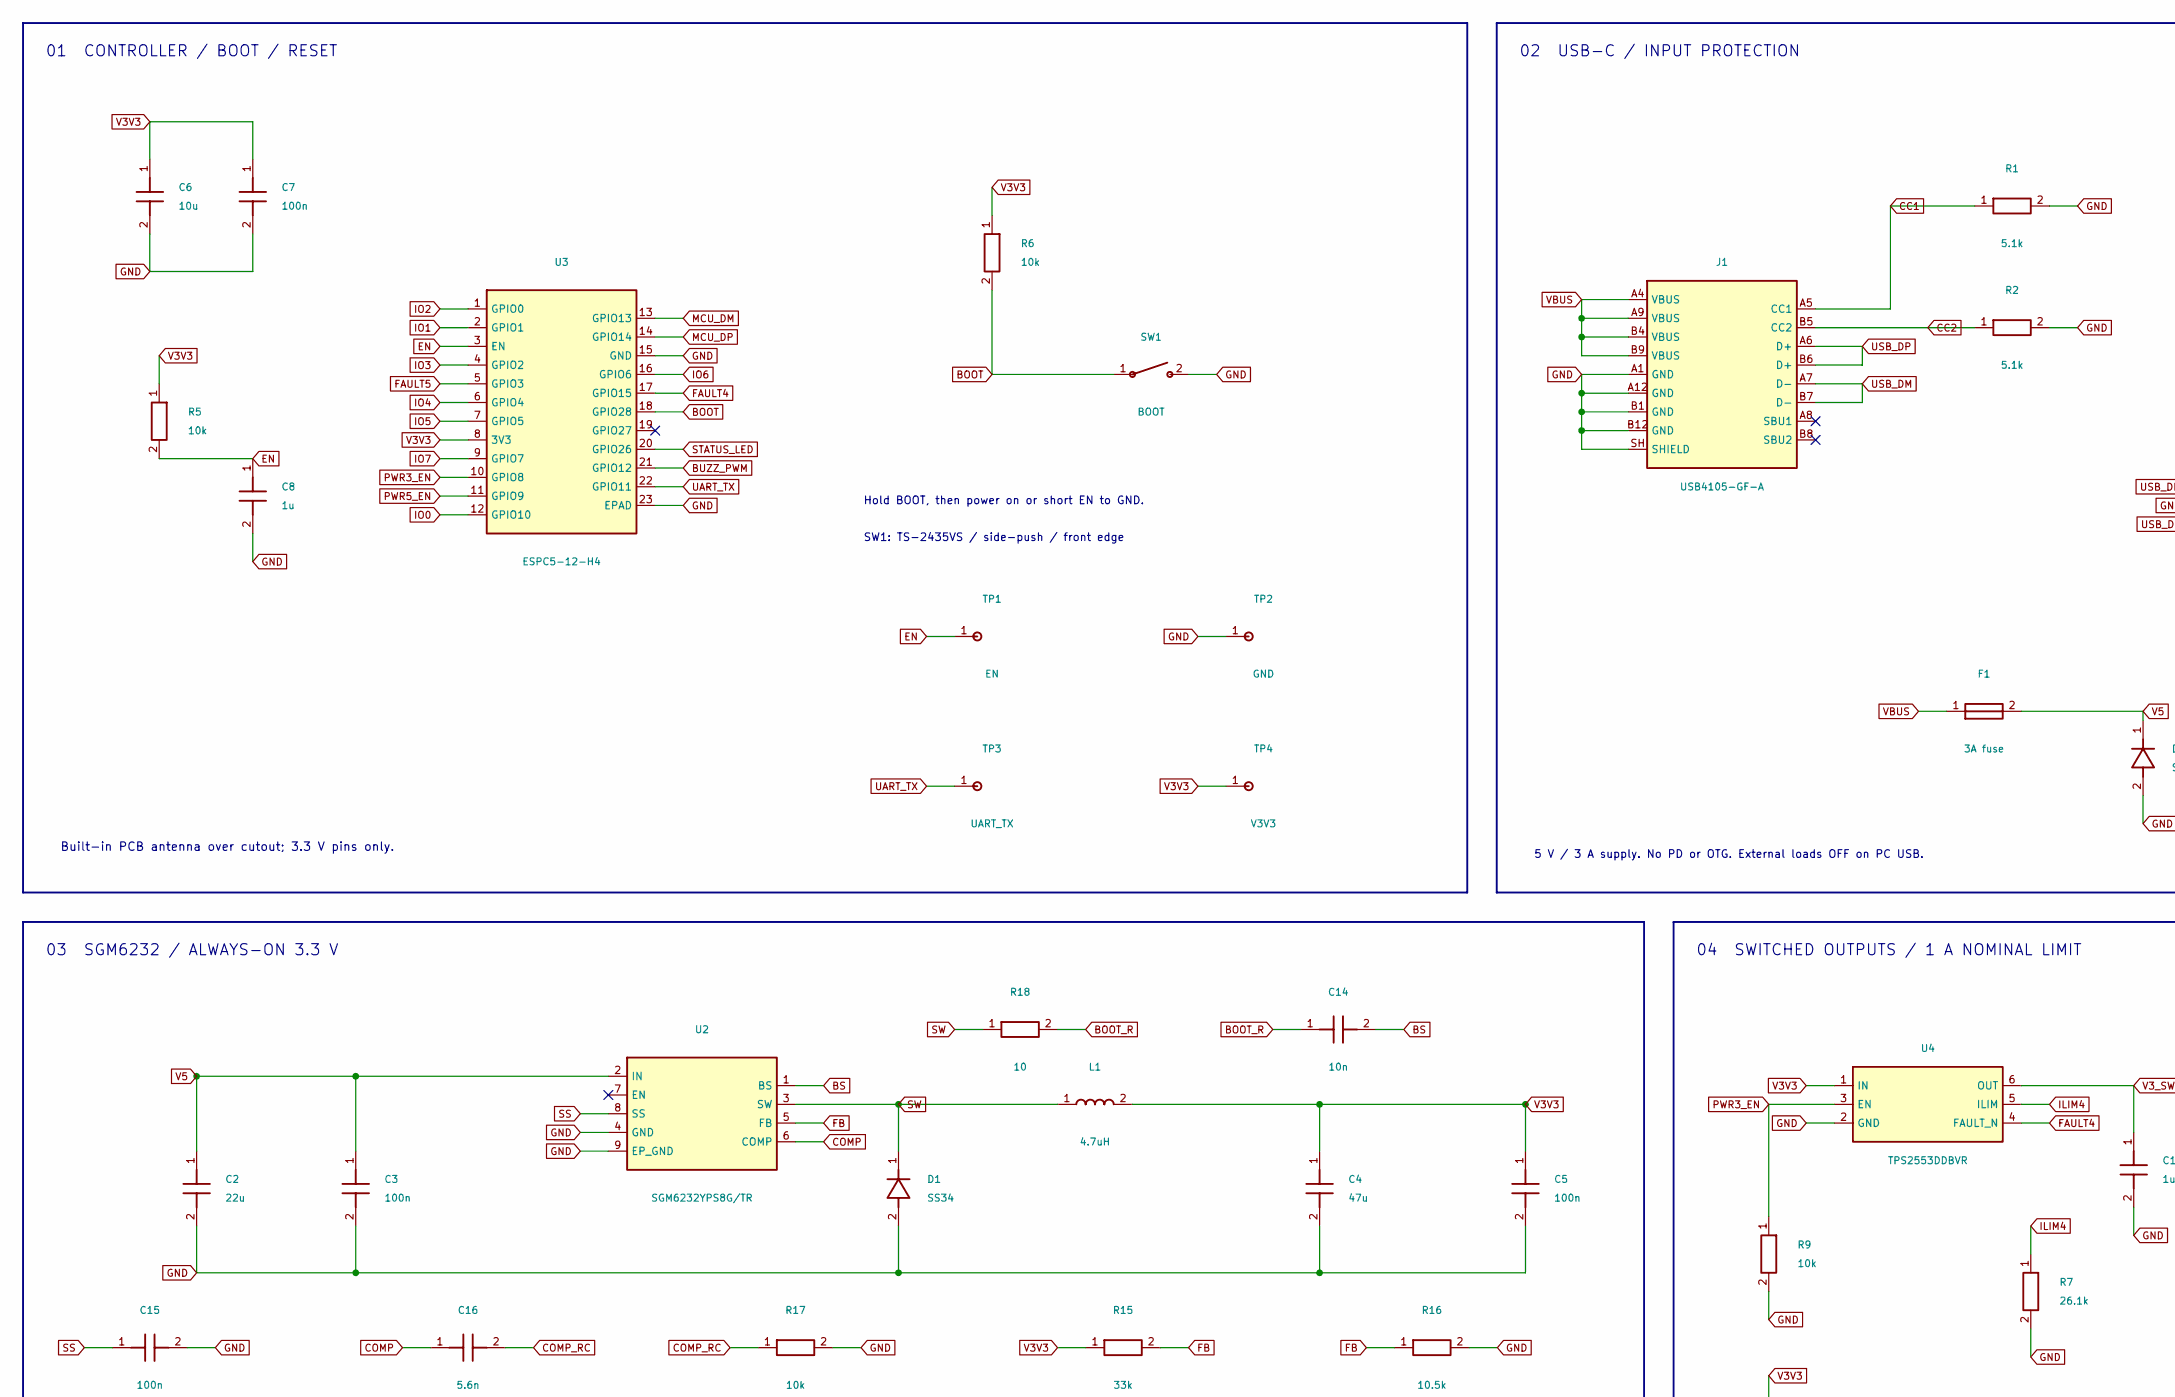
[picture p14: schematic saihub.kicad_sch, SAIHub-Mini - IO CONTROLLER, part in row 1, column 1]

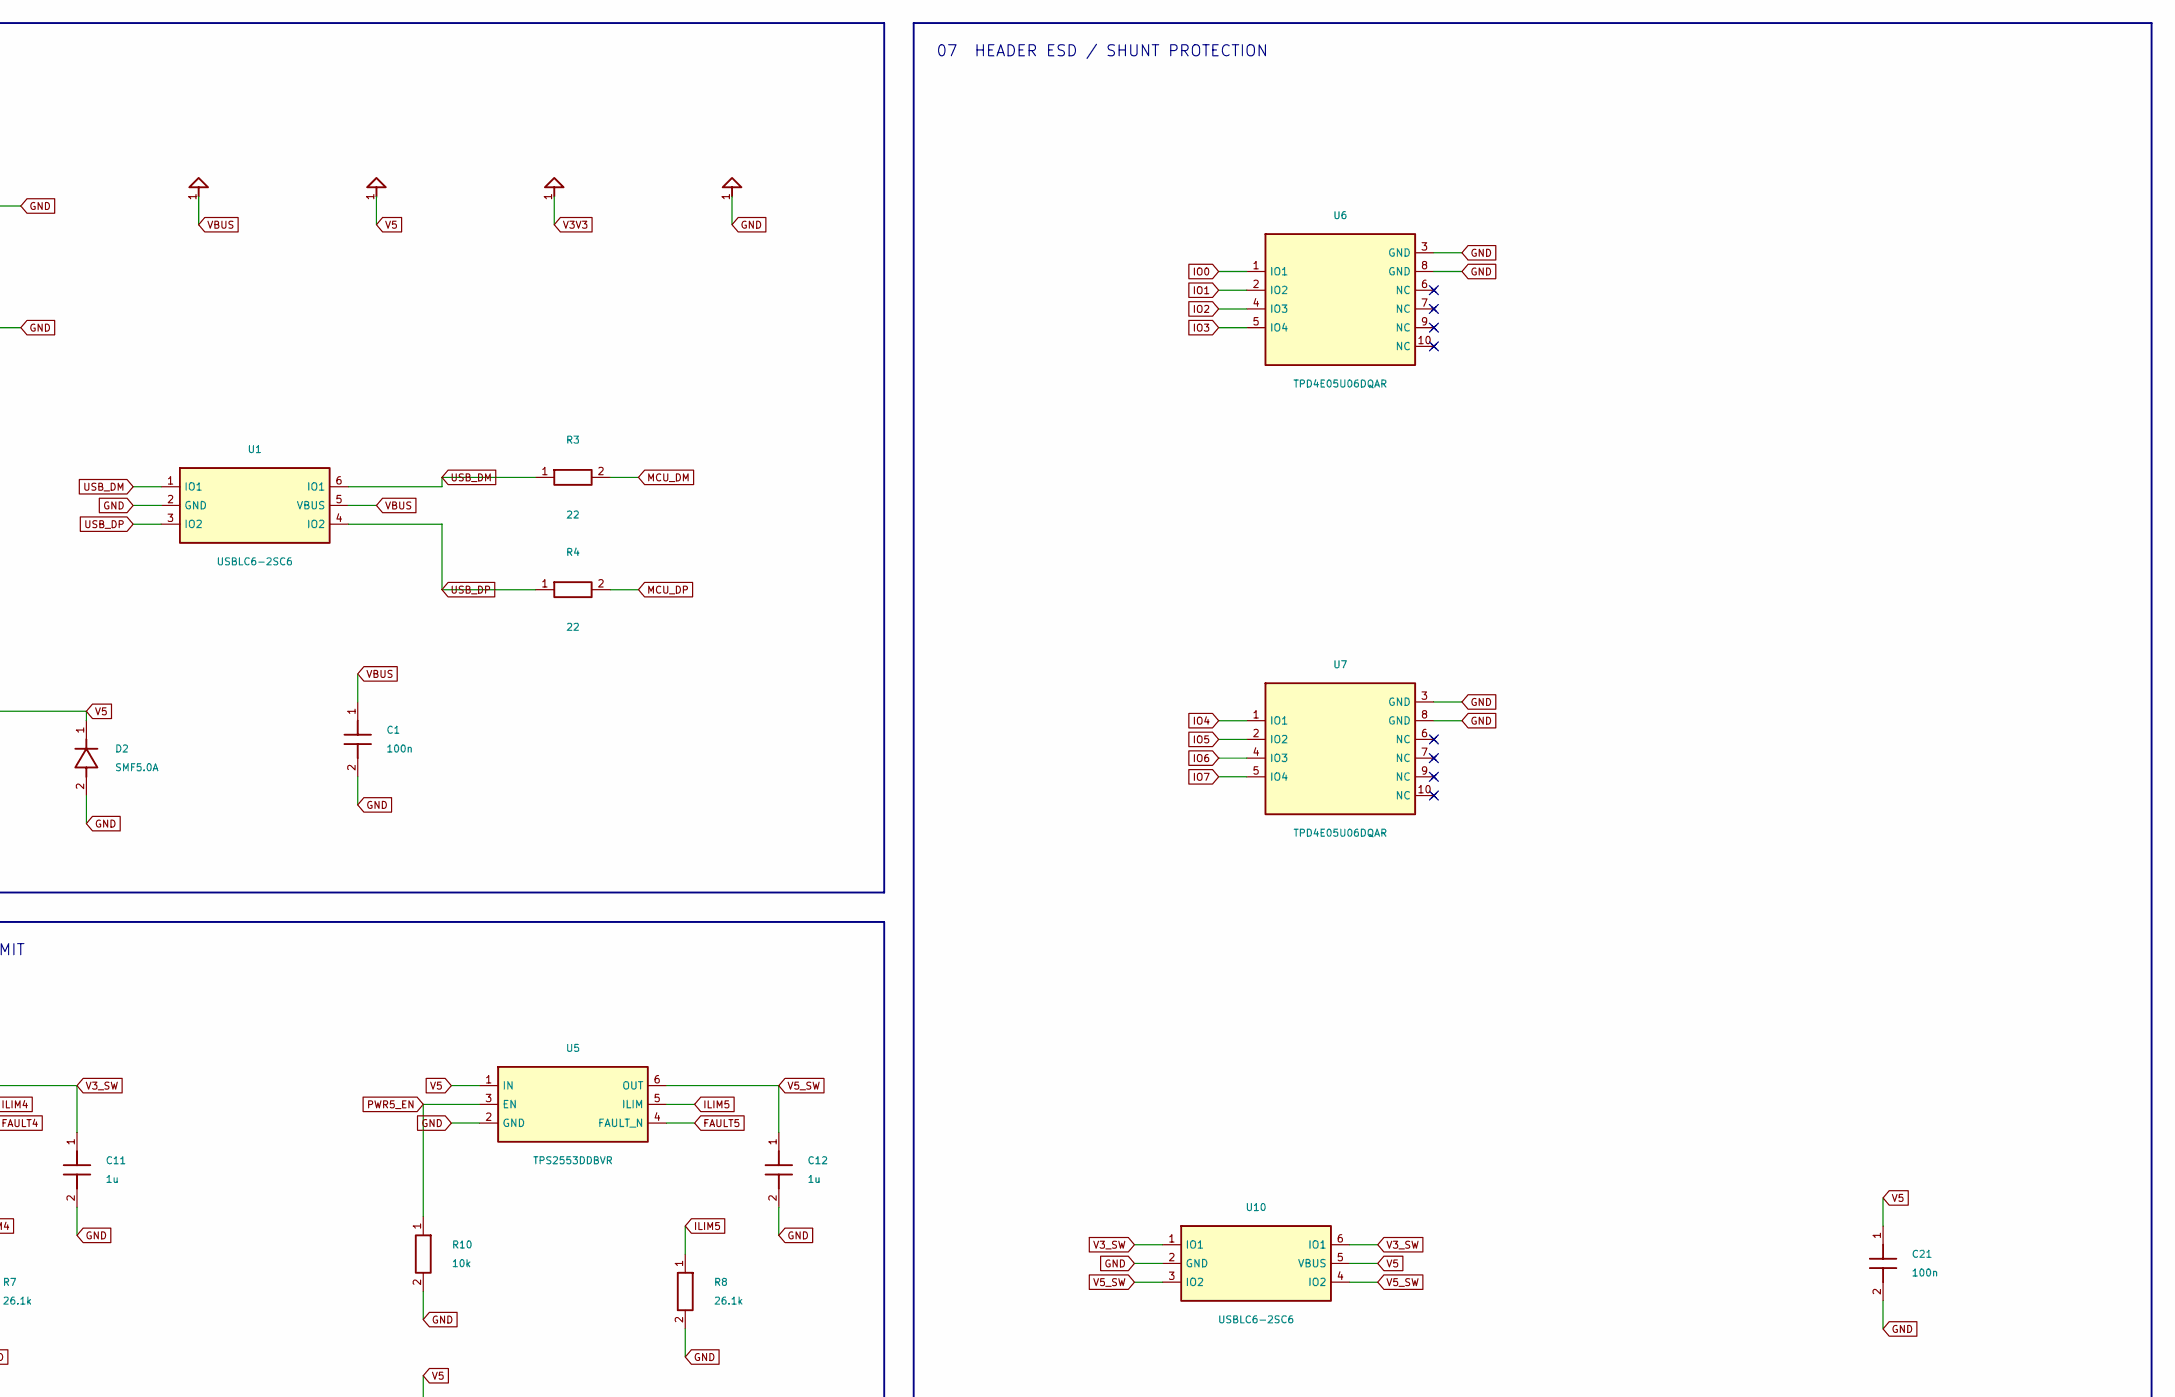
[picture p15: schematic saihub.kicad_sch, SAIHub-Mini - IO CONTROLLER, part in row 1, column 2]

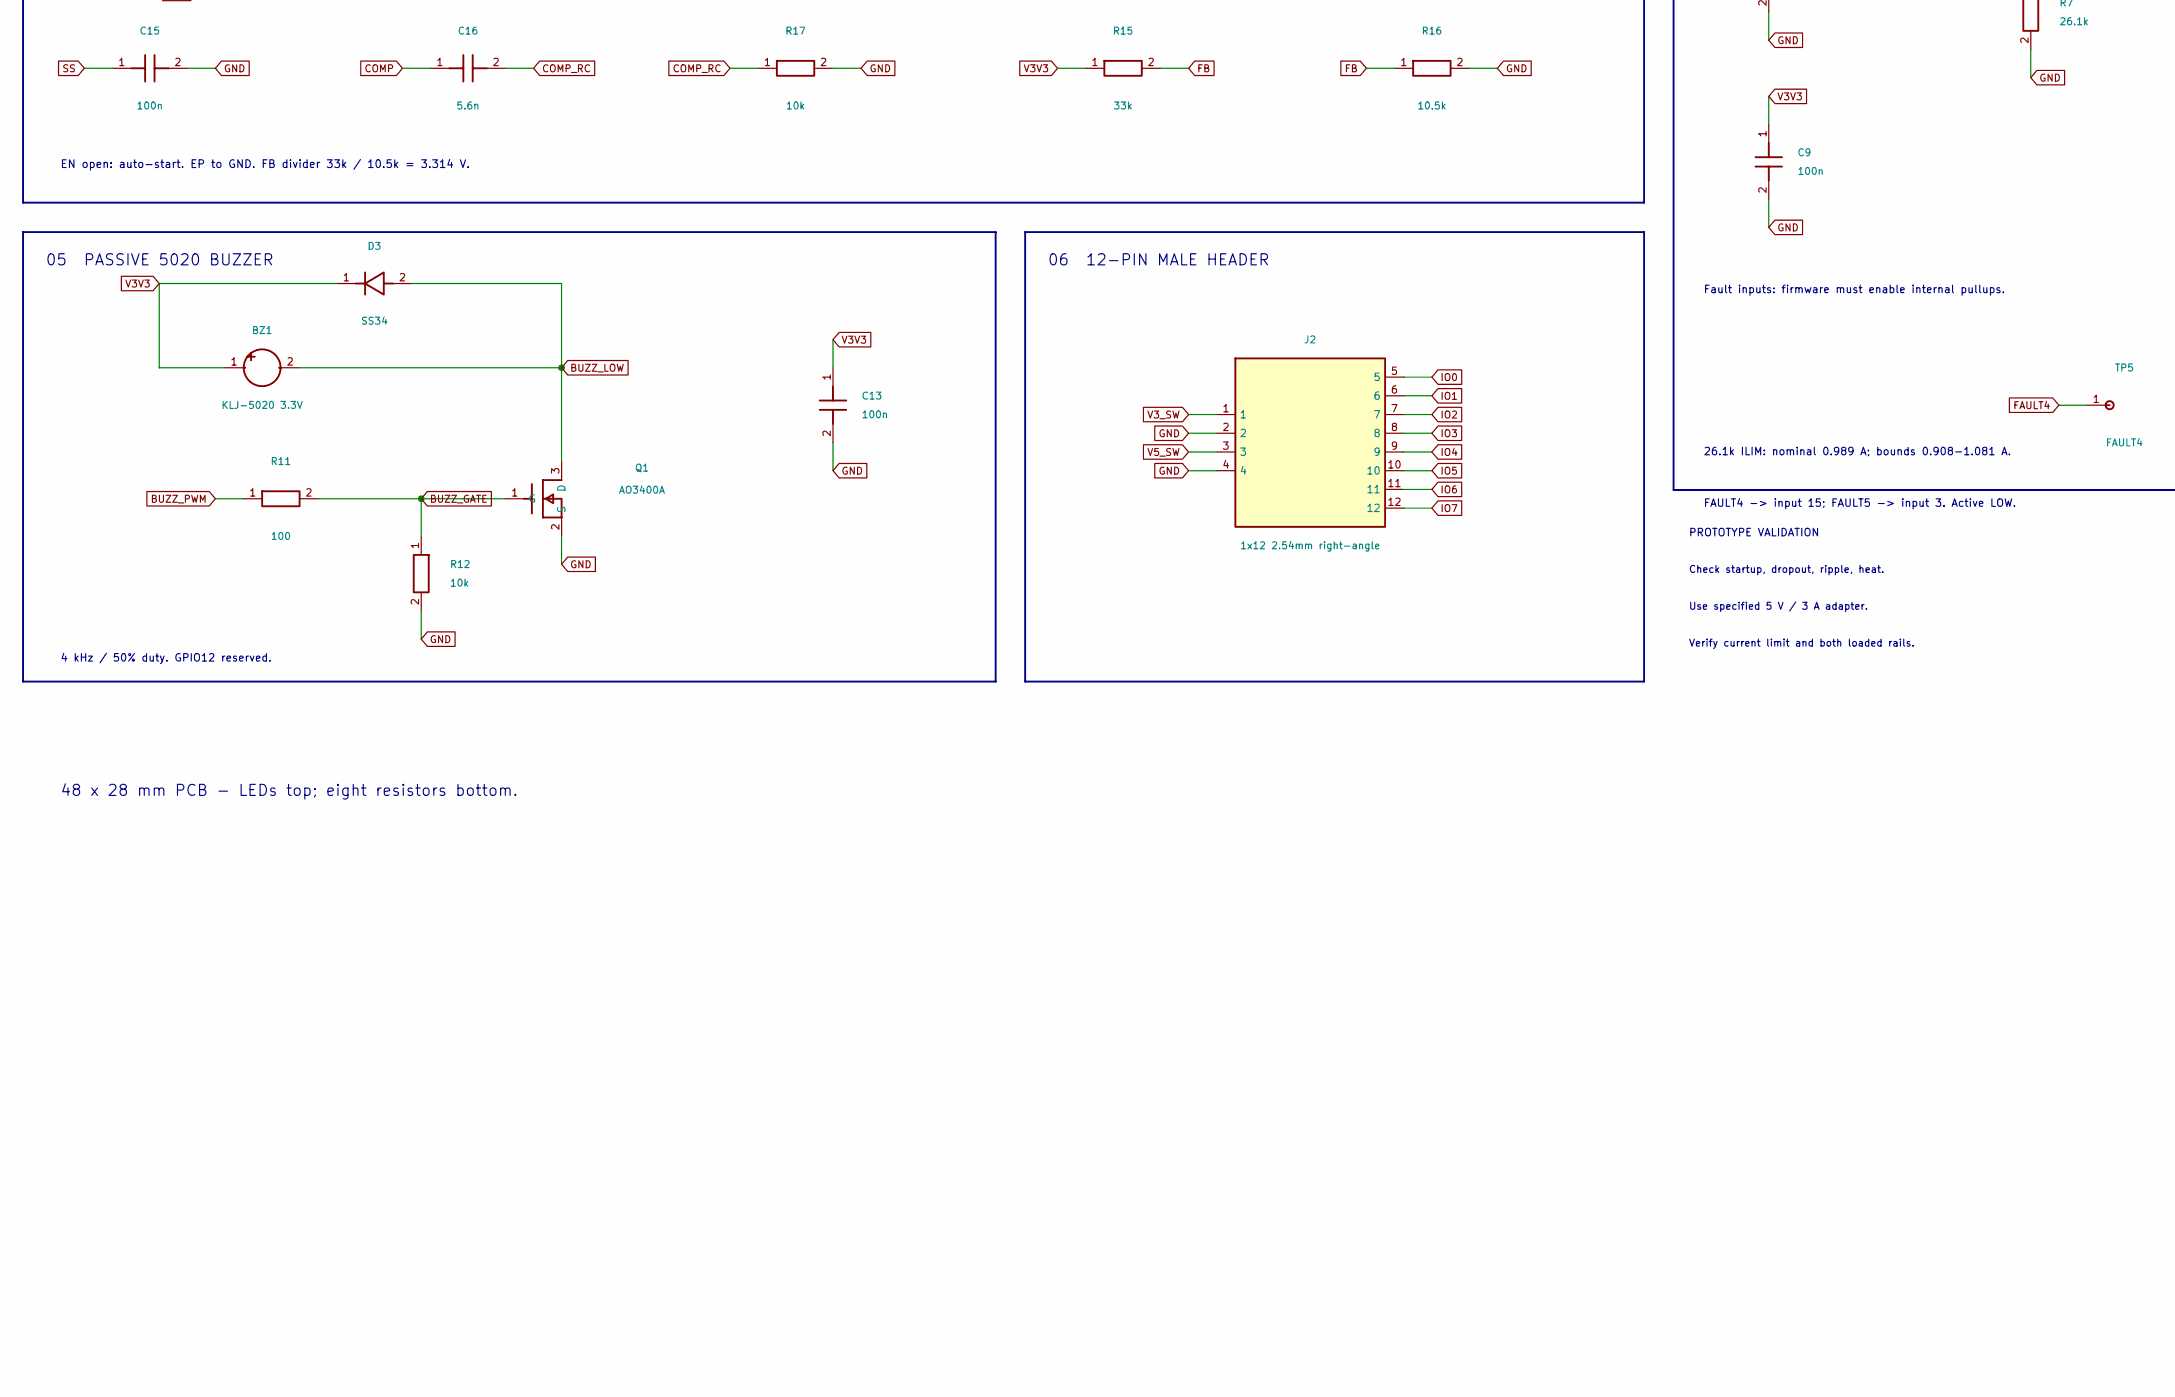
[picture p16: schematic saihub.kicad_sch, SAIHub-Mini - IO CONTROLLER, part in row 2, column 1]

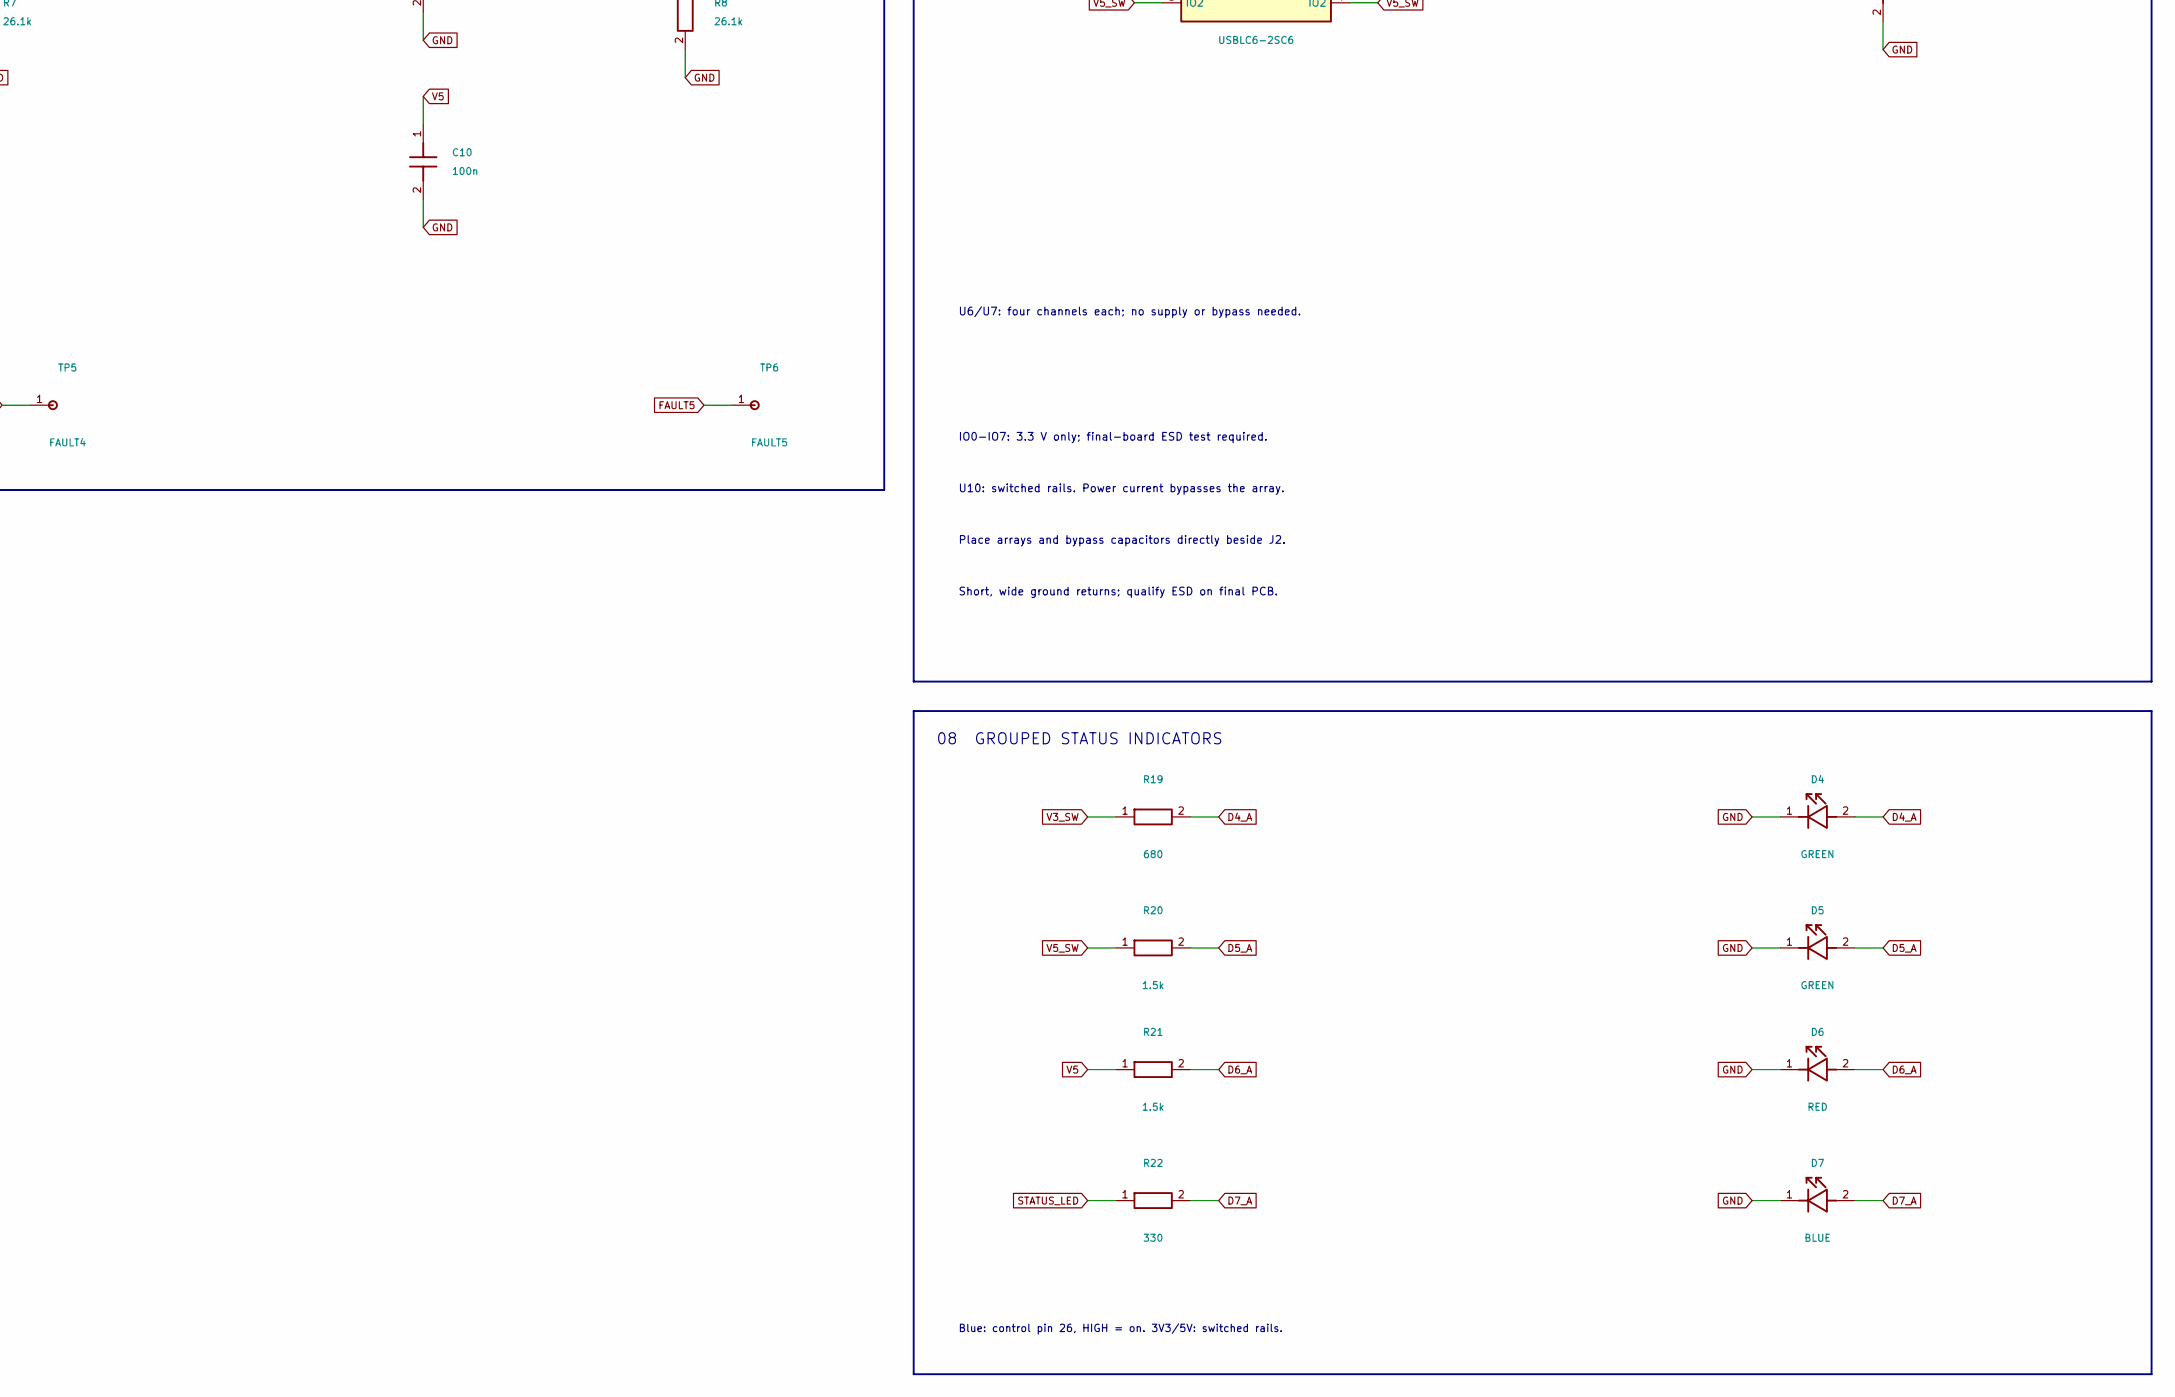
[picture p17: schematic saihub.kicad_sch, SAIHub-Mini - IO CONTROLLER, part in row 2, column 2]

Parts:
BZ1: KLJ-5020 3.3V; KLJ-5020; MPN KLJ-5020
C1, C3, C5, C7, C9, C10, C13, C15, C21: 100n; C_0603_1608Metric; MPN 100n
C2: 22u; C_1210_3225Metric; MPN 22u
C4: 47u; C_1210_3225Metric; MPN 47u
C6: 10u; C_0805_2012Metric; MPN 10u
C8, C11, C12: 1u; C_0603_1608Metric; MPN 1u
C14: 10n; C_0603_1608Metric; MPN 10n
C16: 5.6n; C_0603_1608Metric; MPN 5.6n
D1, D3: SS34; D_SMA; MPN SS34
D2: SMF5.0A; D_SOD-123F; MPN SMF5.0A
D4, D5: GREEN; LED_AA1608; MPN AA1608LCGSK
D6: RED; LED_AA1608; MPN AA1608LSURSK
D7: BLUE; LED_AA1608; MPN AA1608LQBS/D-295V
F1: 3A fuse; Fuse_1206_3216Metric; MPN 0467003.NR
J1: USB4105-GF-A; USB_C_Receptacle_GCT_USB4105-xx-A_16P_TopMnt_Horizontal; MPN USB4105-GF-A
J2: 1x12 2.54mm right-angle; PinHeader_1x12_P2.54mm_Horizontal; MPN 61301211021
L1: 4.7uH; SRP5030TA; MPN SRP5030TA-4R7M
Q1: AO3400A; SOT-23; MPN AO3400A
R1, R2: 5.1k; R_0603_1608Metric; MPN 5.1k
R3, R4: 22; R_0603_1608Metric; MPN 22
R5, R6, R9, R10, R12, R17: 10k; R_0603_1608Metric; MPN 10k
R7, R8: 26.1k; R_0603_1608Metric; MPN 26.1k
R11: 100; R_0603_1608Metric; MPN 100
R15: 33k; R_0603_1608Metric; MPN 33k
R16: 10.5k; R_0603_1608Metric; MPN 10.5k
R18: 10; R_0603_1608Metric; MPN 10
R19: 680; R_0603_1608Metric; MPN 680
R20, R21: 1.5k; R_0603_1608Metric; MPN 1.5k
R22: 330; R_0603_1608Metric; MPN 330
SW1: BOOT; SW_SPST_TS2435VS; MPN TS-2435VS
TP1: EN; TestPoint_Pad_D1.0mm; MPN PCB test pad
TP2: GND; TestPoint_Pad_D1.0mm; MPN PCB test pad
TP3: UART_TX; TestPoint_Pad_D1.0mm; MPN PCB test pad
TP4: V3V3; TestPoint_Pad_D1.0mm; MPN PCB test pad
TP5: FAULT4; TestPoint_Pad_D1.0mm; MPN PCB test pad
TP6: FAULT5; TestPoint_Pad_D1.0mm; MPN PCB test pad
U1, U10: USBLC6-2SC6; SOT-23-6; MPN USBLC6-2SC6
U2: SGM6232YPS8G/TR; SGM6232_SOIC8_EP; MPN SGM6232YPS8G/TR
U3: ESPC5-12-H4; MPN ESPC5-12-H4
U4, U5: TPS2553DDBVR; SOT-23-6; MPN TPS2553DDBVR
U6, U7: TPD4E05U06DQAR; TPD4E05U06_DQA; MPN TPD4E05U06DQAR

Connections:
BOOT: R6.2, SW1.1 (BOOT), U3.18 (GPIO28)
BOOT_R: C14.1, R18.2
BS: C14.2, U2.1 (BS)
BUZZ_GATE: Q1.1 (G), R11.2, R12.1
BUZZ_LOW: BZ1.2 (-), D3.2 (A), Q1.3 (D)
BUZZ_PWM: R11.1, U3.21 (GPIO12)
CC1: J1.A5 (CC1), R1.1
CC2: J1.B5 (CC2), R2.1
COMP: C16.1, U2.6 (COMP)
COMP_RC: C16.2, R17.1
D4_A: D4.2 (A), R19.2
D5_A: D5.2 (A), R20.2
D6_A: D6.2 (A), R21.2
D7_A: D7.2 (A), R22.2
EN: C8.1, R5.2, TP1.1, U3.3 (EN)
FAULT4: TP5.1, U3.17 (GPIO15), U4.4 (FAULT_N)
FAULT5: TP6.1, U3.5 (GPIO3), U5.4 (FAULT_N)
FB: R15.2, R16.1, U2.5 (FB)
GND: C1.2, C2.2, C3.2, C4.2, C5.2, C6.2, C7.2, C8.2, C9.2, C10.2, C11.2, C12.2, C13.2, C15.2, C21.2, D1.2 (A), D2.2 (A), D4.1 (K), D5.1 (K), D6.1 (K), D7.1 (K), J1.A1 (GND), J1.A12 (GND), J1.B1 (GND), J1.B12 (GND), J1.SH (SHIELD), J2.2, J2.4, Q1.2 (S), R1.2, R2.2, R7.2, R8.2, R9.2, R10.2, R12.2, R16.2, R17.2, SW1.2 (GND), TP2.1, U1.2 (GND), U2.4 (GND), U2.9 (EP_GND), U3.15 (GND), U3.23 (EPAD), U4.2 (GND), U5.2 (GND), U6.3 (GND), U6.8 (GND), U7.3 (GND), U7.8 (GND), U10.2 (GND)
ILIM4: R7.1, U4.5 (ILIM)
ILIM5: R8.1, U5.5 (ILIM)
IO0: J2.5, U3.12 (GPIO10), U6.1 (IO1)
IO1: J2.6, U3.2 (GPIO1), U6.2 (IO2)
IO2: J2.7, U3.1 (GPIO0), U6.4 (IO3)
IO3: J2.8, U3.4 (GPIO2), U6.5 (IO4)
IO4: J2.9, U3.6 (GPIO4), U7.1 (IO1)
IO5: J2.10, U3.7 (GPIO5), U7.2 (IO2)
IO6: J2.11, U3.16 (GPIO6), U7.4 (IO3)
IO7: J2.12, U3.9 (GPIO7), U7.5 (IO4)
MCU_DM: R3.2, U3.13 (GPIO13)
MCU_DP: R4.2, U3.14 (GPIO14)
PWR3_EN: R9.1, U3.10 (GPIO8), U4.3 (EN)
PWR5_EN: R10.1, U3.11 (GPIO9), U5.3 (EN)
SS: C15.1, U2.8 (SS)
STATUS_LED: R22.1, U3.20 (GPIO26)
SW: D1.1 (K), L1.1, R18.1, U2.3 (SW)
UART_TX: TP3.1, U3.22 (GPIO11)
USB_DM: J1.A7 (D-), J1.B7 (D-), R3.1, U1.1 (IO1), U1.6 (IO1)
USB_DP: J1.A6 (D+), J1.B6 (D+), R4.1, U1.3 (IO2), U1.4 (IO2)
V3V3: BZ1.1 (+), C4.1, C5.1, C6.1, C7.1, C9.1, C13.1, D3.1 (K), L1.2, R5.1, R6.1, R15.1, TP4.1, U3.8 (3V3), U4.1 (IN)
V3_SW: C11.1, J2.1, R19.1, U4.6 (OUT), U10.1 (IO1), U10.6 (IO1)
V5: C2.1, C3.1, C10.1, C21.1, D2.1 (K), F1.2, R21.1, U2.2 (IN), U5.1 (IN), U10.5 (VBUS)
V5_SW: C12.1, J2.3, R20.1, U5.6 (OUT), U10.3 (IO2), U10.4 (IO2)
VBUS: C1.1, F1.1, J1.A4 (VBUS), J1.A9 (VBUS), J1.B4 (VBUS), J1.B9 (VBUS), U1.5 (VBUS)

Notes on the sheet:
01 CONTROLLER / BOOT / RESET
02 USB-C / INPUT PROTECTION
03 SGM6232 / ALWAYS-ON 3.3 V
04 SWITCHED OUTPUTS / 1 A NOMINAL LIMIT
05 PASSIVE 5020 BUZZER
06 12-PIN MALE HEADER
07 HEADER ESD / SHUNT PROTECTION
U6/U7: four channels each; no supply or bypass needed.
IO0-IO7: 3.3 V only; final-board ESD test required.
U10: switched rails. Power current bypasses the array.
Place arrays and bypass capacitors directly beside J2.
Short, wide ground returns; qualify ESD on final PCB.
08 GROUPED STATUS INDICATORS
Blue: control pin 26, HIGH = on. 3V3/5V: switched rails.
48 x 28 mm PCB - LEDs top; eight resistors bottom.
Hold BOOT, then power on or short EN to GND.
SW1: TS-2435VS / side-push / front edge
Built-in PCB antenna over cutout; 3.3 V pins only.
5 V / 3 A supply. No PD or OTG. External loads OFF on PC USB.
EN open: auto-start. EP to GND. FB divider 33k / 10.5k = 3.314 V.
Fault inputs: firmware must enable internal pullups.
FAULT4 -> input 15; FAULT5 -> input 3. Active LOW.
26.1k ILIM: nominal 0.989 A; bounds 0.908-1.081 A.
4 kHz / 50% duty. GPIO12 reserved.
PROTOTYPE VALIDATION
Check startup, dropout, ripple, heat.
Use specified 5 V / 3 A adapter.
Verify current limit and both loaded rails.

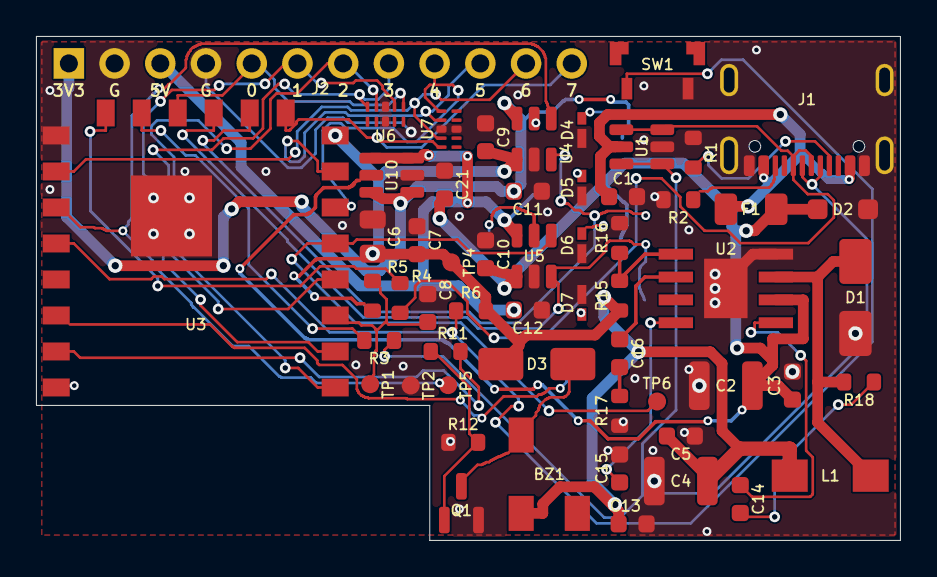
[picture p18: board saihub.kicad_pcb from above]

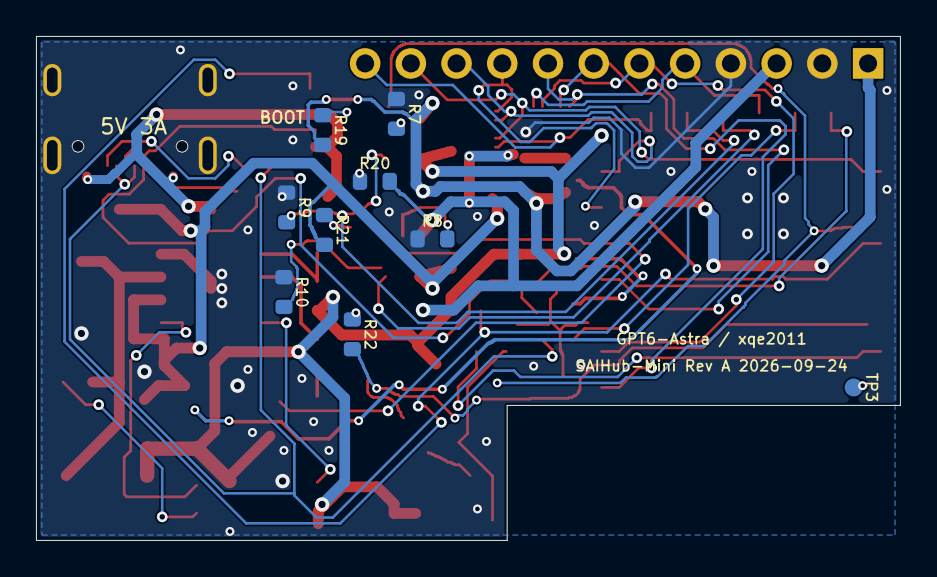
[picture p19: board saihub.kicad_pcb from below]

Board: 2 copper layers, 48.0 x 28.0 mm, 65 parts (9 on the bottom side), 44 nets.

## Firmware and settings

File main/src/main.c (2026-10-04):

#include "main.h"

#include "button.h"
#include "buzzer.h"
#include "cloud.h"
#include "gpio_ctrl.h"
#include "http_server.h"
#include "pwm_ctrl.h"
#include "lock.h"
#include "ntp.h"
#include "nvs.h"
#include "script.h"
#include "uart_ctrl.h"
#include "wifi.h"

#include <esp_log.h>
#include <freertos/FreeRTOS.h>
#include <freertos/task.h>

static const char* tag = "SAIHub-Main";

void app_main(void)
{
  bool someModuleFailed = false;
  MAIN_LOAD_MODULE(Nvs_Init(), "Nvs");
  MAIN_LOAD_MODULE(Cloud_Init(), "Cloud");
  MAIN_LOAD_MODULE(PwmCtrl_Init(), "Pwm");
  MAIN_LOAD_MODULE(GpioCtrl_Init(), "Gpio");
  MAIN_LOAD_MODULE(Buzzer_Init(), "Buzzer");
  MAIN_LOAD_MODULE(Lock_Init(), "Lock");
  MAIN_LOAD_MODULE(UartCtrl_Init(), "Uart");
  MAIN_LOAD_MODULE(Script_Init(), "Script");
  MAIN_LOAD_MODULE(Ntp_Init(), "Ntp");
  MAIN_LOAD_MODULE(HttpServer_Init(), "HttpServer");
  MAIN_LOAD_MODULE(Wifi_Init(), "Wifi");
  MAIN_LOAD_MODULE(Button_Init(), "Button");

  if (someModuleFailed) {
    ESP_LOGE(tag, "Some modules failed to initialize");
  }

  while (true) {
    Lock_SweepExpired();
    vTaskDelay(pdMS_TO_TICKS(1000));
  }
}

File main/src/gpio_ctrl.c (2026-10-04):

/**
 * @name GPIO control module
 * @file gpio_ctrl.c
 * @author xqe2011
 */
#include "gpio_ctrl.h"

#include "config.h"
#include "pwm_ctrl.h"
#include "tool.h"

#include <driver/gpio.h>
#include <esp_log.h>
#include <esp_rom_sys.h>
#include <esp_timer.h>
#include <freertos/FreeRTOS.h>
#include <freertos/task.h>
#include <math.h>
#include <string.h>
#include <sys/time.h>

static const char* tag = "SAIHub-Gpio";

typedef struct {
  GpioCtrl_Mode mode;
  bool openDrain;
  bool pullUp;
  bool pullDown;
  bool interruptActive;
  bool pwmActive;
  double pwmFrequencyHz;
  double pwmDutyPercent;
  int outputLevel; /* last gpio_set_level; GET uses this in digitalOutput */
} GpioPinRuntime;

typedef struct {
  GpioCtrl_Edge edge;
  GpioCtrl_TraceEvent* events;
  size_t capacity;
  volatile size_t count;
  bool includePin;
} TraceContext;

static int logicalToHw[] = CONFIG_GPIO_LOGICAL_TO_HW;
static GpioPinRuntime pins[TOOL_GET_ARRAY_LENGTH(logicalToHw)];
static bool powerEnable3v3 = false;
static bool powerEnable5v = false;
static TraceContext* traceOwners[TOOL_GET_ARRAY_LENGTH(logicalToHw)];
static portMUX_TYPE traceMux = portMUX_INITIALIZER_UNLOCKED;

bool GpioCtrl_IsValidLogicalPin(int pin)
{
  return pin >= 0 && pin < TOOL_GET_ARRAY_LENGTH(logicalToHw);
}

int GpioCtrl_GetLogicalCount(void)
{
  return TOOL_GET_ARRAY_LENGTH(logicalToHw);
}

static int GpioCtrl_Hw(int logicalPin)
{
  return logicalToHw[logicalPin];
}

int GpioCtrl_GetHwPin(int logicalPin)
{
  return GpioCtrl_Hw(logicalPin);
}

static int GpioCtrl_PowerHw(GpioCtrl_PowerRail rail)
{
  if (rail == GPIO_CTRL_POWER_3V3) return CONFIG_GPIO_POWER_3V3_PIN;
  return CONFIG_GPIO_POWER_5V_PIN;
}

const char* GpioCtrl_ModeToString(GpioCtrl_Mode mode)
{
  switch (mode) {
    case GPIO_CTRL_MODE_DISABLE:
      return "disable";
    case GPIO_CTRL_MODE_DIGITAL_INPUT:
      return "digitalInput";
    case GPIO_CTRL_MODE_DIGITAL_OUTPUT:
      return "digitalOutput";
    case GPIO_CTRL_MODE_DIGITAL_INPUT_OUTPUT:
      return "digitalInputOutput";
    case GPIO_CTRL_MODE_PWM_OUTPUT:
      return "pwmOutput";
    default:
      return "disable";
  }
}

bool GpioCtrl_ModeFromString(const char* s, GpioCtrl_Mode* out)
{
  if (s == NULL || out == NULL) return false;
  if (strcmp(s, "disable") == 0) {
    *out = GPIO_CTRL_MODE_DISABLE;
    return true;
  }
  if (strcmp(s, "digitalInput") == 0) {
    *out = GPIO_CTRL_MODE_DIGITAL_INPUT;
    return true;
  }
  if (strcmp(s, "digitalOutput") == 0) {
    *out = GPIO_CTRL_MODE_DIGITAL_OUTPUT;
    return true;
  }
  if (strcmp(s, "digitalInputOutput") == 0) {
    *out = GPIO_CTRL_MODE_DIGITAL_INPUT_OUTPUT;
    return true;
  }
  if (strcmp(s, "pwmOutput") == 0) {
    *out = GPIO_CTRL_MODE_PWM_OUTPUT;
    return true;
  }
  return false;
}

bool GpioCtrl_EdgeFromString(const char* s, GpioCtrl_Edge* out)
{
  if (s == NULL || out == NULL) return false;
  if (strcmp(s, "raising") == 0) {
    *out = GPIO_CTRL_EDGE_RAISING;
    return true;
  }
  if (strcmp(s, "falling") == 0) {
    *out = GPIO_CTRL_EDGE_FALLING;
    return true;
  }
  if (strcmp(s, "both") == 0) {
    *out = GPIO_CTRL_EDGE_BOTH;
    return true;
  }
  return false;
}

const char* GpioCtrl_EdgeToString(GpioCtrl_Edge edge)
{
  switch (edge) {
    case GPIO_CTRL_EDGE_RAISING:
      return "raising";
    case GPIO_CTRL_EDGE_FALLING:
      return "falling";
    case GPIO_CTRL_EDGE_BOTH:
      return "both";
    default:
      return "both";
  }
}

bool GpioCtrl_PowerRailFromString(const char* s, GpioCtrl_PowerRail* out)
{
  if (s == NULL || out == NULL) return false;
  if (strcmp(s, "3v3") == 0) {
    *out = GPIO_CTRL_POWER_3V3;
    return true;
  }
  if (strcmp(s, "5v") == 0) {
    *out = GPIO_CTRL_POWER_5V;
    return true;
  }
  return false;
}

const char* GpioCtrl_PowerRailToString(GpioCtrl_PowerRail rail)
{
  switch (rail) {
    case GPIO_CTRL_POWER_3V3:
      return "3v3";
    case GPIO_CTRL_POWER_5V:
      return "5v";
    default:
      return "3v3";
  }
}

static gpio_pull_mode_t GpioCtrl_ToPullMode(bool pullUp, bool pullDown)
{
  if (pullUp && pullDown) return GPIO_PULLUP_PULLDOWN;
  if (pullUp) return GPIO_PULLUP_ONLY;
  if (pullDown) return GPIO_PULLDOWN_ONLY;
  return GPIO_FLOATING;
}
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

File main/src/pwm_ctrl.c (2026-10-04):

/**
 * @name PWM control module
 * @file pwm_ctrl.c
 * @author xqe2011
 */
#include "pwm_ctrl.h"

#include "config.h"
#include "tool.h"

#include <driver/ledc.h>
#include <esp_log.h>
#include <math.h>
#include <string.h>

static const char* tag = "SAIHub-Pwm";

#define PWM_CTRL_LEDC_SPEED LEDC_LOW_SPEED_MODE
#define PWM_CTRL_LEDC_TIMER_COUNT SOC_LEDC_TIMER_NUM
#define PWM_CTRL_LEDC_CHANNEL_COUNT SOC_LEDC_TIMER_NUM
#define PWM_CTRL_LEDC_SRC_CLK_HZ 80000000U

_Static_assert(CONFIG_GPIO_PWM_MAX_OUTPUTS <= PWM_CTRL_LEDC_TIMER_COUNT,
               "Configured PWM output limit exceeds exclusive hardware timers");

typedef struct {
  bool inUse;
  uint32_t frequencyHz;
  uint32_t dutyResolution;
} LedcTimerSlot;

typedef struct {
  bool inUse;
  int hwPin;
  uint32_t frequencyHz;
  double dutyPercent;
  int ledcChannel;
  int ledcTimer;
} PwmCtrl_Slot;

static bool ready;
static bool ledcChannelInUse[PWM_CTRL_LEDC_CHANNEL_COUNT];
static LedcTimerSlot ledcTimers[PWM_CTRL_LEDC_TIMER_COUNT];
static PwmCtrl_Slot slots[CONFIG_GPIO_PWM_MAX_OUTPUTS];

static uint32_t PwmCtrl_LedcResolutionBits(uint32_t frequencyHz)
{
  return ledc_find_suitable_duty_resolution(PWM_CTRL_LEDC_SRC_CLK_HZ, frequencyHz);
}

static uint32_t PwmCtrl_DutyToTicks(double dutyPercent, uint32_t resolutionBits)
{
  uint32_t dutyMax = 1U << resolutionBits;
  if (dutyPercent <= 0.0) return 0;
  if (dutyPercent >= 100.0) return dutyMax;
  double ticks = (dutyPercent / 100.0) * (double)dutyMax;
  uint32_t rounded = (uint32_t)lround(ticks);
  if (rounded > dutyMax) rounded = dutyMax;
  return rounded;
}

static PwmCtrl_Slot* PwmCtrl_FindByHw(int hwPin)
{
  for (int i = 0; i < CONFIG_GPIO_PWM_MAX_OUTPUTS; i++) {
    if (slots[i].inUse && slots[i].hwPin == hwPin) return &slots[i];
  }
  return NULL;
}

static PwmCtrl_Slot* PwmCtrl_AllocSlot(int hwPin)
{
  for (int i = 0; i < CONFIG_GPIO_PWM_MAX_OUTPUTS; i++) {
    if (!slots[i].inUse) {
      memset(&slots[i], 0, sizeof(slots[i]));
      slots[i].inUse = true;
      slots[i].hwPin = hwPin;
      slots[i].ledcChannel = -1;
      slots[i].ledcTimer = -1;
      return &slots[i];
    }
  }
  return NULL;
}

static void PwmCtrl_FreeSlot(PwmCtrl_Slot* slot)
{
  if (slot == NULL) return;
  memset(slot, 0, sizeof(*slot));
  slot->ledcChannel = -1;
  slot->ledcTimer = -1;
}

static int PwmCtrl_AllocLedcChannel(void)
{
  for (int i = 0; i < PWM_CTRL_LEDC_CHANNEL_COUNT; i++) {
    if (!ledcChannelInUse[i]) {
      ledcChannelInUse[i] = true;
      return i;
    }
  }
  return -1;
}

static void PwmCtrl_FreeLedcChannel(int channel)
{
  if (channel >= 0 && channel < PWM_CTRL_LEDC_CHANNEL_COUNT) {
    ledcChannelInUse[channel] = false;
  }
}

static esp_err_t PwmCtrl_AcquireLedcTimer(uint32_t frequencyHz, int* timerOut)
{
  if (timerOut == NULL) return ESP_ERR_INVALID_ARG;
  uint32_t resolution = PwmCtrl_LedcResolutionBits(frequencyHz);
  if (resolution == 0) {
    ESP_LOGW(tag, "PWM cannot achieve %u Hz", (unsigned)frequencyHz);
    return ESP_ERR_NOT_SUPPORTED;
  }

  for (int i = 0; i < PWM_CTRL_LEDC_TIMER_COUNT; i++) {
    if (!ledcTimers[i].inUse) {
      ledc_timer_config_t cfg = {
          .speed_mode = PWM_CTRL_LEDC_SPEED,
          .duty_resolution = (ledc_timer_bit_t)resolution,
          .timer_num = (ledc_timer_t)i,
          .freq_hz = frequencyHz,
          .clk_cfg = LEDC_USE_PLL_DIV_CLK,
          .deconfigure = false,
      };
      if (ledc_timer_config(&cfg) != ESP_OK) return ESP_ERR_NOT_SUPPORTED;
      ledcTimers[i].inUse = true;
      ledcTimers[i].frequencyHz = frequencyHz;
      ledcTimers[i].dutyResolution = resolution;
      *timerOut = i;
      ESP_LOGI(tag, "PWM timer allocate: timer=%d frequency=%u resolution=%u", i, (unsigned)frequencyHz,
               (unsigned)resolution);
      return ESP_OK;
    }
  }
  return ESP_ERR_NO_MEM;
}

static void PwmCtrl_ReleaseLedcTimer(int timer)
{
  if (timer < 0 || timer >= PWM_CTRL_LEDC_TIMER_COUNT) return;
  if (!ledcTimers[timer].inUse) return;
  ESP_LOGI(tag, "PWM timer release: timer=%d frequency=%u", timer, (unsigned)ledcTimers[timer].frequencyHz);
  ledc_timer_pause(PWM_CTRL_LEDC_SPEED, (ledc_timer_t)timer);
  ledc_timer_config_t cfg = {
      .speed_mode = PWM_CTRL_LEDC_SPEED,
      .timer_num = (ledc_timer_t)timer,
      .deconfigure = true,
  };
  ledc_timer_config(&cfg);
  ledcTimers[timer].inUse = false;
  ledcTimers[timer].frequencyHz = 0;
  ledcTimers[timer].dutyResolution = 0;
}

static esp_err_t PwmCtrl_ReconfigureLedcTimer(int timer, uint32_t frequencyHz)
{
  if (timer < 0 || timer >= PWM_CTRL_LEDC_TIMER_COUNT || !ledcTimers[timer].inUse) return ESP_ERR_INVALID_STATE;
  uint32_t resolution = PwmCtrl_LedcResolutionBits(frequencyHz);
  if (resolution == 0) return ESP_ERR_NOT_SUPPORTED;

  ledc_timer_config_t cfg = {
      .speed_mode = PWM_CTRL_LEDC_SPEED,
      .duty_resolution = (ledc_timer_bit_t)resolution,
      .timer_num = (ledc_timer_t)timer,
      .freq_hz = frequencyHz,
      .clk_cfg = LEDC_USE_PLL_DIV_CLK,
      .deconfigure = false,
  };
  if (ledc_timer_config(&cfg) != ESP_OK) return ESP_ERR_NOT_SUPPORTED;
  ledcTimers[timer].frequencyHz = frequencyHz;
  ledcTimers[timer].dutyResolution = resolution;
  return ESP_OK;
}

static void PwmCtrl_DetachSlot(PwmCtrl_Slot* slot)
{
  if (slot->ledcChannel >= 0) {
    ledc_stop(PWM_CTRL_LEDC_SPEED, (ledc_channel_t)slot->ledcChannel, 0);
    PwmCtrl_FreeLedcChannel(slot->ledcChannel);
    slot->ledcChannel = -1;
  }
  if (slot->ledcTimer >= 0) {
    PwmCtrl_ReleaseLedcTimer(slot->ledcTimer);
    slot->ledcTimer = -1;
  }
}

static esp_err_t PwmCtrl_AttachSlot(PwmCtrl_Slot* slot, int hwPin, uint32_t frequencyHz, double dutyPercent)
{
  int channel = PwmCtrl_AllocLedcChannel();
  if (channel < 0) return ESP_ERR_NO_MEM;
  int timer = -1;
  esp_err_t terr = PwmCtrl_AcquireLedcTimer(frequencyHz, &timer);
  if (terr != ESP_OK) {
    PwmCtrl_FreeLedcChannel(channel);
    return terr;
  }

  ledc_channel_config_t ch = {
      .gpio_num = hwPin,
      .speed_mode = PWM_CTRL_LEDC_SPEED,
      .channel = (ledc_channel_t)channel,
      .intr_type = LEDC_INTR_DISABLE,
      .timer_sel = (ledc_timer_t)timer,
      .duty = PwmCtrl_DutyToTicks(dutyPercent, ledcTimers[timer].dutyResolution),
      .hpoint = 0,
      .flags = {.output_invert = 0},
  };
  esp_err_t err = ledc_channel_config(&ch);
  if (err != ESP_OK) {
    PwmCtrl_ReleaseLedcTimer(timer);
    PwmCtrl_FreeLedcChannel(channel);
    return err;
  }

  slot->ledcChannel = channel;
  slot->ledcTimer = timer;
  slot->frequencyHz = frequencyHz;
  slot->dutyPercent = dutyPercent;
  ESP_LOGI(tag, "PWM attach: gpio=%d channel=%d timer=%d frequency=%u", hwPin, channel, timer, (unsigned)frequencyHz);
  return ESP_OK;
}
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

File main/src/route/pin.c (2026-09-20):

/**
 * @name Pin routes
 * @file pin.c
 * @author xqe2011
 */
#include "route.h"

#include "config.h"
#include "gpio_ctrl.h"
#include "http_server.h"
#include "lock.h"
#include "tool.h"

#include <cJSON.h>
#include <esp_log.h>
#include <stdio.h>
#include <stdlib.h>
#include <string.h>
#include <freertos/FreeRTOS.h>
#include <freertos/task.h>

static const char* tag = "SAIHub-Http";

#define TRACE_DEFAULT_DURATION_US 1000000ULL

static const int pinLogicalToHw[] = CONFIG_GPIO_LOGICAL_TO_HW;
/* Parse GET query parameters used by batch read endpoints.  Repeated pins
 * (pins=1&pins=2) and comma-separated pins (pins=1,2) are both accepted. */
static cJSON* Route_PinQueryObject(HttpServer_Context* ctx)
{
  char query[256] = {0};
  if (HttpServer_GetQuery(ctx, query, sizeof(query)) != ESP_OK) return NULL;
  cJSON* root = cJSON_CreateObject();
  cJSON* pins = cJSON_CreateArray();
  char* save = NULL;
  for (char* part = strtok_r(query, "&", &save); part; part = strtok_r(NULL, "&", &save)) {
    char* eq = strchr(part, '='); if (!eq) continue; *eq++ = '\0';
    if (strcmp(part, "pins") == 0) {
      char* ps = NULL;
      for (char* v = strtok_r(eq, ",", &ps); v; v = strtok_r(NULL, ",", &ps)) cJSON_AddItemToArray(pins, cJSON_CreateNumber(strtol(v, NULL, 10)));
    } else if (strcmp(part, "edge") == 0) cJSON_AddStringToObject(root, "edge", eq);
    else if (strcmp(part, "duration") == 0) cJSON_AddNumberToObject(root, "duration", strtoull(eq, NULL, 10));
  }
  cJSON_AddItemToObject(root, "pins", pins);
  return root;
}
static esp_err_t Route_PinSendTraceEvents(HttpServer_Context* ctx, const GpioCtrl_TraceEvent* events, size_t count, bool includePin);

typedef struct { HttpServer_Context* ctx; int* pins; size_t pinCount; GpioCtrl_Edge edge; uint64_t duration; bool includePin; char lockId[64]; } PinTraceJob;
static void Route_PinTraceTask(void* arg) {
  PinTraceJob* j = arg; GpioCtrl_TraceEvent* ev = calloc(CONFIG_GPIO_TRACE_MAX_EVENTS, sizeof(*ev)); size_t n=0;
  esp_err_t r = ev ? GpioCtrl_Trace(j->pins,j->pinCount,j->edge,j->duration,ev,CONFIG_GPIO_TRACE_MAX_EVENTS,&n,j->includePin) : ESP_ERR_NO_MEM;
  if (r == ESP_OK) { Lock_Touch(j->lockId[0] ? j->lockId : NULL); Route_PinSendTraceEvents(j->ctx,ev,n,j->includePin); }
  else if (r == GPIO_CTRL_ERR_TRACE_BUSY) HttpServer_SendError(j->ctx,409,"One or more pins already have an active trace request.");
  else HttpServer_SendError(j->ctx,500,"internal");
  free(ev); free(j->pins); HttpServer_AsyncComplete(j->ctx); free(j); vTaskDelete(NULL);
}
static esp_err_t Route_PinStartTrace(HttpServer_Context* ctx,const int* pins,size_t count,GpioCtrl_Edge edge,uint64_t duration,bool includePin,const char* lockId) {
  PinTraceJob* j=calloc(1,sizeof(*j)); if(!j) return HttpServer_SendError(ctx,500,"internal");
  j->pins=malloc(count*sizeof(int)); if(!j->pins){free(j);return HttpServer_SendError(ctx,500,"internal");} memcpy(j->pins,pins,count*sizeof(int)); j->pinCount=count;j->edge=edge;j->duration=duration;j->includePin=includePin; snprintf(j->lockId,sizeof(j->lockId),"%s",lockId?lockId:"");
  if(HttpServer_AsyncBegin(ctx,&j->ctx)!=ESP_OK){free(j->pins);free(j);return HttpServer_SendError(ctx,500,"internal");}
  if(xTaskCreate(Route_PinTraceTask,"pin_trace",4096,j,5,NULL)!=pdPASS){ HttpServer_SendError(j->ctx,500,"internal"); HttpServer_AsyncComplete(j->ctx); free(j->pins); free(j); return ESP_OK; } return ESP_OK;
}

static esp_err_t Route_PinSendTraceEvents(HttpServer_Context* ctx, const GpioCtrl_TraceEvent* events, size_t count, bool includePin)
{
  esp_err_t ret = HttpServer_SendChunkBegin(ctx, 200, "application/json", NULL);
  if (ret == ESP_OK) ret = HttpServer_SendChunk(ctx, "{\"events\":[", sizeof("{\"events\":[") - 1);
  char item[128];
  for (size_t i = 0; ret == ESP_OK && i < count; i++) {
    int len = includePin
                  ? snprintf(item, sizeof(item), "%s{\"pin\":%d,\"edge\":\"%s\",\"level\":%d,\"time\":%lld}",
                             i == 0 ? "" : ",", events[i].pin, events[i].edge, events[i].level,
                             (long long)events[i].time)
                  : snprintf(item, sizeof(item), "%s{\"edge\":\"%s\",\"level\":%d,\"time\":%lld}",
                             i == 0 ? "" : ",", events[i].edge, events[i].level, (long long)events[i].time);
    if (len < 0 || (size_t)len >= sizeof(item)) {
      ret = ESP_ERR_INVALID_SIZE;
      break;
    }
    ret = HttpServer_SendChunk(ctx, item, (size_t)len);
  }
  if (ret == ESP_OK) ret = HttpServer_SendChunk(ctx, "]}", 2);
  esp_err_t endRet = HttpServer_SendChunkDone(ctx);
  ESP_LOGI(tag, "Resp rest/%s %s %s -> 200 trace_events=%u", HttpServer_GetFrom(ctx), HttpServer_MethodName(HttpServer_GetMethod(ctx)), HttpServer_GetUri(ctx), (unsigned)count);
  return ret == ESP_OK ? endRet : ret;
}
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

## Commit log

2026-09-13 Split HTTP routes and add lockable power rails.
    Fold JSON helpers into HttpServer, use Route_ modules under route/, and expose GET/POST /power/3v3 and /power/5v with shared lock support.
2026-09-13 Add pin PWM API with singular /pin and /lock routes.
    Replace gpio_config with gpio_* pad sync and LEDC PWM so mode/pull/openDrain survive attach, and expose digital modes plus GET/POST /pin/{n}/pwm.
    [config.h, gpio_ctrl.c, http_server.c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]
2026-09-13 Add MCP Streamable HTTP on /mcp and CORS for all APIs.
    Expose pin/power/lock tools over JSON-RPC and apply shared CORS plus OPTIONS preflight across the HTTP surface.
2026-09-13 Pick PWM duty resolution per frequency and stop fighting the pad.
    Use enable/disable instead of direction, keep open-drain after PWM attach, and return the last written latch for digitalOutput reads.
2026-09-13 Parse and serialize typed lock resources in one place.
    REST create_lock now takes type pin+pins or type power+rails instead of per-item pin/power fields.
2026-09-13 Use plural MCP pin tools and typed lock groups.
    Always take pins arrays, size pin lists from the logical map, and keep OpenAPI/MCP copy in product terms.
2026-09-13 Keep chip and SDK terms out of user-facing copy.
    Agents should describe pins, PWM, and resources instead of silicon internals.
2026-09-14 Add MCP JSON schema and update CMakeLists to include mcp.json
    Introduced a new mcp.json file defining pin configurations, modes, and tools for managing GPIO pins. Updated CMakeLists.txt to embed the new mcp.json file. Increased CONFIG_LOCK_MAX_COUNT and CONFIG_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
2026-09-14 Add on-device Lua scripts and share pin/power/lock tools between MCP and REST.
    Give agents a sandboxed run_script path and flatten HTTP errors to {reason} so nested tool calls do not have to round-trip the host.
    [config.h, http_server.c, main.c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]
2026-09-14 Return 422 for POST /script runtime failures instead of 400/408.
    Uncaught tool errors keep the same wrapped reason as Lua failures so clients can treat timeout, limits, error(), and tools uniformly.
    [http_server.c, script.c, tool_call.c]
2026-09-14 Document Lua 5.4 sandbox, examples, and error handling for on-device scripts.
    Give MCP and REST agents enough contract to write tools, catch {reason}, and distinguish abort cases.
2026-09-14 WiFi pairing mode with SoftAP portal and logical pin 0 → HW 10 (#1)
    * Add button-triggered Wi-Fi pairing portal with APSTA and gzipped UI.
    Map logical pin 0 to HW 10 and reserve HW 0 for the pairing button. SoftAP
    SSID SAIHUB-<mac> serves an async connect/status portal so channel switches
    do not drop the connect response; STA IP is returned on success.
    * Rename CONFIG_GPIO_BUTTON_PIN to CONFIG_BUTTON_PIN.
    * Restyle pairing portal with Material Design and fix overflow.
    Stack the password field and Connect button full-width, use MD3 surfaces,
    tonal list selection, and floating labels so the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
    [button.c, config.h, http_server.c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]
2026-09-14 Log tool calls from MCP, Lua, and REST, and fix pairing reconnect.
    Ignore the expected STA disconnect when leaving the previous AP, stop SNTP before reconfiguring after reconnect, and use the IDF basename for the portal embed symbols.
    [http_server.c, lock.c, mcp.c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]
2026-09-14 Add DNS hijacking for captive portal and update Wi-Fi configuration
    - Introduced DNS hijacking functionality to support captive portal for Wi-Fi pairing.
    - Added new `dns.h` and `dns.c` files for DNS handling.
    - Updated `config.h` to include a new portal URL.
    - Enhanced `wifi.c` to apply DHCP settings for the captive portal and start the DNS service during pairing.
    - Added a new route for redirecting requests to the Wi-Fi page.
    - Removed redundant redirect functions in `portal.c` to streamline the code.
    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
2026-09-15 Add human control UI at / for pins and power rails.
    Serve a Material-styled page for browsers, point agents at /openapi.json, fix mid-path URI matching so /pin/*/pwm and /pin/*/level work, and show errors in a snackbar on both control and Wi-Fi pages.
    [http_server.c]
2026-09-15 Add UART REST/MCP API with peripheral pin locks.
    Enable UART 0 over /uart with config, transmit, receive, and flush, claim RX/TX pins via no-TTL peripheral locks, and expose a UART tab on the control page.
2026-09-15 Remove UART driver dependency from CMakeLists.txt and streamline component registration for improved build configuration.
2026-09-16 Add Cloudflare Worker device proxy with Durable Object auth and e2e tests.
2026-09-16 Add cloud pairing OAuth flow with A256GCM routing tokens and MCP discovery.
2026-09-16 Add conflict response handling to OpenAPI and update test configurations
    - Added 409 Conflict response to OpenAPI specifications for relevant endpoints.
    - Enhanced the description of the Conflict response for clarity.
    - Updated `package.json` to include a new hardware test script.
    - Modified `tsconfig.json` to include hardware test files in the compilation.
    - Changed button pin configuration in `config.h` for improved functionality.
    - Introduced new trace handling structures and functions in GPIO control files.
    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
2026-09-18 Add SAIHub-Mini Rev A hardware baseline
    [bom.csv, parts-placement.csv, saihub-prerouted.kicad_pcb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]
2026-09-19 Limit concurrent PWM outputs to four
    Enforce the product-level output cap and align resource smoke coverage and client errors with the simplified design.
    [config.h, gpio_ctrl.c, pin.c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]
2026-09-19 Make PWM timers exclusive per output
    Give each active PWM its own timer and isolate smoke-test sections so earlier hardware failures cannot leak resources into later checks.
    [gpio_ctrl.c]
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2026-09-19 feat: enforce JSON relay protocol
    Validate JSON content negotiation across the cloud relay and device transport, and add fragmented-device coverage.
2026-09-20 refactor: streamline cloud request handling
    Remove the asynchronous request handling in the cloud relay, simplifying the dispatch process to be synchronous. This change eliminates the need for a semaphore managing request slots, reducing compl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
2026-09-20 feat: enhance batch read and edge capture endpoints
    Add support for query parameters in batch read and edge capture operations, allowing multiple pin numbers to be specified. Update request handling to accept these parameters directly in the query str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
2026-09-20 feat: implement headroom management for device requests
    Introduce a headroom mechanism in the Device class to manage pending requests, limiting concurrent requests to a maximum of eight. This change ensures that requests are processed in a FIFO manner and allows for timeouts to free up slots for queued requests. Additionally, update the test suite to validate the new headroom functionality and its behavior under various conditions, including send failures and disconnections.
    [http_server.c]
2026-09-20 feat: implement heartbeat mechanism for device connections
    Introduce a heartbeat mechanism in the Device class to maintain active WebSocket connections, ensuring they are validated and closed if inactive for more than 33 seconds. This change enhances connect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
2026-09-21 fix: return 404 for unknown HTTP paths
    Catch-all CORS OPTIONS made every missing URI look registered, so httpd
    answered 405. CORS preflight is 204; a registered path with the wrong
    method is still 405.
    [http_server.c]
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2026-09-21 Group matching BOM components and total quantities
    [bom.csv]
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2026-09-22 docs: simplify Cloudflare relay deploy via Deploy to Cloudflare button
    Point cookbook and build docs at one-click Worker provisioning, add binding metadata and .dev.vars.example, and drop MCP screenshot placeholders.
2026-09-22 docs: point managed cloud at saihub.xqe2011.com
    Replace placeholder managed-cloud origins in README/cookbook and set the firmware default cloud URL to the production relay.
    [config.h]
2026-09-22 chore: pin flash layout and sdkconfig defaults for fresh clones
    Use a custom 2M app partition table and keep project Kconfig overrides in sdkconfig.defaults so builds do not depend on a local generated sdkconfig.
    [partitions.csv]
2026-09-22 fix: accept Cloudflare cross-signed TLS roots on the board (#3)
    * chore: regenerate bun.lock against the public npm registry
    The lockfile pinned packages to a private mirror that CI and other clones cannot reach.
    * fix: accept Cloudflare cross-signed TLS roots on the board
    Cloudflare edge certs chain through a cross-signed GTS root that the
    default CA bundle misses without CROSS_SIGNED_VERIFY; also pin the
    deployed D1 database id in wrangler.
    * revert: keep placeholder D1 database_id out of the TLS fix
    ---------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
2026-09-25 feat(hardware): add header protection and refresh board deliverables (#5)
    * docs: note that SAIHub-Mini hardware is experimental
    * feat(hardware): add header protection and refresh board deliverables
    ---------
    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
    [bom.csv, parts-placement.csv, saihub-prerouted.kicad_pcb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]
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2026-09-29 feat: add onboard buzzer with Morse-style play API (#7)
    * feat: add onboard buzzer with Morse-style play API
    Expose play_buzzer over REST, MCP, scripts, and the control UI, and beep during Wi-Fi/cloud pairing.
    * fix: play buzzer asynchronously on REST and MCP
    Keep long Morse sequences off the HTTP worker so concurrent requests stay responsive while play still blocks until completion for the caller.
    * refactor: derive buzzer Morse timings from WPM
    Replace fixed dit/dah/gap microseconds with PARIS standard units from CONFIG_BUZZER_WPM so cadence stays consistent when adjusting speed.
    Co-auth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
    [buzzer.c, config.h, http_server.c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]
2026-10-04 Replace button and add corner antenna module without enlarging PCB
    [bom.csv, parts-placement.csv, saihub-prerouted.kicad_pcb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]
2026-10-04 feat(hardware): add grouped indicators and reproducible routing
    [bom.csv, parts-placement.csv, saihub-unrouted.kicad_pcb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]
2026-10-04 feat(hardware): add enclosure and synchronized review exports
    [assembly.step, base.step, base.stl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]
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2026-10-28 fix: normalize detected chip name when picking flash firmware (#14)
    loader.main() returns a description like "ESP32-C5 (revision v…)", which
    did not match release assets named saihub-esp32c5-merged.bin. Prefer
    CHIP_NAME and normalize by lowercasing and stripping "-" (and revision
    text) before lookup.
2026-11-03 feat: SPI control, hex payloads, packed traces, and script event views (#17)
    * feat: add SPI master/slave control with MCP and OpenAPI routes
    * feat: stream SPI MCP responses and tighten pair coverage
    * feat: pack pin-trace events with relative timestamps
    * feat: encode SPI and UART binary payloads as hex strings
    * feat: pack script event views and shrink Lua heap
    * chore: free WiFi IRAM and log heap every 5s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
2026-11-06 fix: disable Wi-Fi driver NVS so saved networks stay app-owned (#23)
2026-11-08 fix: avoid wall-clock locks in GPIO interrupts (#24)
2026-11-08 fix: require type object on SPI/I2C MCP configure schemas (#25)
    MCP clients reject tool inputSchema rooted at oneOf without type:object.
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2026-11-13 System optimization, reboot APIs, and flasher release manifest (#27)
    * fix: resolve Wi-Fi pairing conflicts and simplify portal feedback
    * fix: silence automatic Wi-Fi pairing startup
    * feat: expose CPU and heap stats in system info
    Add live CPU usage and free-heap bytes to GET /system and get_system_info, show them in About with manual OTA check and tab deep links, and cover the fields in hardware smoke.
    * test: validate MCP tool schemas with a real client
    * feat: add system reboot APIs and control page button
    * feat: serve flasher releases from a static manifest
    Avoid GitHub API rate limits on the flash page, rename OTA artifacts clea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
